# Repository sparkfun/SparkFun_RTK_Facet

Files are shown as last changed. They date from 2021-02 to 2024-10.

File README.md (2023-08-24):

SparkFun RTK Facet
========================================

<table class="table table-hover table-striped table-bordered">
  <tr align="center">
   <td></td>
   <td></td>
  <tr align="center">
    <td><a href="https://www.sparkfun.com/products/20000">SparkFun RTK Facet L-Band (GPS-20000)</a></td>
    <td><a href="https://www.sparkfun.com/products/19029">SparkFun RTK Facet (GPS-19029)</a></td>
  </tr>
</table>

The SparkFun RTK Facet and RTK Facet L-Band are your one stop shop for high precision geolocation and surveying needs. For basic users, it’s incredibly easy to get up and running and for advanced users, the RTK Facet is a flexible and powerful tool. With just a few minutes of setup, the RTK Facet is one of the fastest ways to take centimeter grade measurements. By connecting your phone to the RTK Facet over Bluetooth, your phone can act as the radio link to provide correction data as well as receive the NMEA output from the device. This is exactly how $10,000 surveying devices have been operating for the past decade - we just made it easier, smaller, and a lot cheaper. 

The RTK Facet L-Band utilizes corrections from u-blox's PointPerfect service broadcast from a geosynchronous Inmarsat satellite. The only setup required is a WiFi SSID and password. Once entered, the device will provision itself and periodically (once a month) update the decryption keys necessary to use the PointPerfect service. The price of the RTK Facet L-Band includes a 12-month subscription. Additional years of service can be purchased.

Under the hood of the SparkFun RTK Facet is an ESP32 WROOM connected to a ZED-F9P as well as some peripheral hardware (OLED, LiPo fuel gauge, microSD, etc). Additionally, housed under the dome of the RTK Facet is a surveyor grade L1/L2 antenna. It is the same element found within our GNSS Multi-Band L1/L2 Surveying Antenna.

Under the hood of the SparkFun RTK Facet L-Band is an ESP32 WROOM connected to a ZED-F9P GNSS receiver, a NEO-D9S L-Band receiver (for corrections), and a variety of peripheral hardware (LiPo fuel gauge, microSD, etc). Additionally, housed under the dome of the RTK Facet L-Band is a surveyor grade L1/L2/L-Band antenna. This antenna is a unique combination of elements designed to receive the GNSS signals (L1/L2) alongside the 1.55GHz PointPerfect corrections. The built-in antenna has an ARP of 69mm from the base to the measuring point of the L1 antenna and an ARP of 68mm to the measuring point of the L2 antenna. The RTK Facet L-Band is programmed in Arduino and can be tailored by you to fit whatever your needs may be.

Repository Contents
-------------------

* **/Documents** - Datasheets and additional product information
* **/Hardware** - Eagle PCB files
* **/Labels** - Display overlay and info stickers
* **/Mechanical** - Drawings use to created injection molding tooling

Documentation
--------------

* **[RTK Product Manual](https://docs.sparkfun.com/SparkFun_RTK_Firmware/)** - A detailed guide describing all the various software features of the RTK product line. Essentially it is a manual for the firmware used by the RTK Facet.
* **[RTK Facet L-Band Hookup Guide](https://learn.sparkfun.com/tutorials/sparkfun-rtk-facet-l-band-hookup-guide)** - Hookup guide for the SparkFun RTK Facet L-Band.
* **[RTK Facet Hookup Guide](https://learn.sparkfun.com/tutorials/sparkfun-rtk-facet-hookup-guide)** - Hookup guide for the SparkFun RTK Facet.

License Information
-------------------

This product is _**open source**_! 

Please review the LICENSE.md file for license information. 

If you have any questions or concerns on licensing, please contact technical support on our [SparkFun forums](https://forum.sparkfun.com/viewforum.php?f=152).

Distributed as-is; no warranty is given.

- Your friends at SparkFun.

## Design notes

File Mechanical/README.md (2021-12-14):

## RTK Facet Mechanical Files ##

Contents
-------------------

* **/Drawings** - PDF Mechanical Drawings 
* **/Meshes** - STL and 3MF meshes for enclosure components
* **/Solids** - STEP and IGES solids for enclosure components
* **RTK_Facet_v35_Fusion_360_Archive.f3z** - Archive of the Fusion 360 project for the complete assembly as of v35 (initial release)

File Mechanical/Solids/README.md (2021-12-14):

## RTK Facet Solid Files ##

Contents
-------------------

* **Enclosure_Body** - Base portion of the clamshell enclosure. Injection Molded PA66.
* **Enclosure_Dome** - Lid portion of the clamshell enclosure. Injection Molded PA66.
* **Sock** - Shock/Dust Jacket for enclosure. Pressure Molded Silicone.
* **Thread_Insert** - 5/8-11 Threaded Insert. Machined Brass, Molded in place.

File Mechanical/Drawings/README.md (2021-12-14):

## RTK Facet Mechanical Drawings ##

Contents
-------------------

* **Thread_Insert.pdf** - 5/8-11 Threaded Brass Insert 
* **v35_Complete_Assembly.pdf** - Mechanical Drawings provided to Injection Molding Fab
* **v35_Critical_Dimensions_Nylon.pdf** - Critical Dimensions for PA66 Enclosure Parts
* **v35_Critical_Dimensions_Silicone.pdf** - Critical Dimensions for Silicone Sleeve

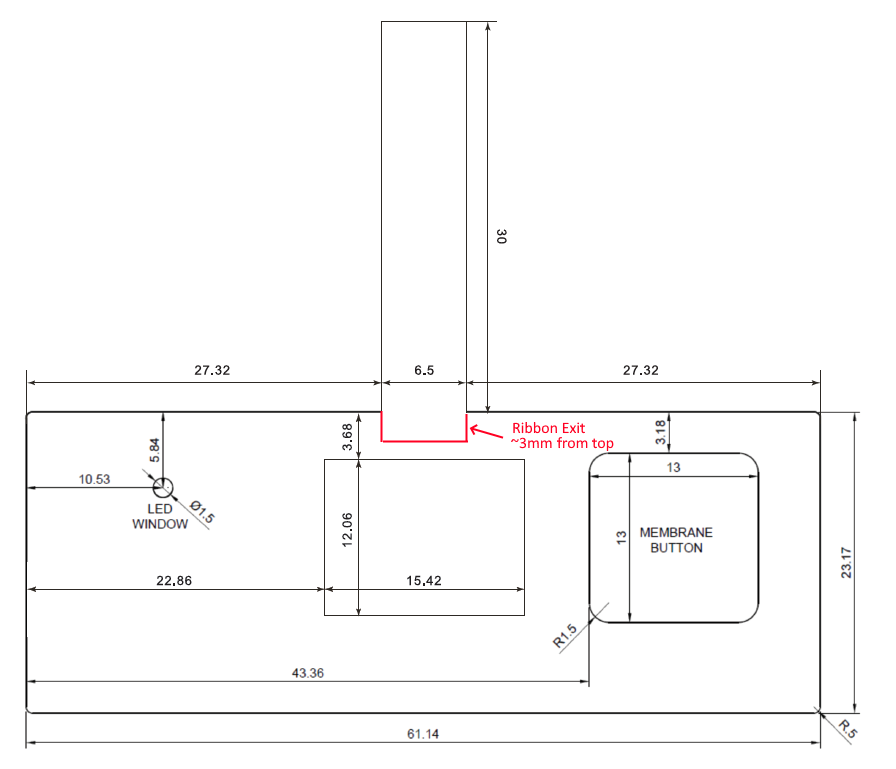
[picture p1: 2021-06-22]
Labels/Display/Ribbon Exit.png

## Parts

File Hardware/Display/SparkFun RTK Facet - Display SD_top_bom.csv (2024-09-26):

Comment | Designator | Footprint | LCSC Part #
OLED0.66-TRIMTRIM | OLED1 | OLED-0.66-64X48-TRIM | C88334
0.1uF | C16 C28 | 603 | C1590
1.0uF | C2 C3 | 805 | C15849
1.0uF | C4 C6 C7 | 603 | C1592
1k | R5 | 603 | C22548
2.2uF | C1 | 805 | C19110
4.7uF | C5 | 1206 | C51205
10k | R2 R3 | 603 | C98220
10uF | C8 | 603 | C19702
100k | R4 | 603 | C14675
390k | R1 | 603 | C863775
FPC_12_0.5MM_BACKFLIP | J1 | FPC_12_DOUBLESIDED_BACKFLIP | C5213751
Green | D1 | LED-1206-BOTTOM | C125106
MICRO-SD-PUSH-PUSH-EXT-PIN | J2 | MICROSD-EXTERNALPIN | C720505
MOMENTARY-SWITCH-SPST-SMD-5.2MM-TALL | S1 | TACTILE_SWITCH_SMD_5.2MM | C318887
6P_1MM-LIF Connector | JP1 | 6P_1MM-LIF Connector | C2915488

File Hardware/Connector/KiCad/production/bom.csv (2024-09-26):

Designator | Footprint | Quantity | Value | LCSC Part #
D1 | SOT23-6 | 1 | DT1042-04SO
F1 | 0805 | 1 | 6V/0.5A/1A
F3 | 1210 | 1 | 6V/2.0A/4.0A
J1, J3 | FPC_0.5mm-12 | 2 | Conn_01x12_FPC_0.5mm
J11, J12 | 1x04 | 2 | Conn_01x04
J2, J9 | JST_SMD_1.25mm-4_Locking | 2 | JST_Locking_4
J4 | JST_SMD_1.0mm-4_RA | 1 | Qwiic
J5 | USB-C_16 | 1 | USB_C_Receptacle
JP0 | Jumper_2_PTH_SMD_Combo-NC | 1 | Measure
R16, R17 | 0603 | 2 | 5.1k

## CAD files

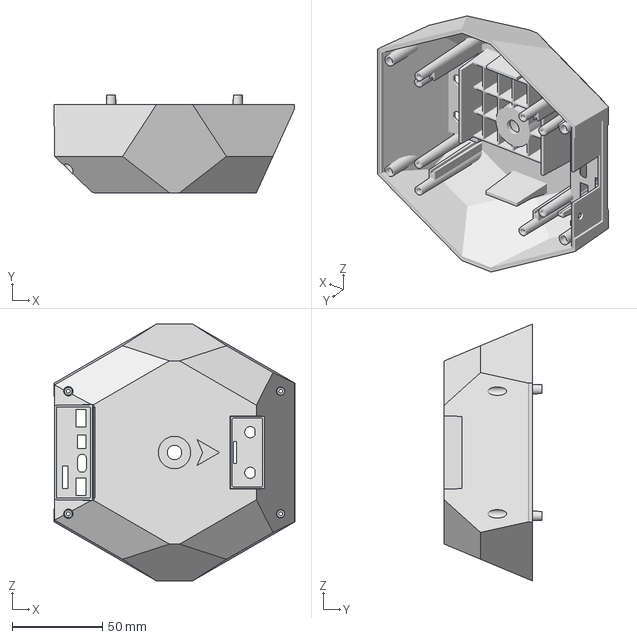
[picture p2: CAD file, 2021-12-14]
Mechanical/Meshes/Enclosure_Body.3mf
133.3 x 54.1 x 142.5 mm

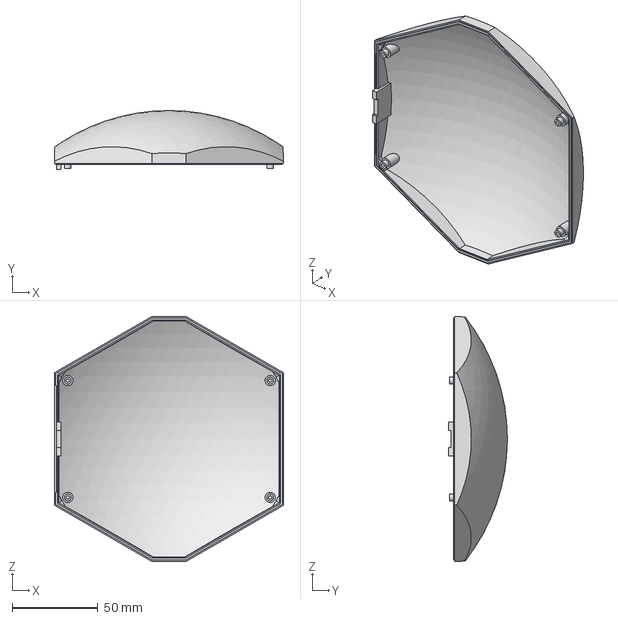
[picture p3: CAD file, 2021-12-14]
Mechanical/Solids/Enclosure_Dome.step
133.3 x 34.3 x 142.5 mm

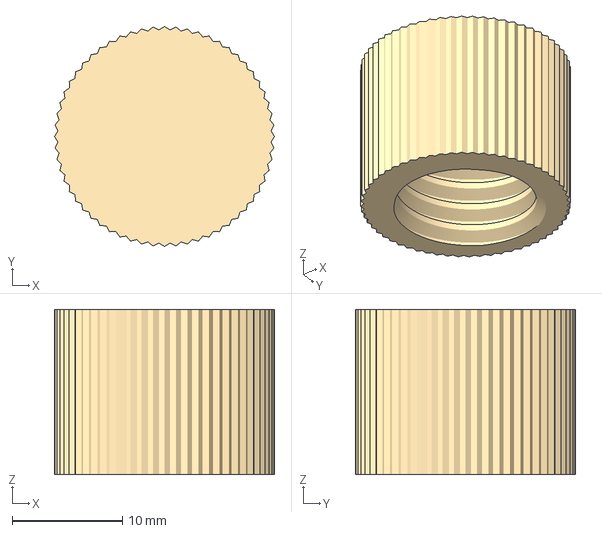
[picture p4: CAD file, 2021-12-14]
Mechanical/Meshes/Thread_Insert.3mf
20.0 x 20.0 x 15.0 mm

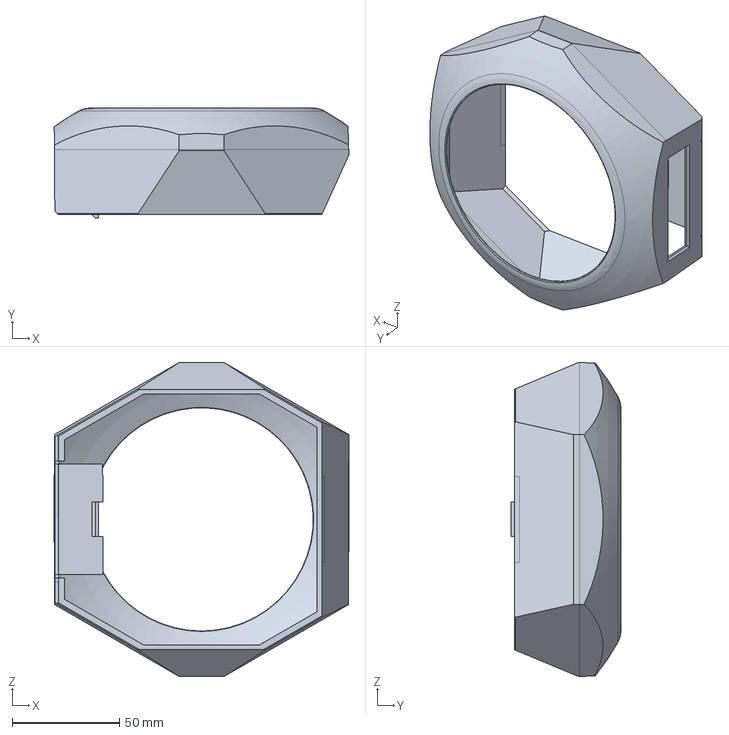
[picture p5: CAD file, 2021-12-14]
Mechanical/Solids/Sock.step
137.2 x 51.1 x 146.3 mm

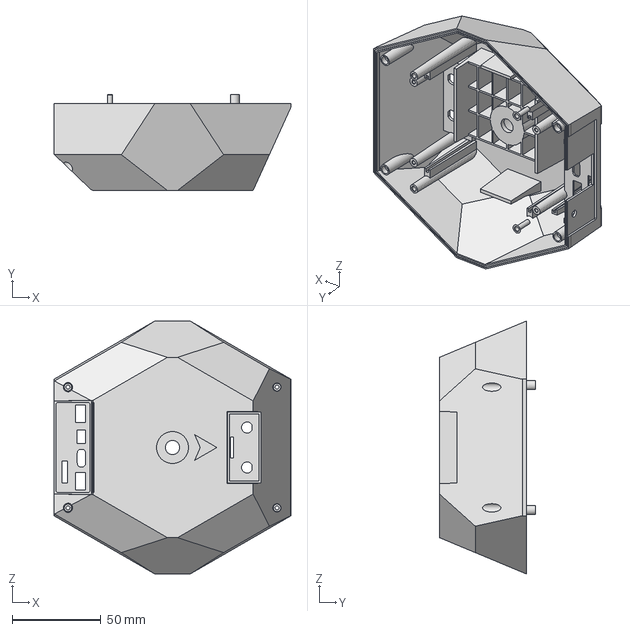
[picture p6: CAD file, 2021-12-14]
Mechanical/Solids/Enclosure_Body.step
133.3 x 54.1 x 142.5 mm

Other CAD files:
Mechanical/Meshes/Sock.3mf
Mechanical/Solids/Thread_Insert.step
Mechanical/Meshes/Enclosure_Dome.3mf
Mechanical/Meshes/Enclosure_Body.stl
Mechanical/Meshes/Enclosure_Dome.stl
Mechanical/Meshes/Sock.stl
Mechanical/Meshes/Thread_Insert.stl
Mechanical/Solids/Enclosure_Body.iges
Mechanical/Solids/Enclosure_Dome.iges
Mechanical/Solids/Sock.iges
Mechanical/Solids/Thread_Insert.iges

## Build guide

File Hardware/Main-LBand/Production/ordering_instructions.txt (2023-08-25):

panel size, 134x188mm
PCB thickness, 1.6mm
number of layers, 4
controlled impedance, JLC7628
material, TG155
soldermask color, Red
silkscreen color, White
oz copper, 1oz
finish, ENIG
stencils, none
pcs per panel, 8
min trace width, 0.1270mm / 0.0050in
min drill size, 0.2000mm / 0.0079in
filename to layer stackup 1/2/3/4: GTL, GL2, GL3, GBL

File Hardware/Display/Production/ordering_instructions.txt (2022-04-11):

panel size, 114x194mm
PCB thickness, 1.6mm
number of layers, 2
soldermask color, Red
silkscreen color, White
oz copper, 1oz
finish, ENIG
stencils, none
pcs per panel, 16
min trace width, 0.1778mm / 0.0070in
min drill size, 0.3810mm / 0.0150in

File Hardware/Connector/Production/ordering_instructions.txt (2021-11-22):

panel size, 121x199mm
PCB thickness, 1.6mm
number of layers, 2
soldermask color, Red
silkscreen color, White
oz copper, 1oz
finish, HASL lead free
stencils, none
pcs per panel, 14
min trace width, 0.1778mm / 0.0070in
min drill size, 0.3000mm / 0.0118in

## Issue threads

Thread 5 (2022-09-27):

Redesign housing to support Slant Measurements

tonycanike, 2022-09-27:
### My Workbench

Facet 19029  (the one before the carrying case)

### Feature Request
Redesign the Facet housing to support slant measurements of height above the mark.  It's physically impossible to measure directly with a tape measure from a survey mark to the reference point of the GNSS housing (the bottom) when using standard survey tripods (heavy duty "legs", not a pole or bipod setup) due to the width of the head on standard survey tripods.

This is an issue with most commercial survey-grade GNSS receivers.  Many commercial survey-grade GNSS receivers provide a secondary measurement mark for "slant measurements", where the tape is held at an angle from the survey mark on the ground to the edge of the diameter of the GNSS receiver.   Many commercial survey data collectors allow the input of
a. the slant measurement - the length of the tape at an angle from the survey mark to the "slant" mark on the edge of the receiver.
b. the offset from the slant measurement to the phase center or bottom reference mark (I forget which at the moment.)
c. the diameter of the receiver at the slant measurement mark.
and the data collector uses a simple triangle formula to calculate the actual height of the antenna phase center above the survey mark on the ground.

Specifically, this includes
1. Increase diameter to allow a tape measure to run in a straight line from the mark to the case.  Standard survey tripods ("legs", not a pole or bipod setup) have a wide head and the current housing diameter is to small - one needs to bend the tape.
2. Put a slant mark on the housing (that the rubber bumper moves around needs to be resolved.)
3. Published diameter of the housing at the slant mark
4. Publish the vertical offset from the slant mark to the APC/ARF (both, probably best).

****OR**** it might be easier to just use a thin round disk of sheet metal with sufficient diameter between the Facet and the Tripod and slant measure to that.  Hmmm.    Similar to https://www.sparkfun.com/products/17519 (ground plane) but with a hole large enough for the 5/8x11 tripod screw.

### References

https://www.ngs.noaa.gov/AERO/Genspecs_A/Volume%20A_Attachment%2011-19.pdf
(Multiple docs in this PDF, Scroll down to "Attachment 13" page 3)

https://web.carlsonsw.com/files/knowledgebase/kbase05.php?action=display_topic&topic_id=1042

https://kb.unavco.org/kb/article/introduction-to-gnss-antenna-set-up-methods-for-campaigns-71.html

tonycanike, 2023-04-18:
Here's a great diagram:
https://www.e-education.psu.edu/geog862/node/1853

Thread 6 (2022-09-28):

Facet screw holes are too narrow for many small screwdrivers.

tonycanike, 2022-09-28:
The screw holes for the screws that hold the Facet (GPS-19029) housing together are too narrow to allow most of my small screwdrivers to reach the screw.  These are screw drivers that properly fit the screw heads.

This is important as I need to open the case in the field to retrieve lost SD cards.

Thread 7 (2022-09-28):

USB Connector too close to SD Card Slot

tonycanike, 2022-09-28:
It's very difficult to insert and remove SD cards when there is a cable plugged into the USB-C connector.  There just isn't a lot of room for fingers to grasp the tiny SD card.

I have two GPS-19029 Facets.

tonycanike, 2022-10-26:
Updated:  microSD cards have a little ridge to catch the card with a fingernail, but the card slot is too close to the side wall of the recess in the case to get a finger in there to catch the card with a fingernail.

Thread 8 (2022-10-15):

Facet rests on and bends USB cable when on a table

tonycanike, 2022-10-15:
Performing logging tests here on the firmware.   Have the Facet plugged into power.  Sitting on my kitchen table at a tilt because it is resting it's weight on the USB cable.

I spend more time learning, debugging, and upgrading this device than actually using it.  Therefore having it on my desk with a USB cable plugged in for power or serial   _IS IN FACT_  my primary use case :)

T.

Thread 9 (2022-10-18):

Add indicator for "External Power Connected"

tonycanike, 2022-10-18:
The green power indicator LED on the FACET only shows when the battery is charging due to external power being supplied.

It would be very useful to have an indicator to show when external power is connected, regardless of the state of the internal battery.

When setting up the base for a long work day, it is often necessary to connect external power, especially if using RTK radios, more especially if the radios are transmitting at more power than 100mW.   It is important to be able to confirm that the external power is properly connected to ensure the work day will not be interrupted.

Currently, if the internal battery is fully charged, there is no indicator to confirm that the external power is connected properly.  If the user thinks the external power is properly connected, but it actually is not, the base will shutdown midday due to the internal battery depleting, interrupting RTK work and static collection.

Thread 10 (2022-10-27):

Add highly visible indicator that logging to SD is active.

tonycanike, 2022-10-27:
Add a highly-visible indicator, observable from below, which shows that logging writes to the SD card are happening.

Static logging is a long-term operation, 2, 4, or even 8 hours.  It is important to be able to verify that logging is actually happening after the Facet is setup.  It is disheartening to find a setting was misconfigured or even the SD card wasn't properly inserted.

While the logging icon on the OLED display is very useful, the OLED display is often not visible.

1.  It is very common to have a GNSS receiver up on a 2m pole.  It's not uncommon for the pole to be on a mark that is projecting 0.2m above the ground.  That puts the OLED display over 2.2m up in the air, well above eye level for most people.
2. The OLED display is easily washed out in bright sunshine.
3. The OLED display is slightly recessed, making it harder to read from low vertical angles.  This is good as it protects the display, but the logging icon in in the lower part of the display.

Many commercial survey GNSS receivers use a bright blinking LED to indicate that logging is active.   The LED is visible in sunshine and visible from a low vertical angle.

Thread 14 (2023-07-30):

Front Panel should be on the North side

tonycanike, 2023-07-30:
The front panel - the man-machine interface (MMI) - should be on the north side of the unit, with respect to the antenna calibration.

Almost universally, GNSS receivers are calibrated with the MMI being the north reference point.  It is confusing to surveyors that the Sparkfun units are an exception to this widely-followed convention. The unique orientation of the Facets makes it more likely that surveyors will mis-align the Facet when setting up a base or collecting static data.

Besides convention, there is a good reason for having the MMI on the north of the receiver.

The sun, for people in the north hemisphere, doesn't shine from the north.  If the MMI is on the north side of the GNSS receiver, it is easier to read and less likely to be washed out by the sunshine.  There are more people living in the north vs the south hemisphere, so putting the MMI on the north side of the receiver maximizes the MMI visibility for more people.

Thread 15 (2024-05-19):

Radio and Data JST connectors appear incorrectly drawn on External Connector Board schematic

tonycanike, 2024-05-19:
As linked to from the Facet product page
   https://www.sparkfun.com/products/19984
I'm looking at
   https://cdn.sparkfun.com/assets/d/2/a/b/0/SparkFun_RTK_Facet_-_External_Connector_Schematic.pdf
With a rev date in the title block of "12/3/2021 11:58am" and a version of "V12".

In the section of the schematic showing what I believe to be the JST Radio and Data connectors, I have the following observations:

1. I believe the "Serial Config, NMEA Out" connector is what the hookup guide calls the "Data" connector, but this isn't explicit.

2. The hookup guide doesn't mention using the Data connector for Serial Configuration.  I always use the USB-C for serial configuration. The schematic calls it a "Serial Config..." connector.

3. Why are there two "Serial Config, NMEA Out" connectors on the schematic with the pin numbers flipped?

4. I believe the "External Radio, RTCM In/Out" connector to be the "Radio" connector as described in the hookup guide.  Not explicit but close enough to be obvious.

5. Why are there two "External Radio, RTCM In/Out" connectors on the schematic with the pin numbers flipped?

6. According to the hookup guide, the V+ pin on both the radio and the data connector are current limited by a PTC to 600ma.  Do both connectors share the same PTC (F1) ?  That is, is the sum of the V+ current provided by the data and radio connectors limited to 600mA? This isn't explicit in the hookup guide and the schematic is unclear on this point.

I'm able to make the cables I need using the info in the hookup guide, so the issue is not an impediment for me.

PaulZC, 2024-05-20:
Hi Tony (@tonycanike ),

Apologies. That schematic certainly isn't as clear as it could be...

On the dual connectors issue: J2 and J9 are the actual JST connectors; J12 and J11 are 4-way 0.1" pitch pads for test purposes. With hindsight, J12 and J11 should have been flipped so the pad numbers match the JST connectors. Here is the radio connector - the pads of J9 are red, the pads of J11 are green:

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

The radio connector (J9) TX and RX pins are connected to the ZED-F9P UART2 and nowhere else. They can be used for an external radio module and carry RTCM data. Pin 1 provides power and is protected by a 6V 0.5A resettable fuse. On the connector schematic, the power rail is labelled as V_BATT, but it is actually the output of the soft power switch circuit on the main board. The input to the soft power circuit is the battery and USB - combined via protection diodes. With USB connected, V_BATT will be around 4.7V. With USB disconnected, V_BATT will be lower, typically 3.9V depending on the battery voltage.

The "Serial Config, NMEA Out" connector (J2) is indeed the Data connector. Apologies for the confusing label. The power on pin 1 is regulated 3.3V from the main board. I don't see a fuse in that connection. The hookup guide may need updating here. The TX and RX pins are fed by the multiplexer on the main board, the 'mode' (UART, PPS, I2C, ADC) is set in software. When the multiplexer is set to monitor the ESP32 <-> ZED-F9P UART1 signals, it is best to regard both TX and RX as outputs. You can't use the RX pin to inject data to the ZED, you can only use it to monitor what data the ESP32 is sending to the ZED. The TX pin allows you to monitor the full data stream from the ZED to the ESP32, the ESP32 forwards this to Bluetooth, ESP-Now, and WiFi and logs to SD as needed.

I hope this helps - and hasn't confused you further! Let us know if you need a better explanation or if anything is still unclear.

Best wishes,
Paul

tonycanike, 2024-05-20:
@PaulZC , thank you, that helps a lot!  Now I understand.   And it's here for others to reference.

Appreciate your time,
Tony.

Closed 2024-05-20.

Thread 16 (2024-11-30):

About Hardware and Firmware Help

Jewinn, 2024-11-30:
I am creating a product based on RTK Facet, what hardware for GNSS antennas is needed for integration? Additionally, tell me what to do for firmware installation and what to do if I want to make modifications to the firmware after assembling the PCB according to the hardware file that was provided.

nseidle, 2024-12-02:
Very exciting!

Any L1/L2 GNSS antenna should work. The Facet uses a U.FL connector on the board and provides 3.3V to the antenna.

To compile RTK Firmware, see [these docs](https://docs.sparkfun.com/SparkFun_RTK_Firmware/firmware_update/#compiling-source).

The [RTK Firmware](https://github.com/sparkfun/SparkFun_RTK_Firmware/tree/main) checks an [ADC pin at boot](https://github.com/sparkfun/SparkFun_RTK_Firmware/blob/main/Firmware/RTK_Surveyor/Begin.ino#L51) for a pair of resistors. Depending on the value, it can identify what device if present. You can either leave the hardware largely unchanged and mimic the feature set of the RTK Facet, or if you make hardware changes (move pins, add devices, etc) then you will need to add your own resistor pair value and add the functions to the firmware to support those new/added devices.

Note that most of our development is over on [RTK Everywhere](https://github.com/sparkfun/SparkFun_RTK_everywhere_Firmware). This codebase has more features but requires an ESP32 with internal PSRAM (ie, ESP32 WROVER, ESP32 Pico with PSRAM, etc).

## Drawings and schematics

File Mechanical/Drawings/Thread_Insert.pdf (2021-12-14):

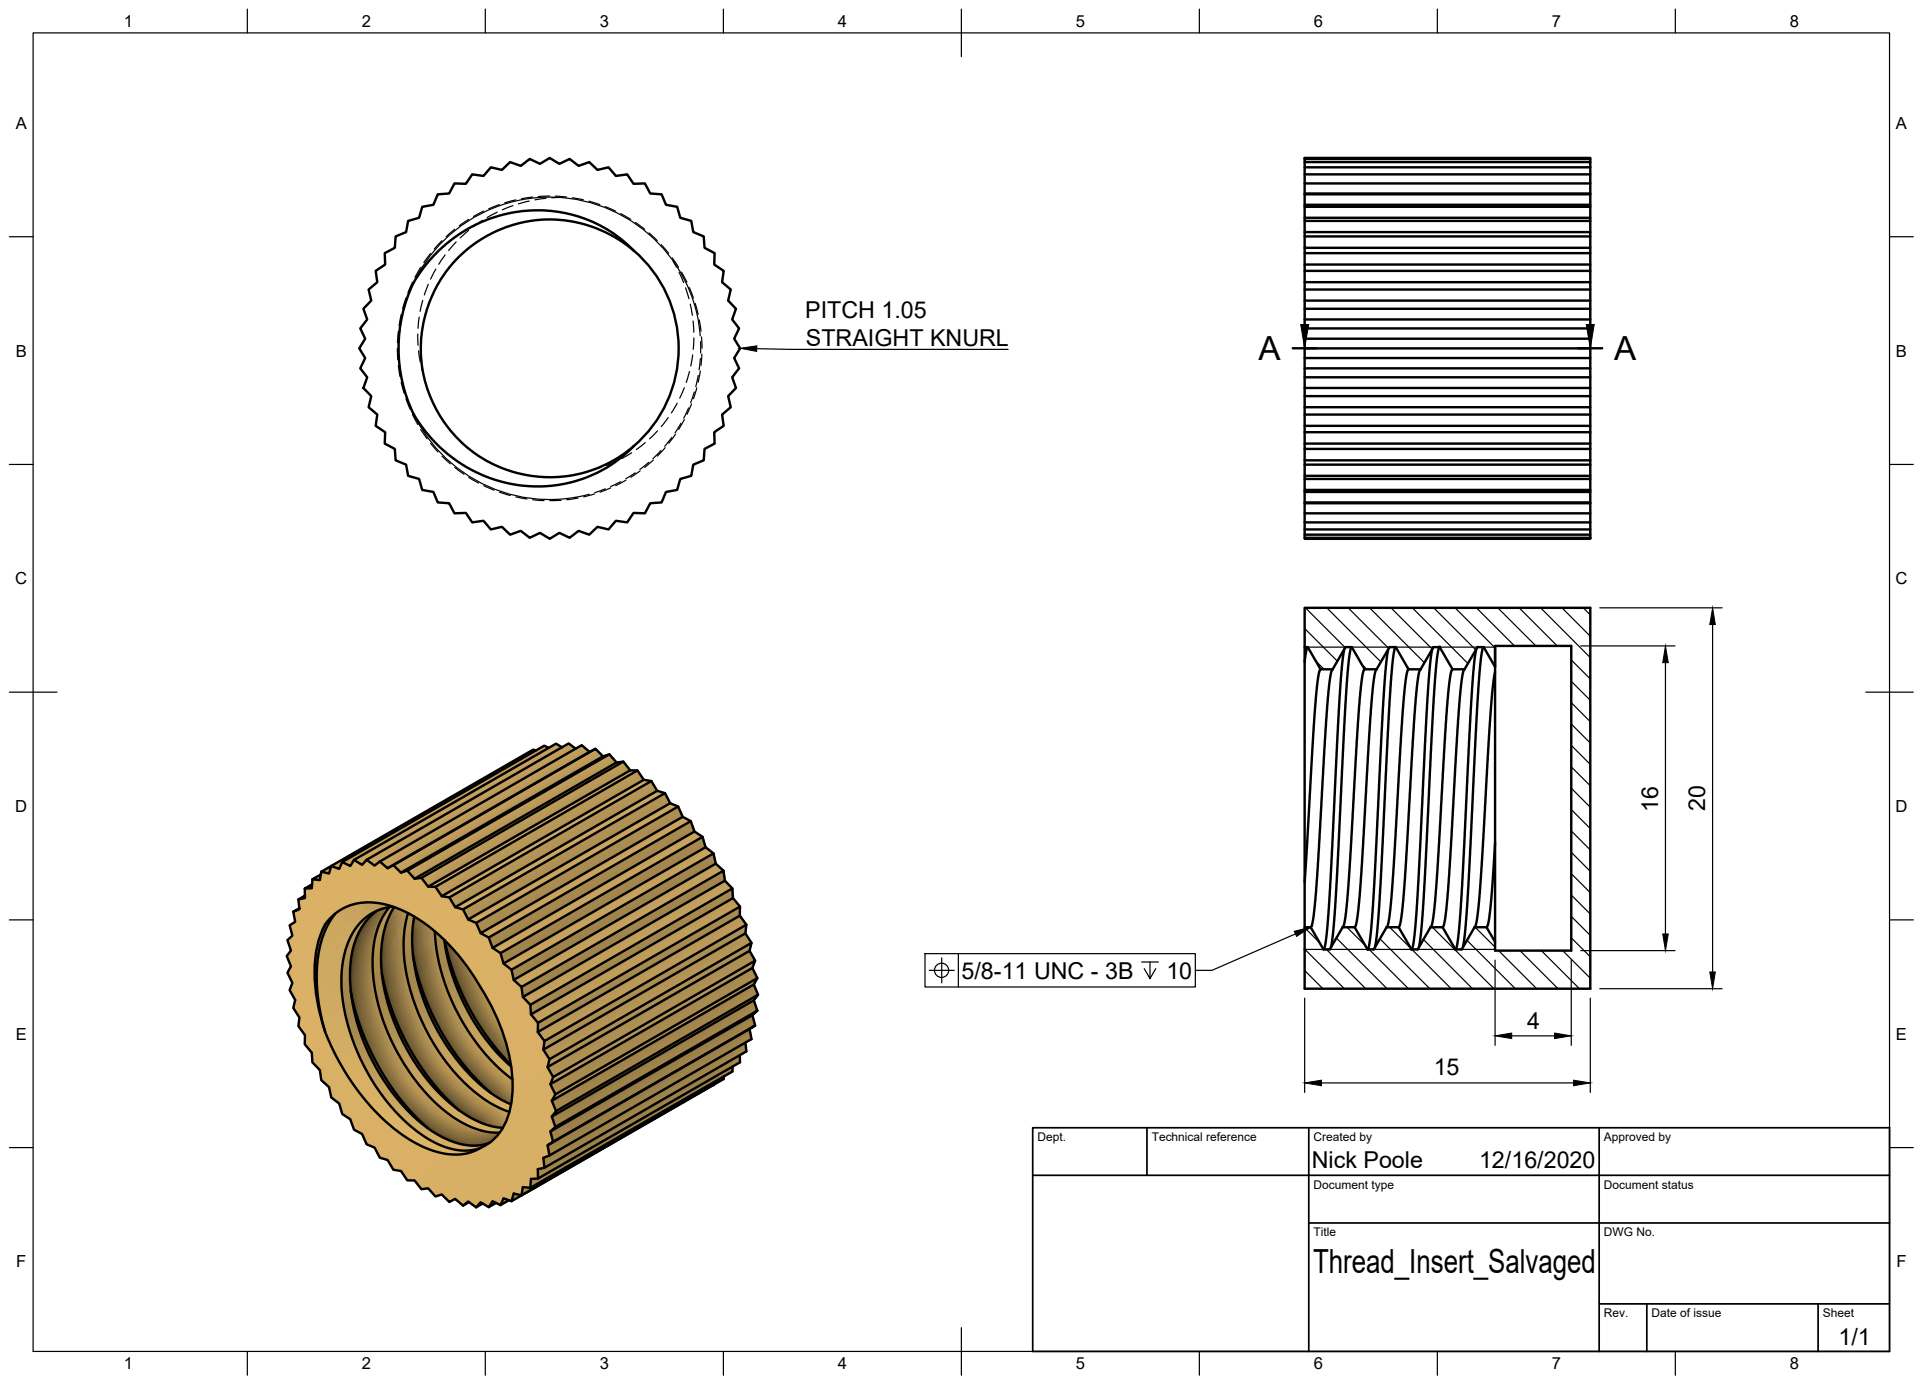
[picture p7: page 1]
Title; DWG No.; Rev.; Date of issue; Sheet; 5/8-11 UNC - 3B; PITCH 1.05 STRAIGHT KNURL

Dept. | Technical reference | Created by Nick Poole 12/16/2020 | Approved by

Document type | Document status

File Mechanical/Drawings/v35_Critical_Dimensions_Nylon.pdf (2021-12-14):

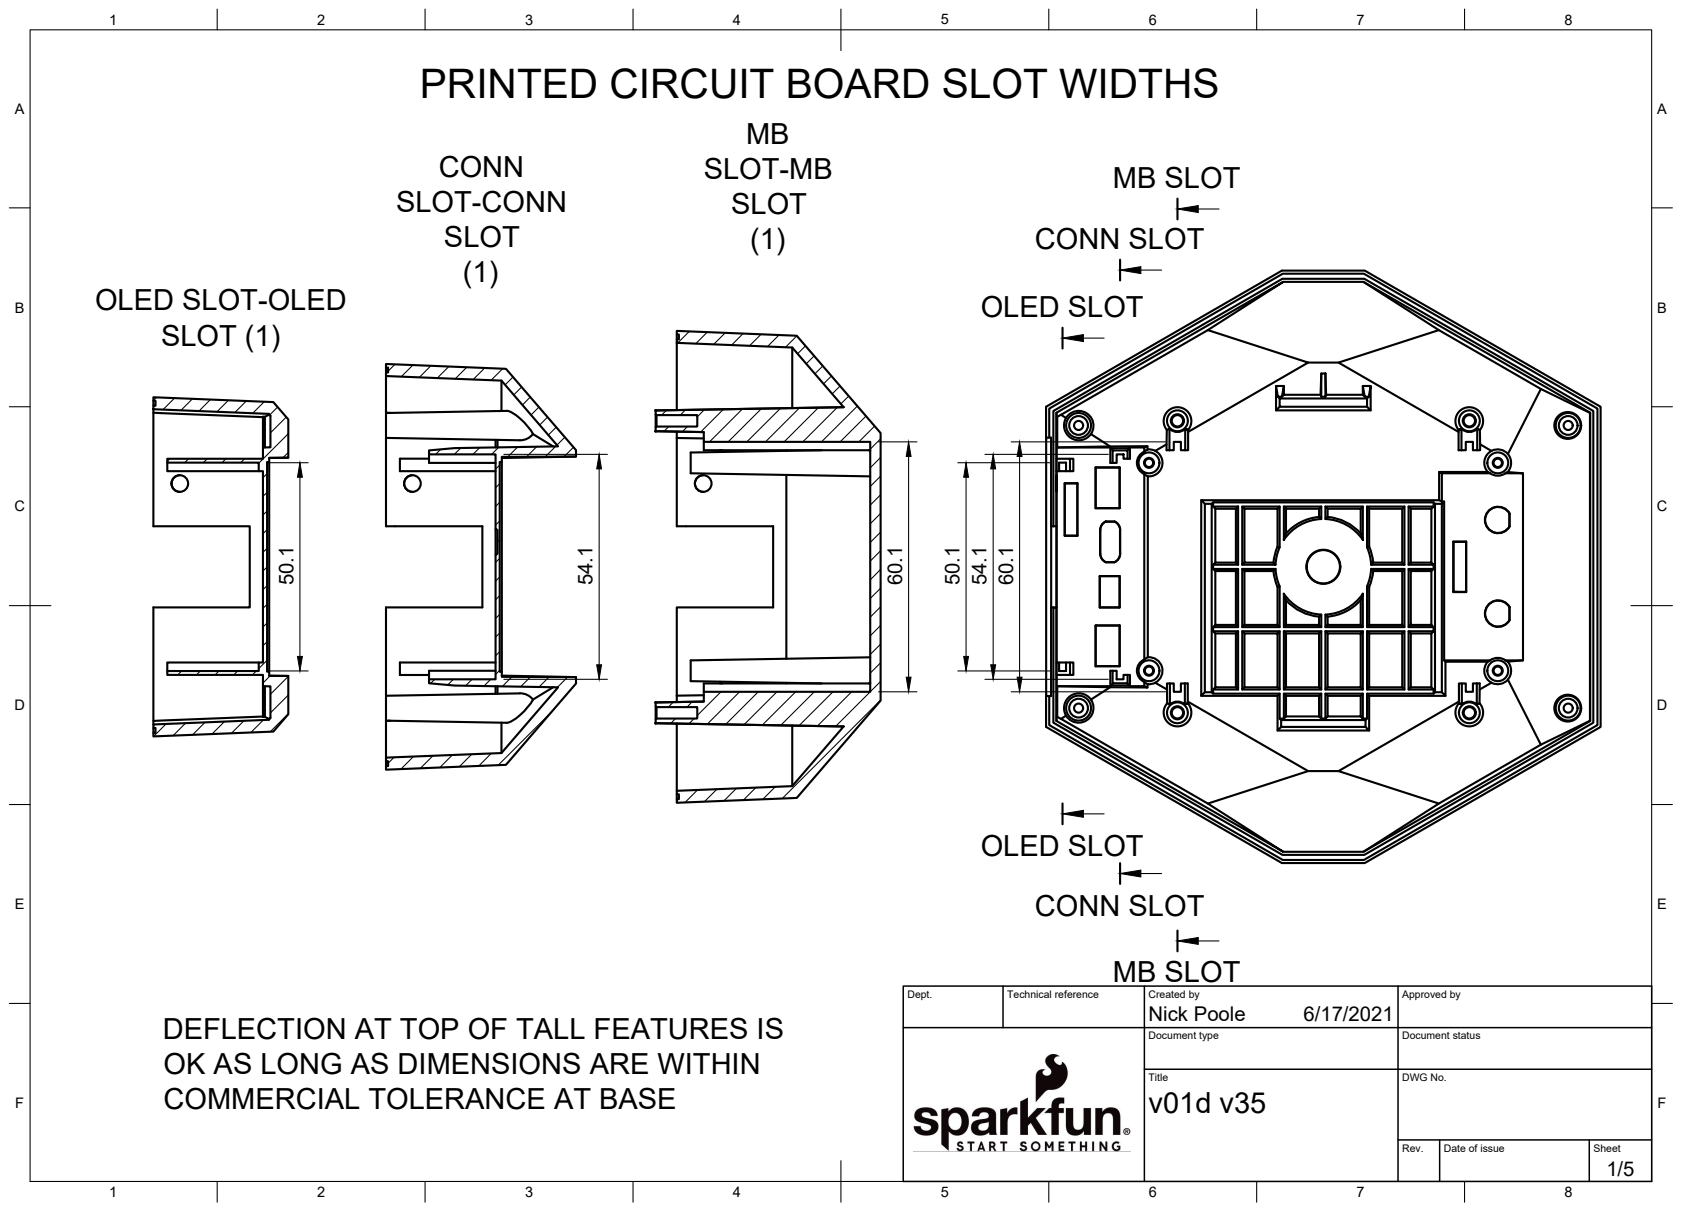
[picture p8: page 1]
MB SLOT; CONN SLOT; OLED SLOT; SLOT (1) 50.1; Title; DWG No.; Rev.; Date of issue; Sheet

PRINTED CIRCUIT BOARD SLOT WIDTHS

OLED SLOT-OLED

Dept. | Technical reference | Created by Nick Poole 6/17/2021 | Approved by

DEFLECTION AT TOP OF TALL FEATURES IS
OK AS LONG AS DIMENSIONS ARE WITHIN
COMMERCIAL TOLERANCE AT BASE

Document type | Document status

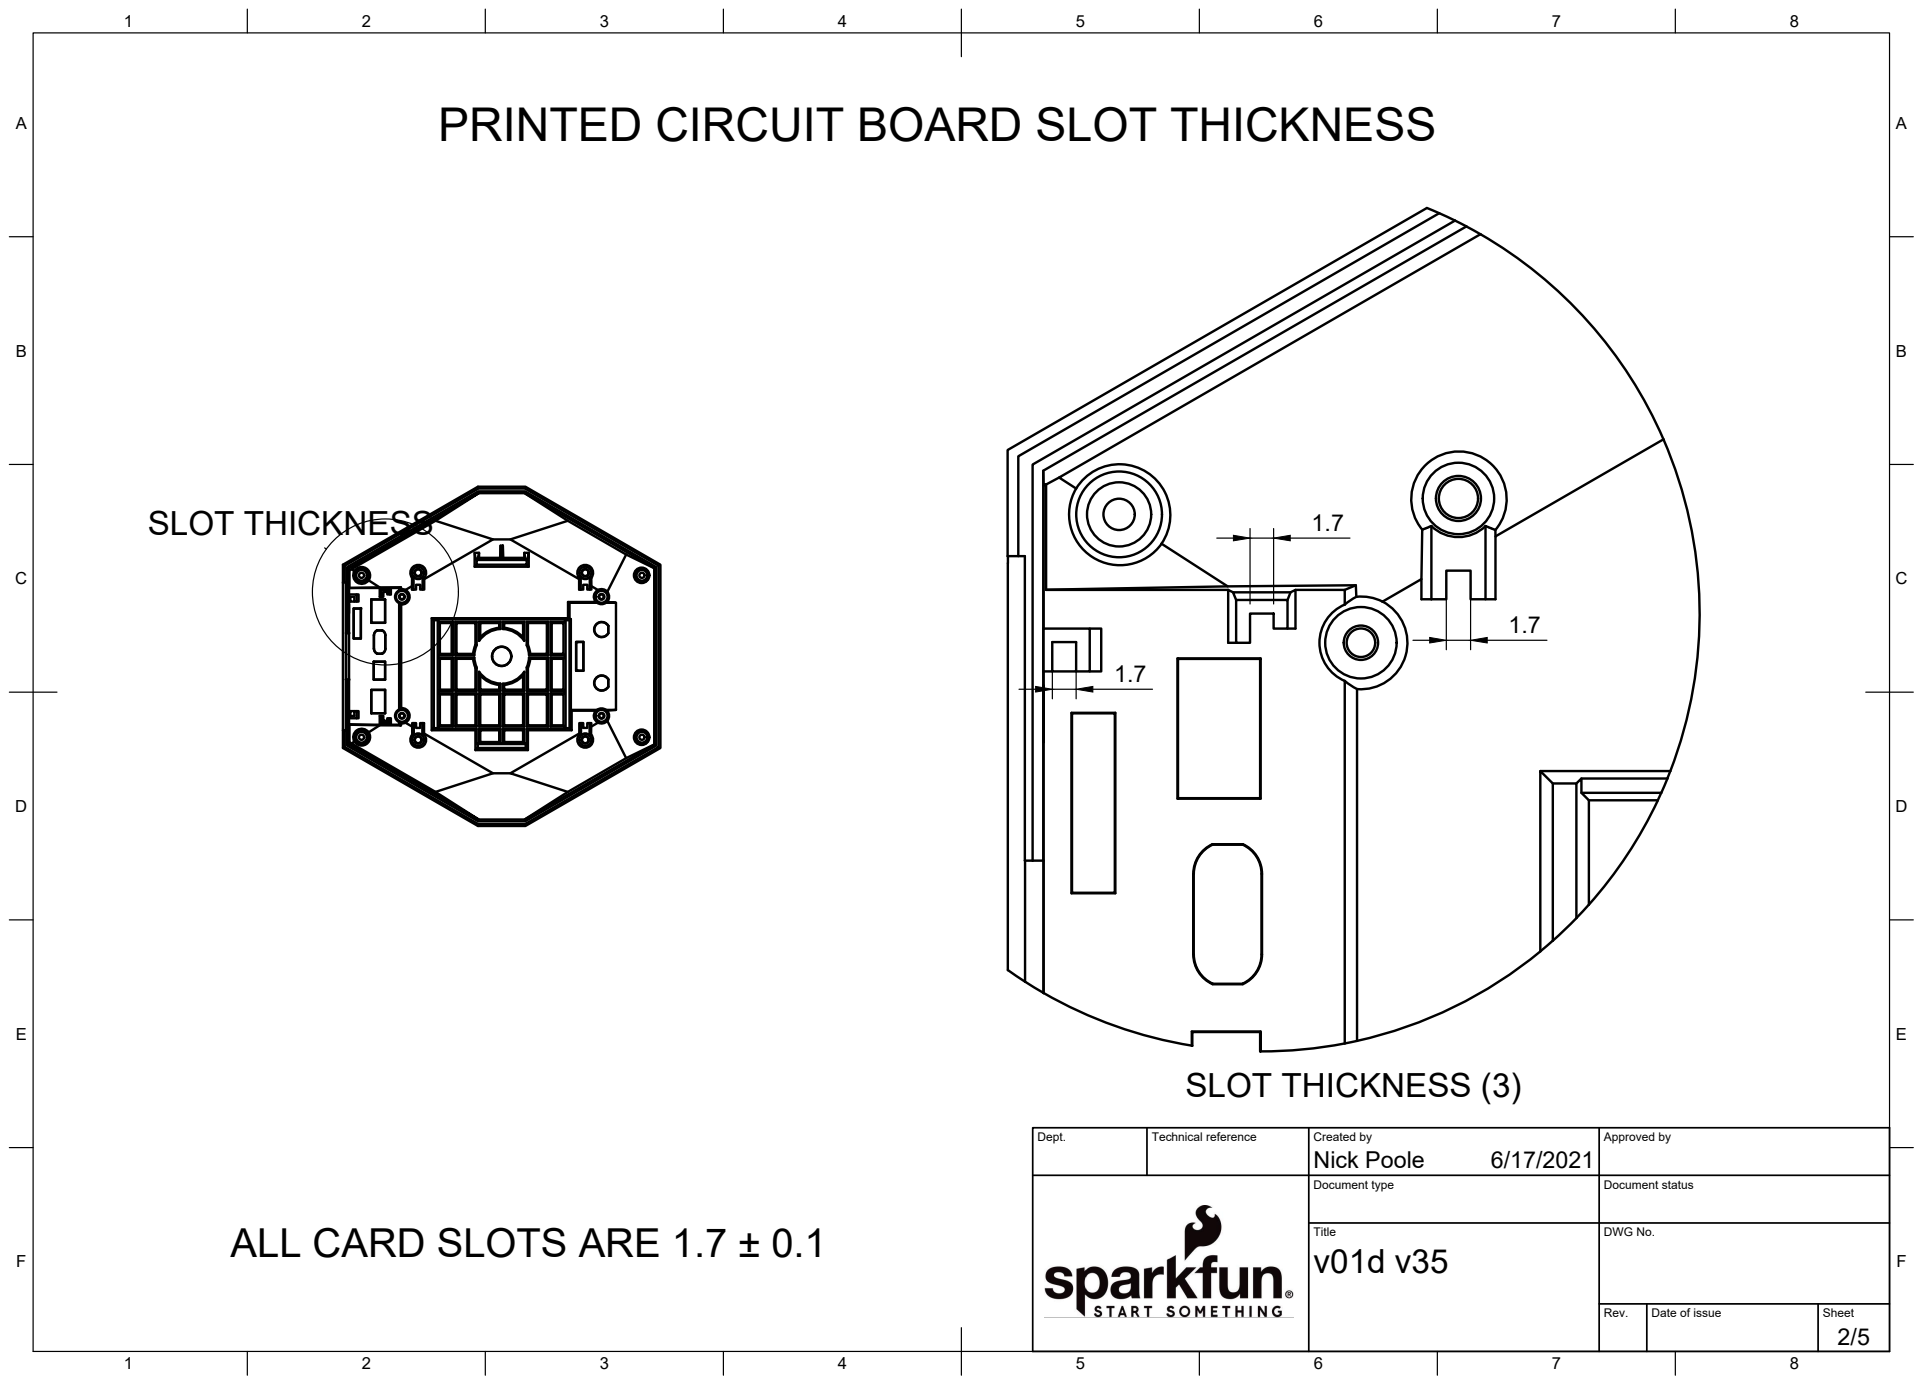
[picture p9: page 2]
SLOT THICKNESS; SLOT THICKNESS (3); Title; DWG No.

PRINTED CIRCUIT BOARD SLOT THICKNESS

Dept. | Technical reference | Created by Nick Poole 6/17/2021 | Approved by

Document type | Document status

ALL CARD SLOTS ARE 1.7 ± 0.1

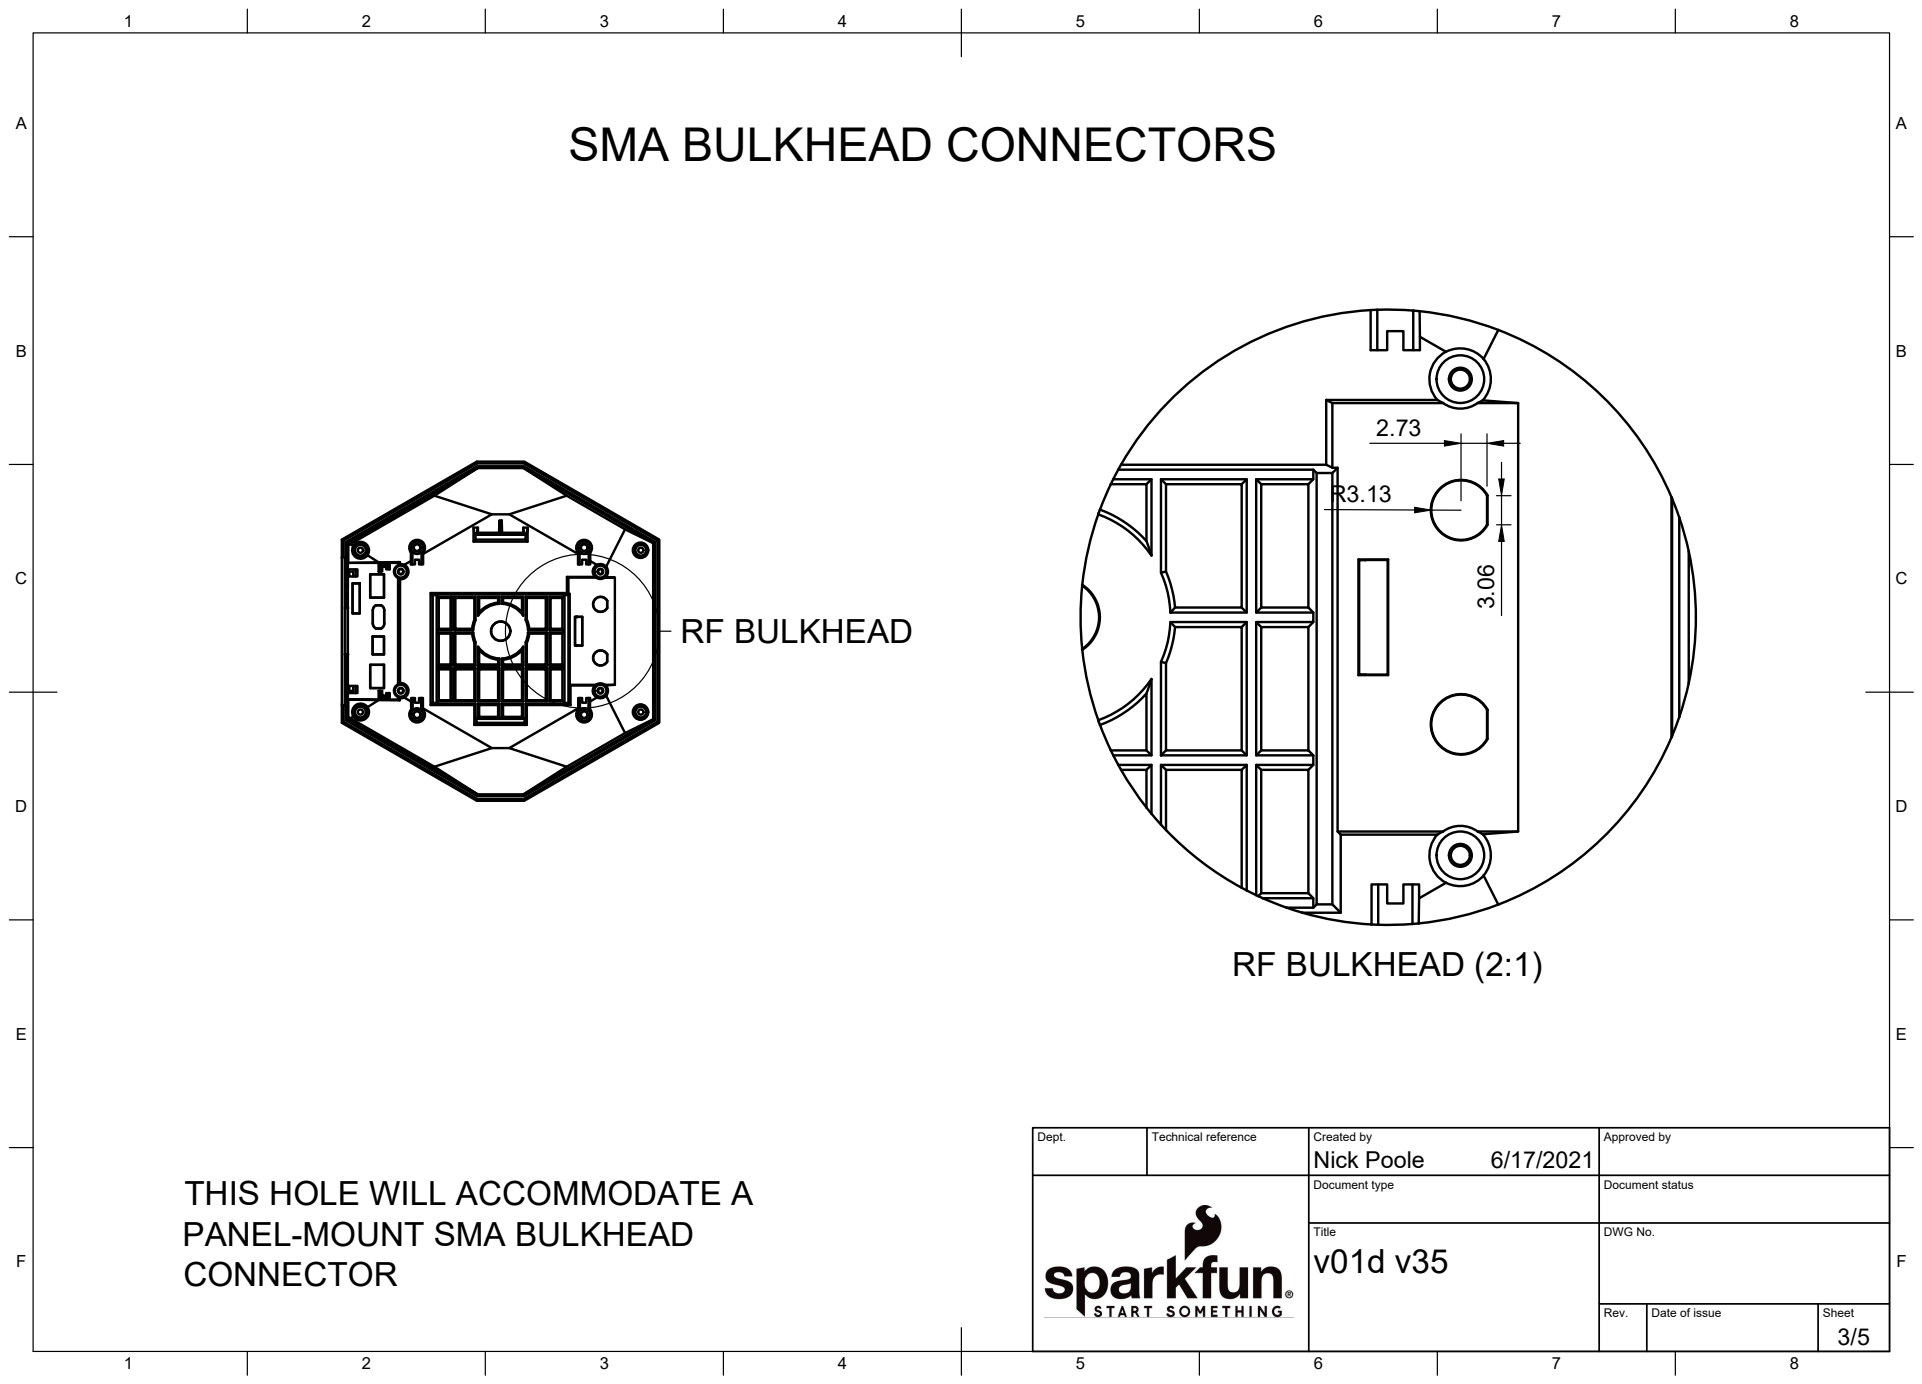
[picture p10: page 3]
RF BULKHEAD; RF BULKHEAD (2:1); Title; DWG No.

SMA BULKHEAD CONNECTORS

Dept. | Technical reference | Created by Nick Poole 6/17/2021 | Approved by

THIS HOLE WILL ACCOMMODATE A
PANEL-MOUNT SMA BULKHEAD
CONNECTOR

Document type | Document status

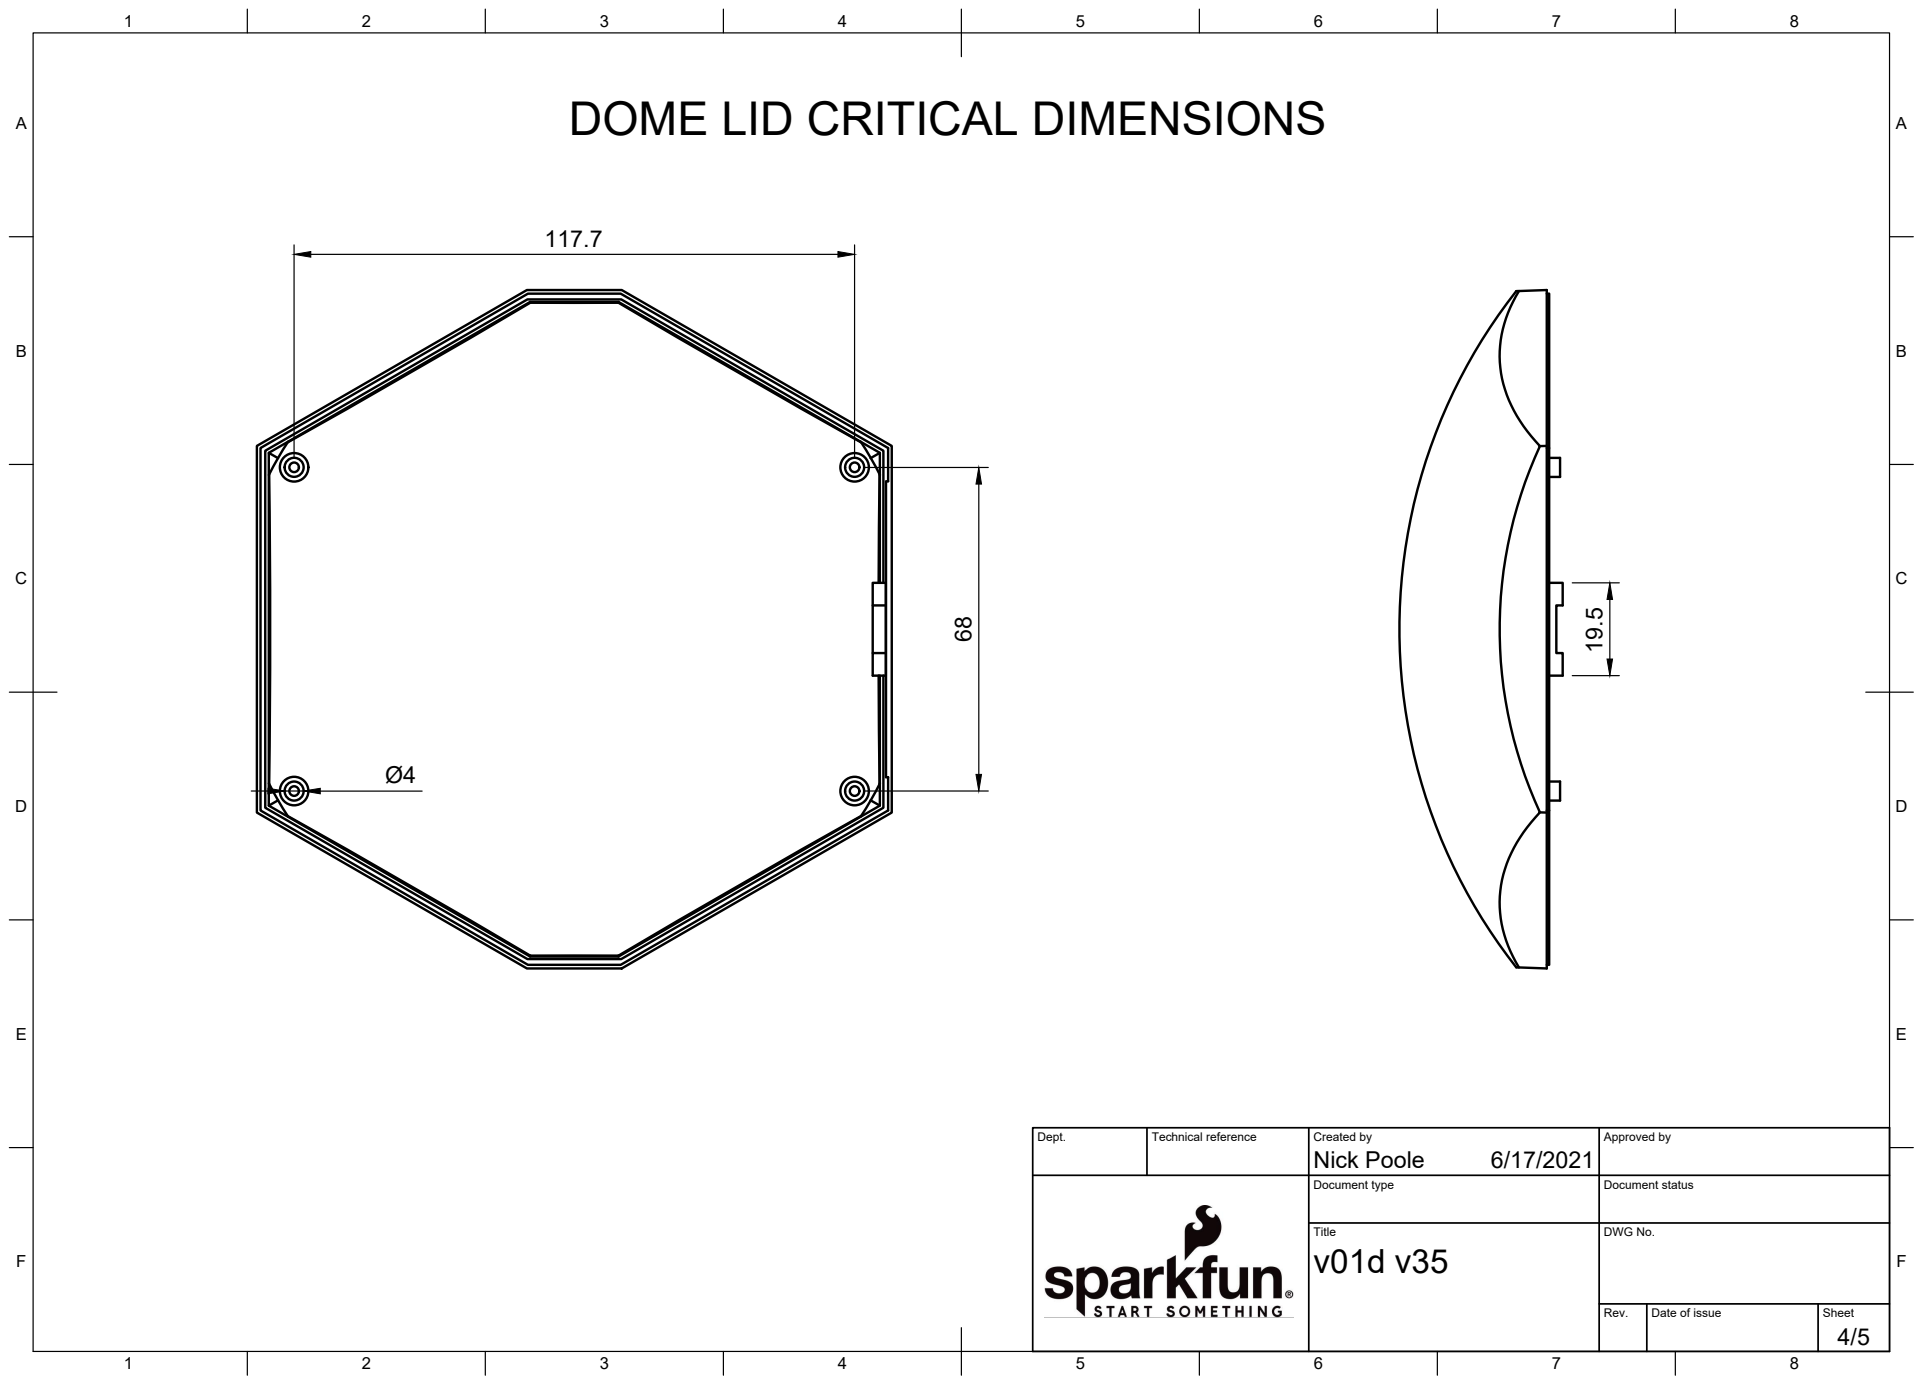
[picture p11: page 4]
Title; DWG No.

DOME LID CRITICAL DIMENSIONS

Dept. | Technical reference | Created by Nick Poole 6/17/2021 | Approved by

Document type | Document status

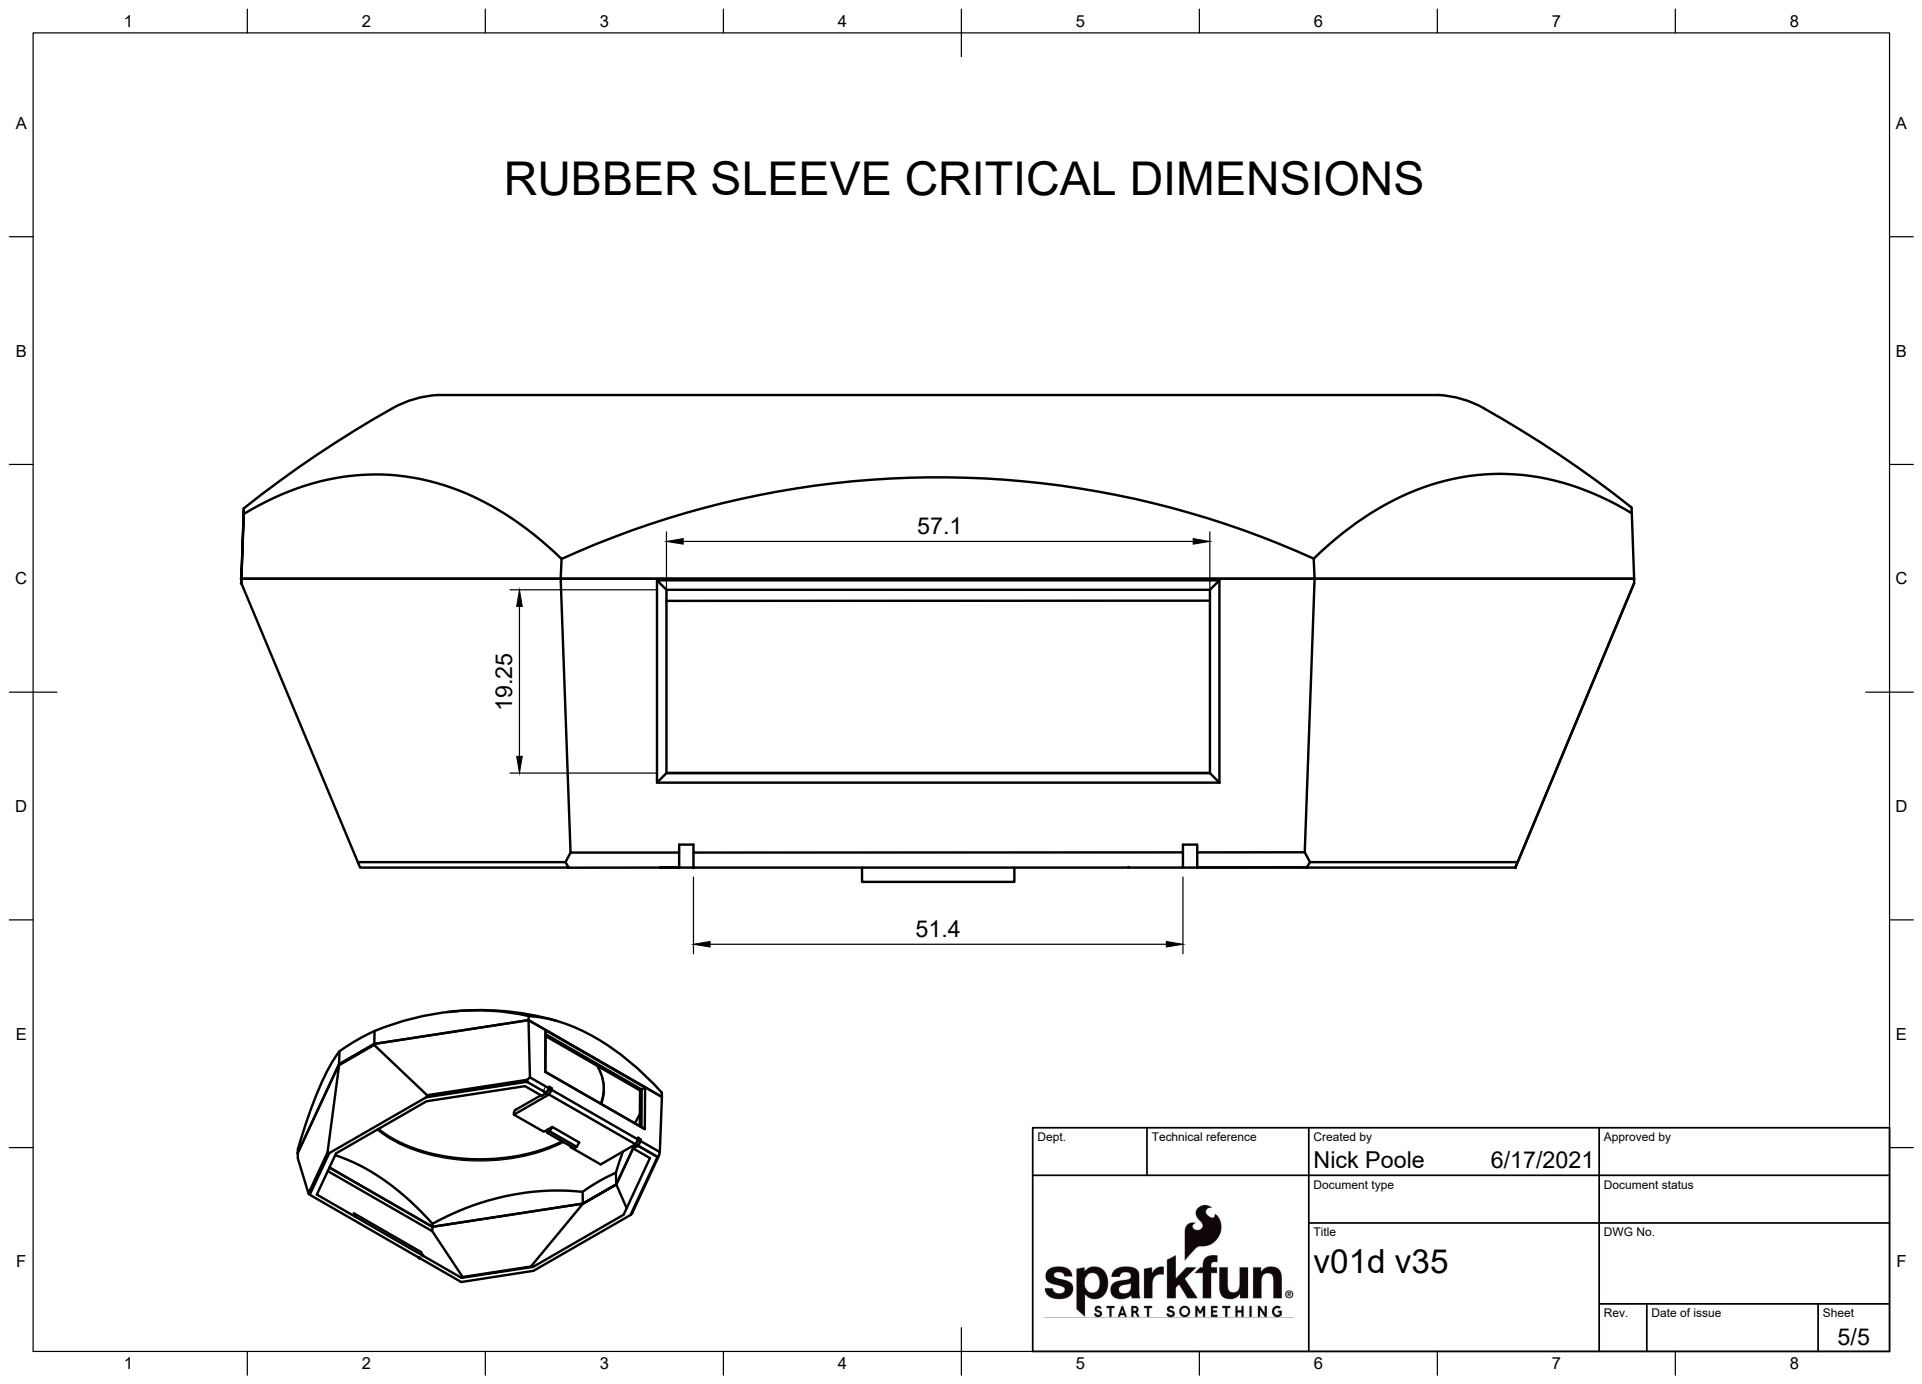
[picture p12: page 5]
Title; DWG No.

RUBBER SLEEVE CRITICAL DIMENSIONS

Dept. | Technical reference | Created by Nick Poole 6/17/2021 | Approved by

Document type | Document status

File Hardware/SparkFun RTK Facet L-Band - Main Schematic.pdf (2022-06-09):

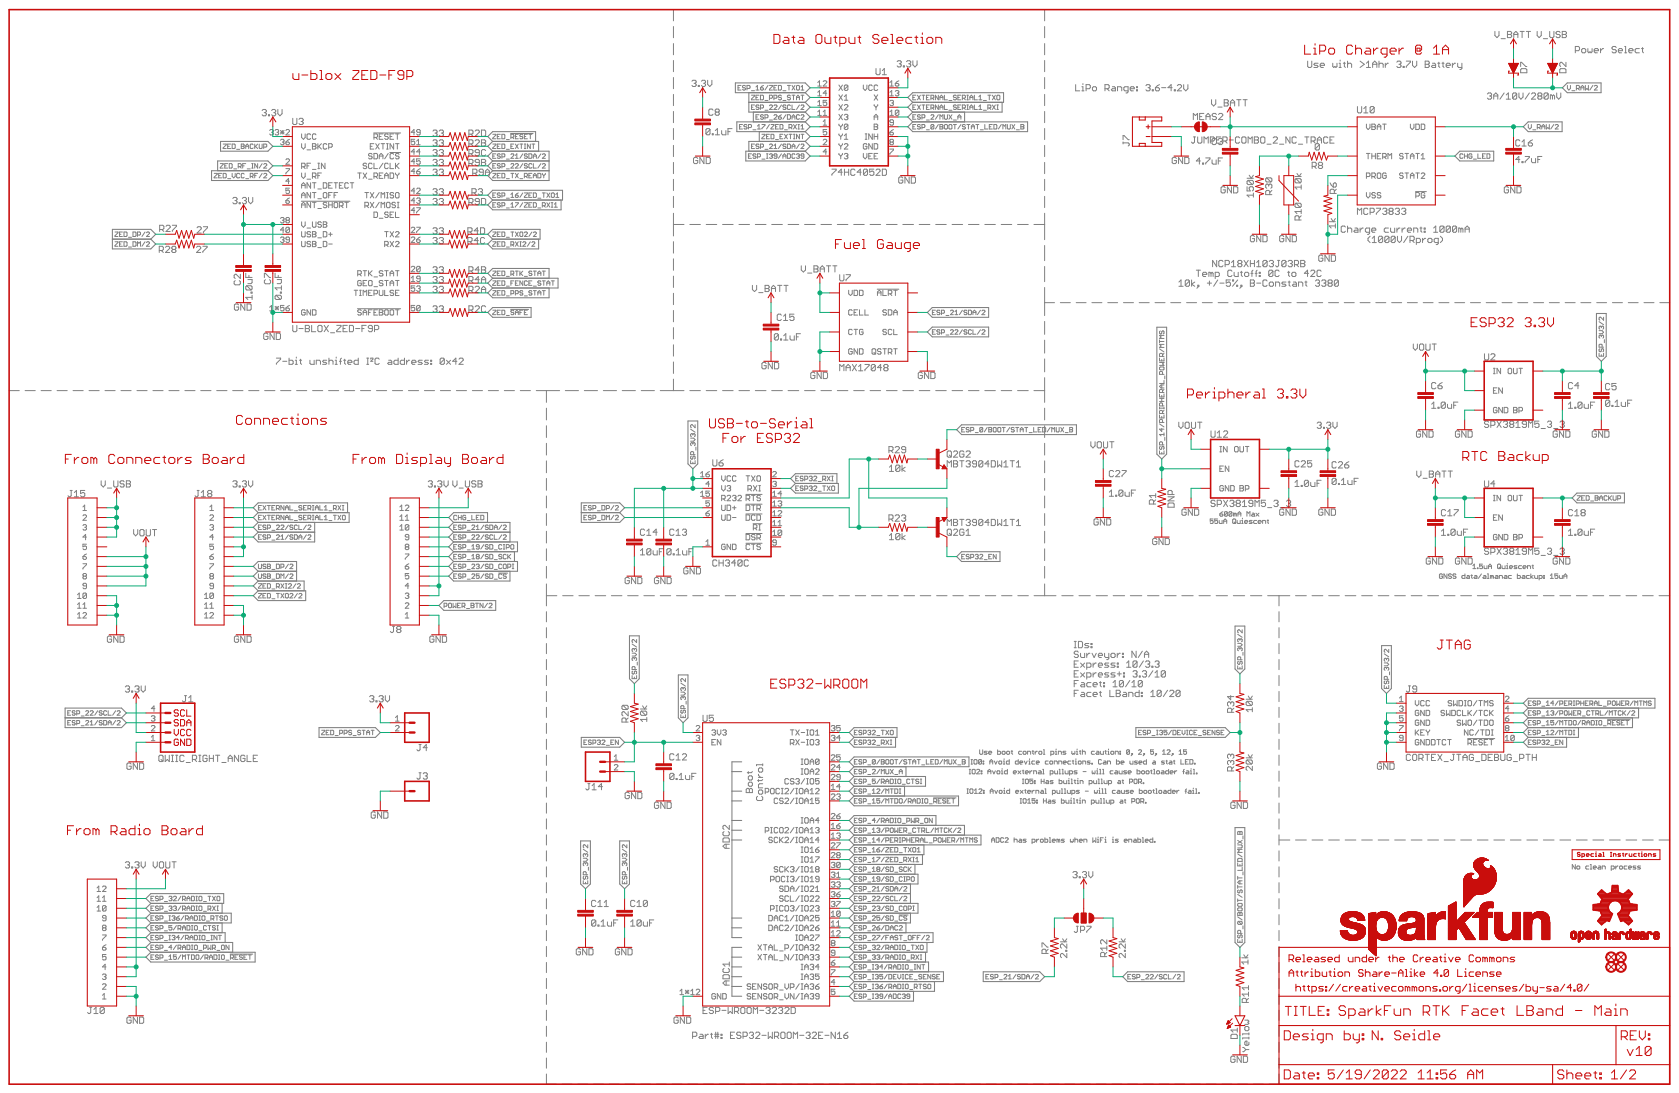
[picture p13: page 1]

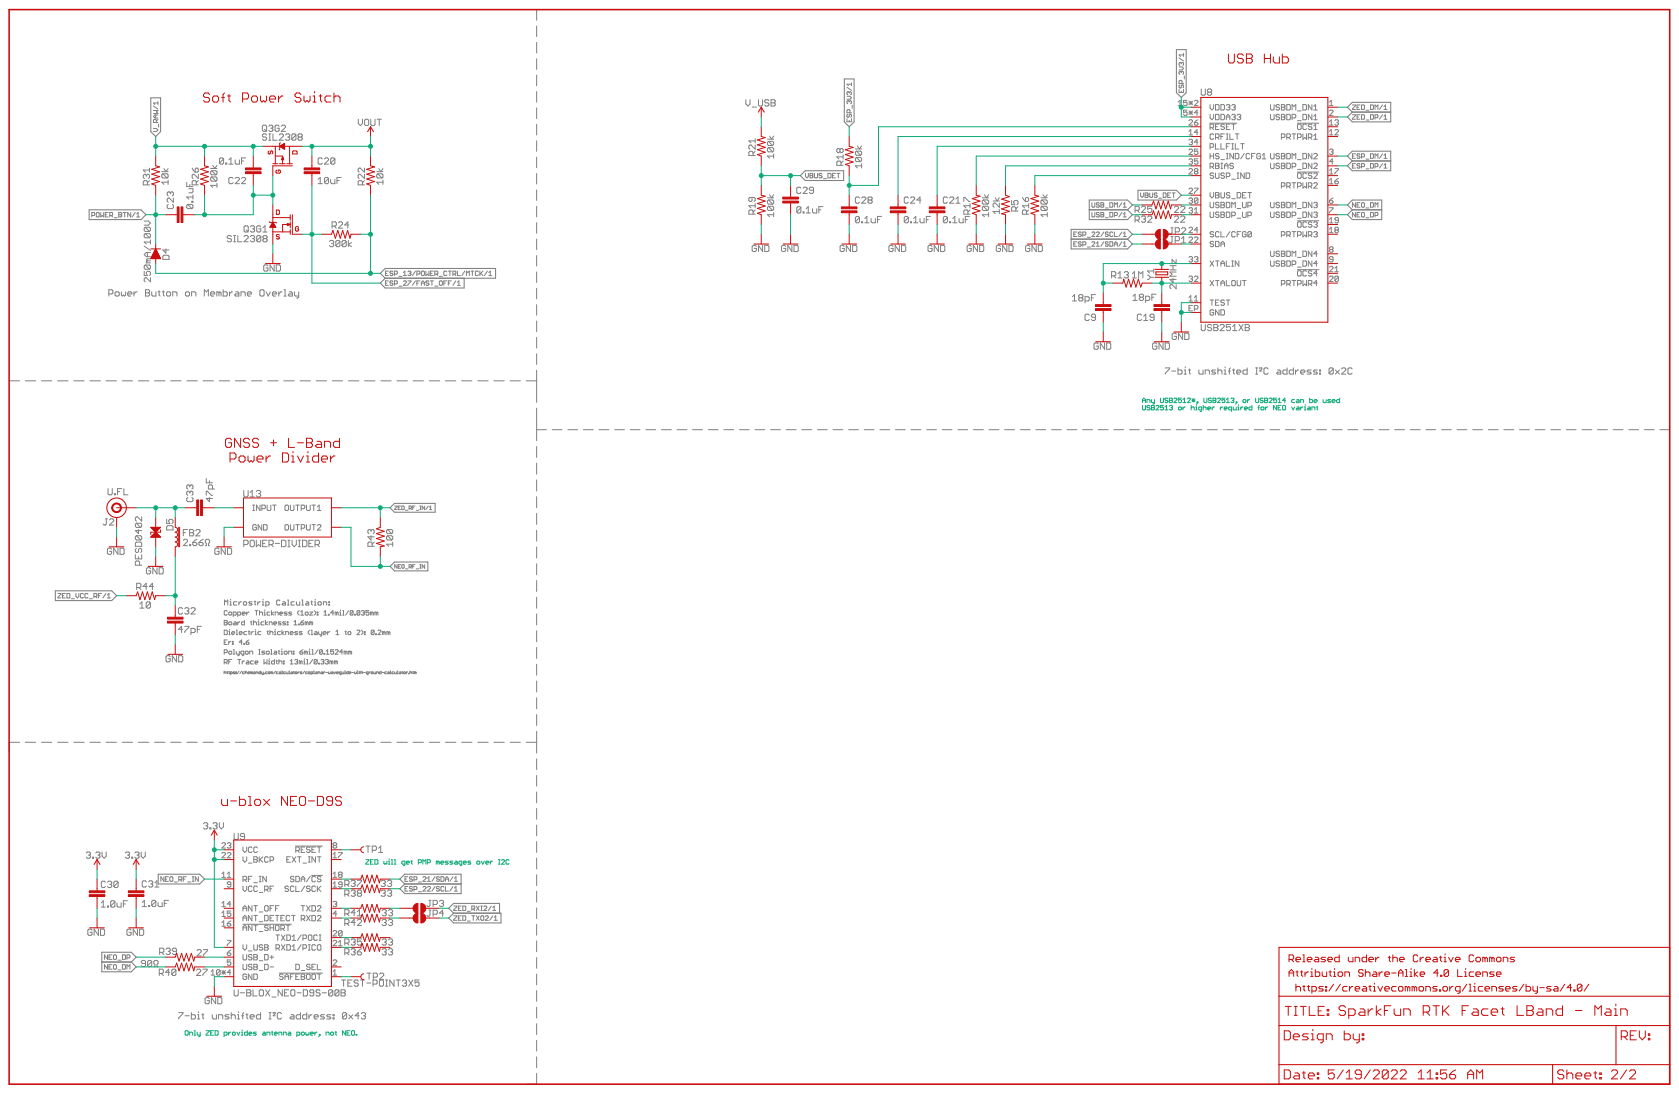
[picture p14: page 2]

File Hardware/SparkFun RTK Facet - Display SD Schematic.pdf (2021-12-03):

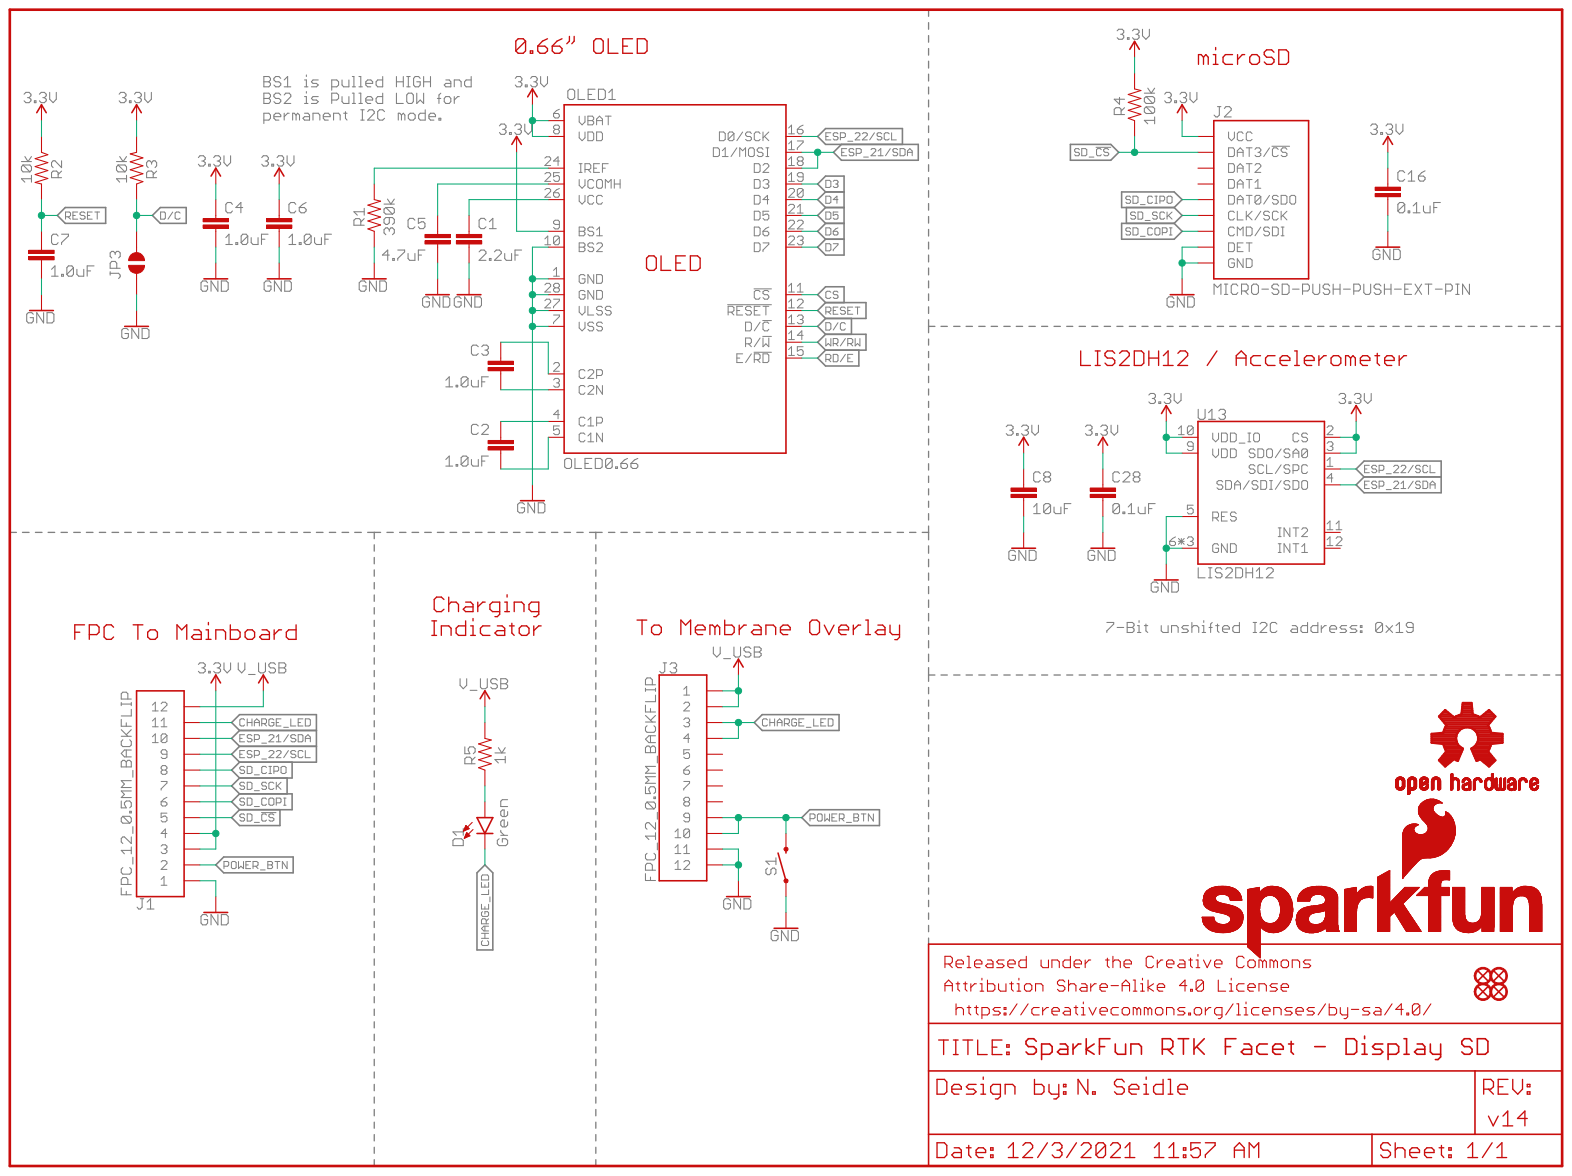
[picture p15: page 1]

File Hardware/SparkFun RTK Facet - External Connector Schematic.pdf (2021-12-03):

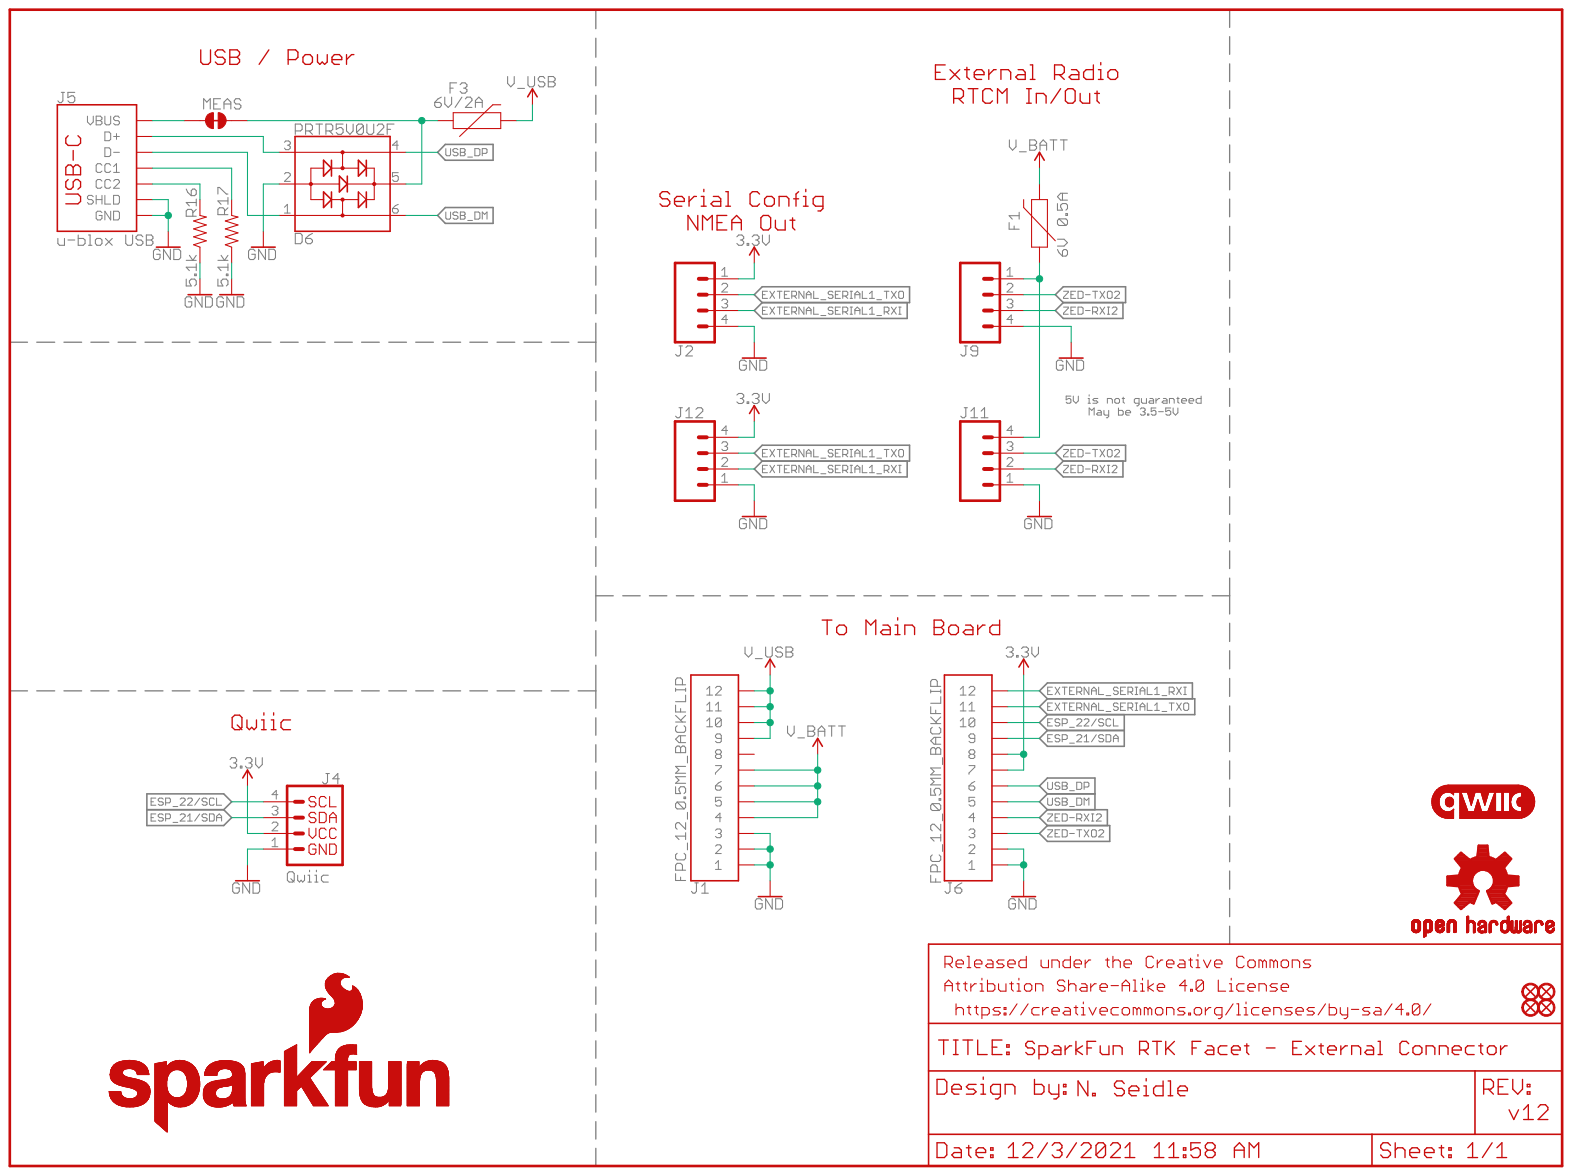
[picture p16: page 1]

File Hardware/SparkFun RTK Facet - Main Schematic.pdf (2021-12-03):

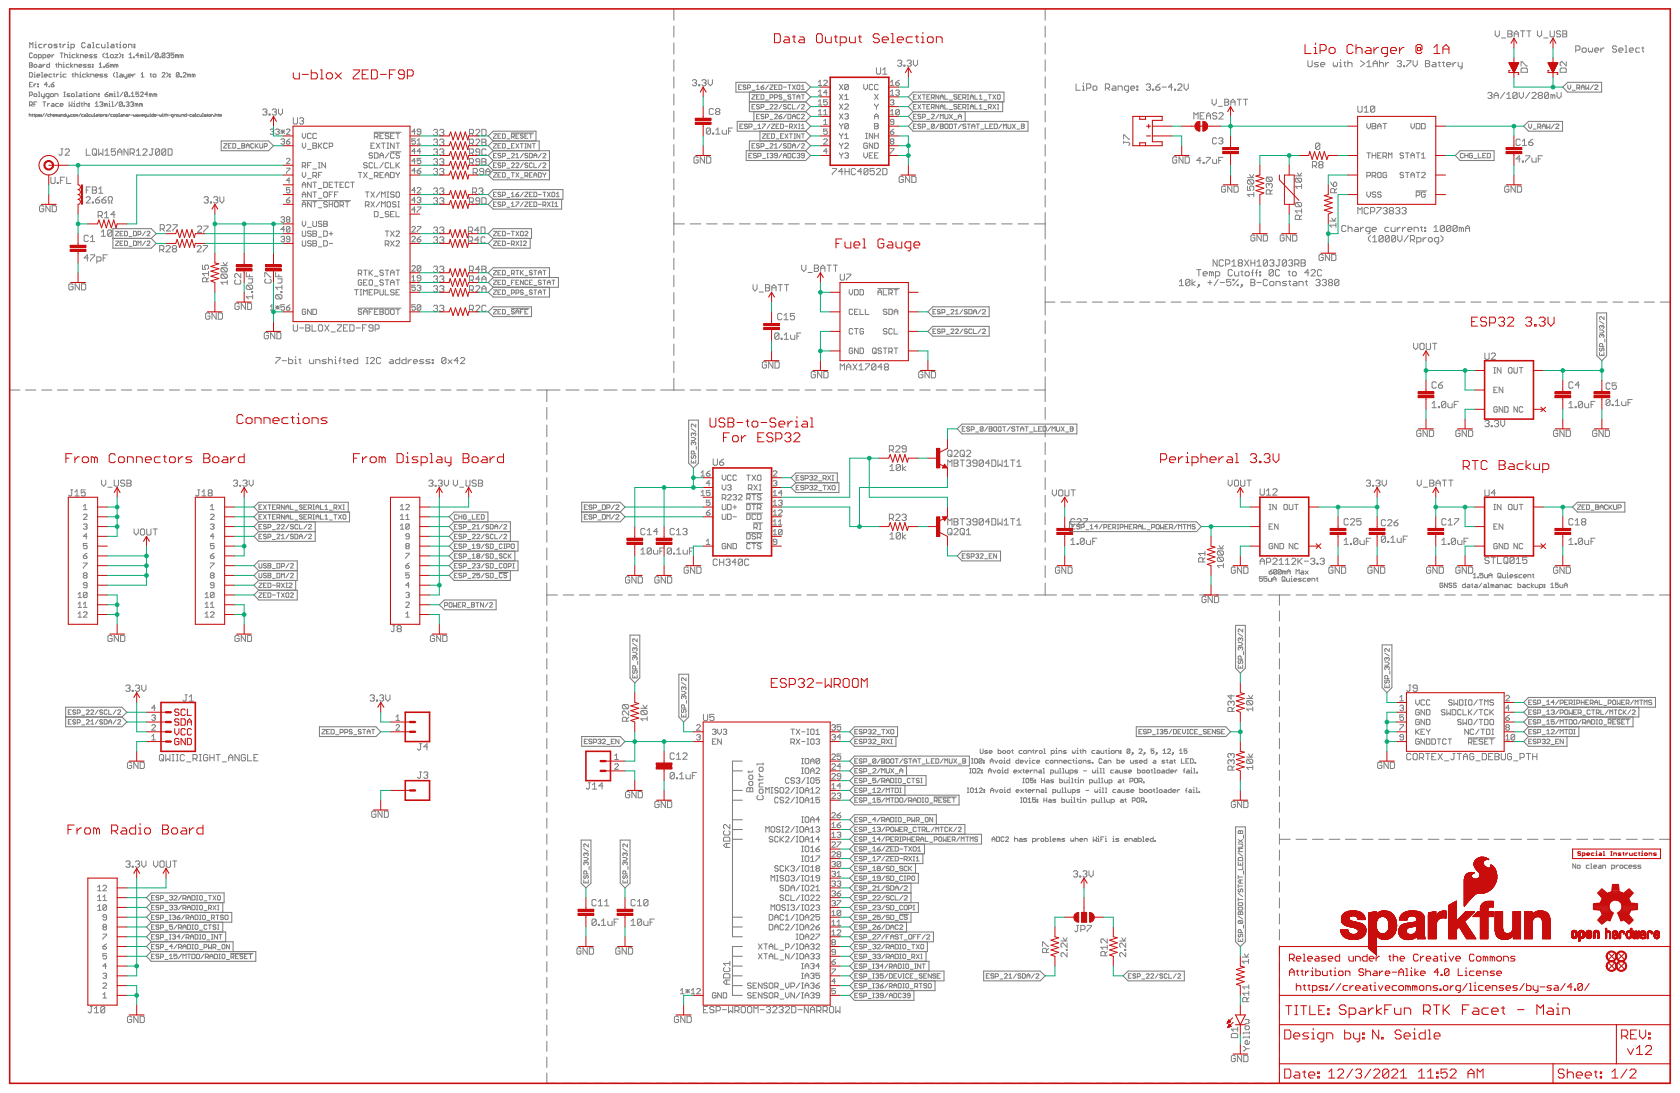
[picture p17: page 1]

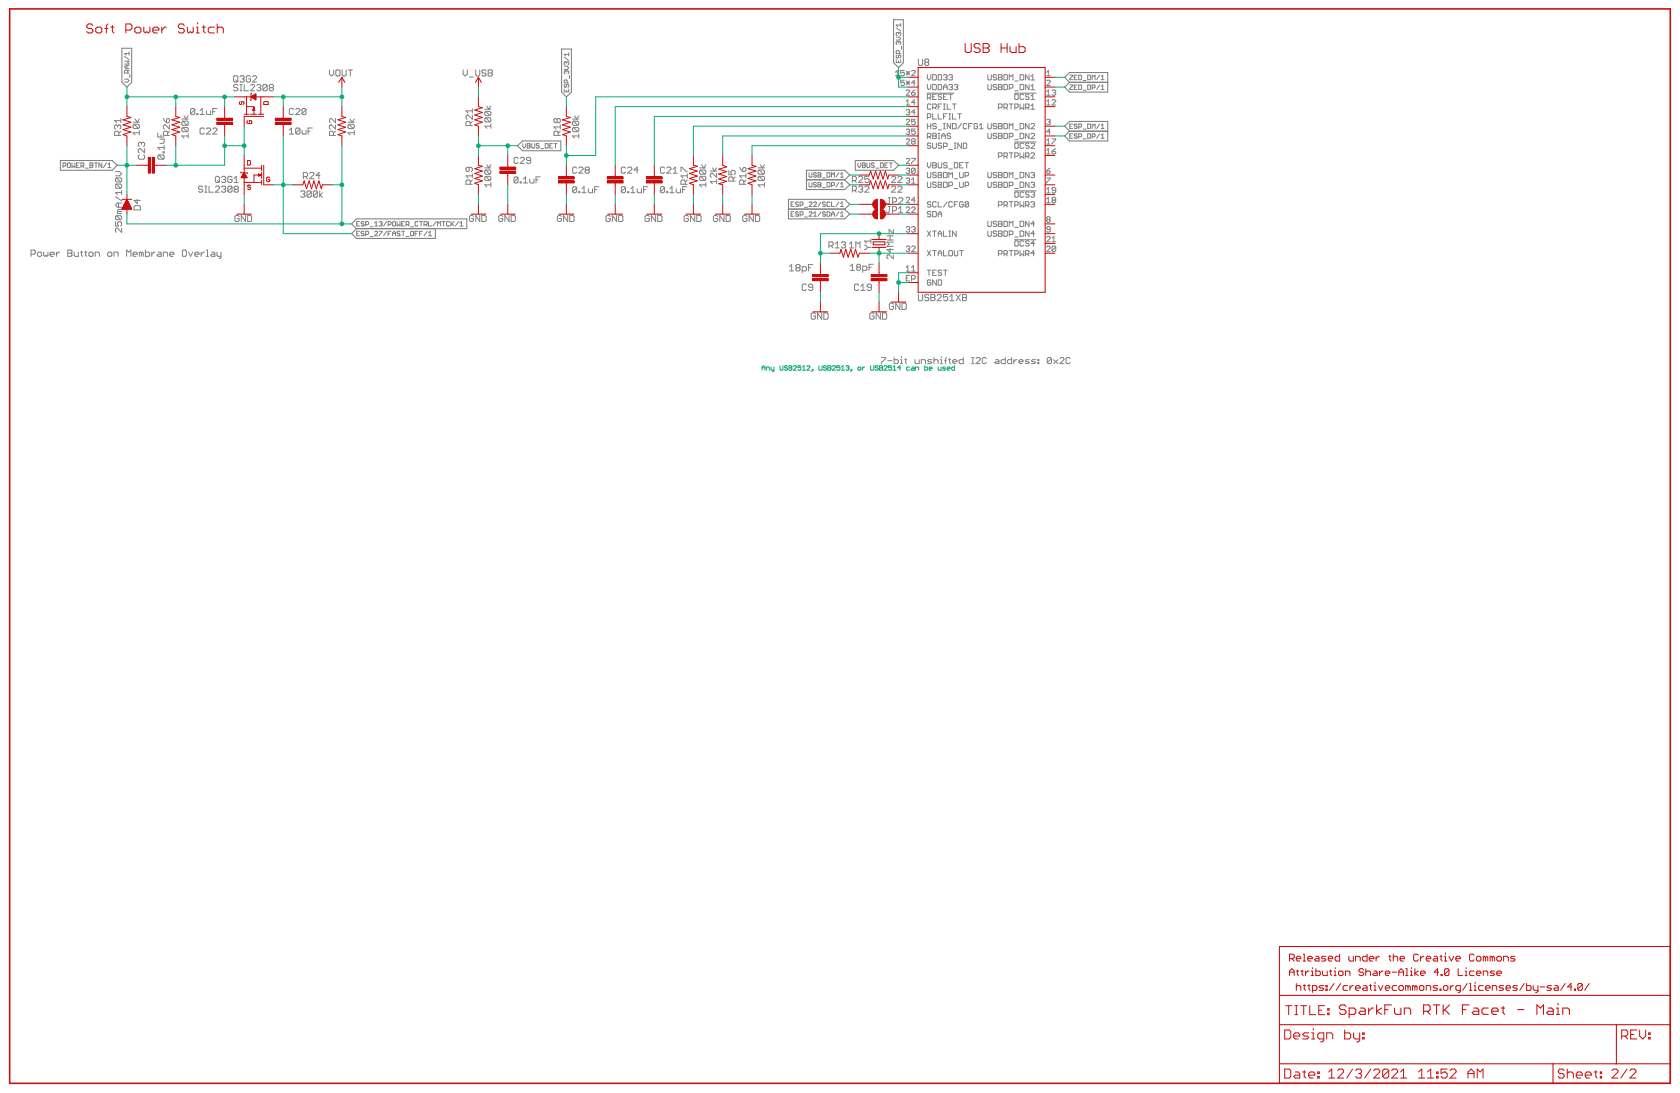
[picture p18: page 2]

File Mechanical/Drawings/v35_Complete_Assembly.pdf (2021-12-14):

Title; DWG No.; Rev.; Date of issue; Sheet

Dept. | Technical reference | Created by Nick Poole 1/11/2021 | Approved by

Document type | Document status

Title; DWG No.

FRONT PANEL DETAIL

Dept. | Technical reference | Created by Nick Poole 1/11/2021 | Approved by

Document type | Document status

Title; DWG No.

BOTTOM PANEL DETAIL

Dept. | Technical reference | Created by Nick Poole 1/11/2021 | Approved by

Document type | Document status

Title; DWG No.; INSIDE DETAIL

Dept. | Technical reference | Created by Nick Poole 1/11/2021 | Approved by

Document type | Document status

Title; DWG No.; LID DETAIL

Dept. | Technical reference | Created by Nick Poole 1/11/2021 | Approved by

Document type | Document status

Title; DWG No.

ASSEMBLY (NO SLEEVE)

Dept. | Technical reference | Created by Nick Poole 1/11/2021 | Approved by

Document type | Document status

Title; DWG No.

Dept. | Technical reference | Created by Nick Poole 1/11/2021 | Approved by

Document type | Document status

Title; DWG No.

Dept. | Technical reference | Created by Nick Poole 1/11/2021 | Approved by

Document type | Document status

Dept.; Technical reference; Created by; Approved by; Document type; Document status; Title; DWG No.; Nick Poole

Title; DWG No.

THREADED INSERT MOLDING DETAIL

Dept. | Technical reference | Created by Nick Poole 1/11/2021 | Approved by

Document type | Document status

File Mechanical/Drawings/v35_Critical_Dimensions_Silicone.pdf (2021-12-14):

Title; DWG No.; Rev.; Date of issue; Sheet; RTK Facet v35

RUBBER SLEEVE CRITICAL DIMENSIONS

Dept. | Technical reference | Created by Nick Poole 8/4/2021 | Approved by

Document type | Document status



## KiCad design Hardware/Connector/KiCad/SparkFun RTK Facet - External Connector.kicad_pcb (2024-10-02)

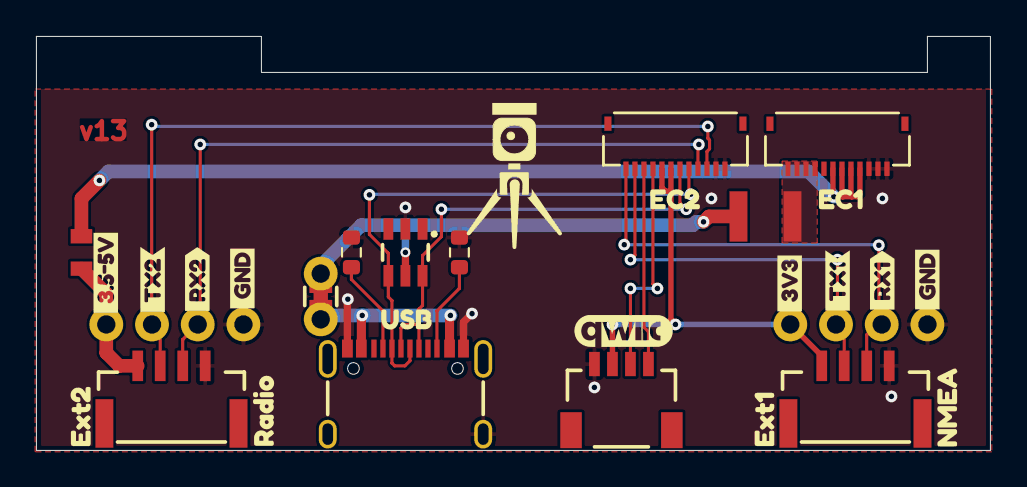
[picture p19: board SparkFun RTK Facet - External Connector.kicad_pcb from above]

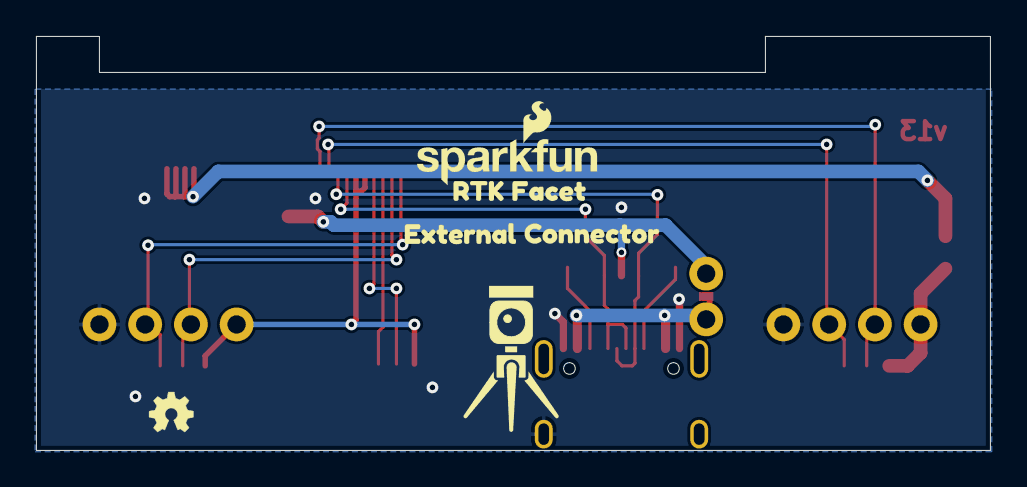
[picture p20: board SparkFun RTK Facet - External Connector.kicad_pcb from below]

Board: 4 copper layers, 53.0 x 23.0 mm, 37 parts (6 on the bottom side), 17 nets.

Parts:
D1: DT1042-04SO; SOT23-6
F1: 6V/0.5A/1A; 0805
F3: 6V/2.0A/4.0A; 1210
G3: OSHW_Logo; Creative_Commons_License
J1, J3: Conn_01x12_FPC_0.5mm; FPC_0.5mm-12
J2, J9: JST_Locking_4; JST_SMD_1.25mm-4_Locking
J4: Qwiic; JST_SMD_1.0mm-4_RA
J5: USB_C_Receptacle; USB-C_16
J11, J12: Conn_01x04; 1x04
JP0: Measure; Jumper_2_PTH_SMD_Combo-NC
LOGO1: OSHW-LOGOMINI; OSHW_Logo_2.5mm
LOGO2: SFE_LOGO_NAME_FLAME.1_INCH; SparkFun_Logo_10mm
R16, R17: 5.1k; R_0603_1608Metric
Ref**: Val**; SparkFun_RTK_20mm
Ref**#2: Val**; SparkFun_RTK_20mm
kibuzzard-66F4BFD6: G***; kibuzzard-66F4BFD6
kibuzzard-66F4BFE6: G***; kibuzzard-66F4BFE6
kibuzzard-66F4BFEC: G***; kibuzzard-66F4BFEC
kibuzzard-66F4C0A3: G***; kibuzzard-66F4C0A3
kibuzzard-66F4C0CF: G***; kibuzzard-66F4C0CF
kibuzzard-66F4C0D4: G***; kibuzzard-66F4C0D4
kibuzzard-66F4C0DF: G***; kibuzzard-66F4C0DF
kibuzzard-66F4C0F8: G***; kibuzzard-66F4C0F8
kibuzzard-66F4C0FC: G***; kibuzzard-66F4C0FC
kibuzzard-66F4C1AD: G***; kibuzzard-66F4C1AD
kibuzzard-66F4C03C, kibuzzard-66F4C03C#2: G***; kibuzzard-66F4C03C
kibuzzard-66F4C09A: G***; kibuzzard-66F4C09A
kibuzzard-66F4C18F: G***; kibuzzard-66F4C18F
kibuzzard-66F4C088: G***; kibuzzard-66F4C088
kibuzzard-66F4C143: G***; kibuzzard-66F4C143
kibuzzard-66F4C147: G***; kibuzzard-66F4C147
kibuzzard-66F4C199: G***; kibuzzard-66F4C199

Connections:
3.3V: J2.1, J3.7, J3.8, J4.2, J12.4
ESP_21/SDA: J3.9, J4.3
ESP_22/SCL: J3.10, J4.4
EXTERNAL_SERIAL1_RXI: J2.3, J3.12, J12.2
EXTERNAL_SERIAL1_TXO: J2.2, J3.11, J12.3
GND: D1.2 (GND), J1.1, J1.2, J1.3, J2.4, J3.1, J3.2, J4.1, J5.GND, J5.S (SHIELD), J9.4, J11.1, J12.1, R16.2, R17.2
unnamed: D1.5 (VCC), F3.2, JP0.2 (B)
unnamed: J5.A5 (CC1), R17.1
unnamed: J5.B5 (CC2), R16.1
unnamed: F1.2, J9.1, J11.4
unnamed: J5.VBUS, JP0.1 (A)
USB_DM: D1.4 (I/O3), J3.5, J5.A7 (D-), J5.B7 (D-)
USB_DP: D1.6 (I/O4), J3.6, J5.A6 (D+), J5.B6 (D+)
V_BATT: F1.1, J1.4, J1.5, J1.6, J1.7
V_USB: F3.1, J1.9, J1.10, J1.11, J1.12
ZED-RXI2: J3.4, J9.3, J11.2
ZED-TXO2: J3.3, J9.2, J11.3

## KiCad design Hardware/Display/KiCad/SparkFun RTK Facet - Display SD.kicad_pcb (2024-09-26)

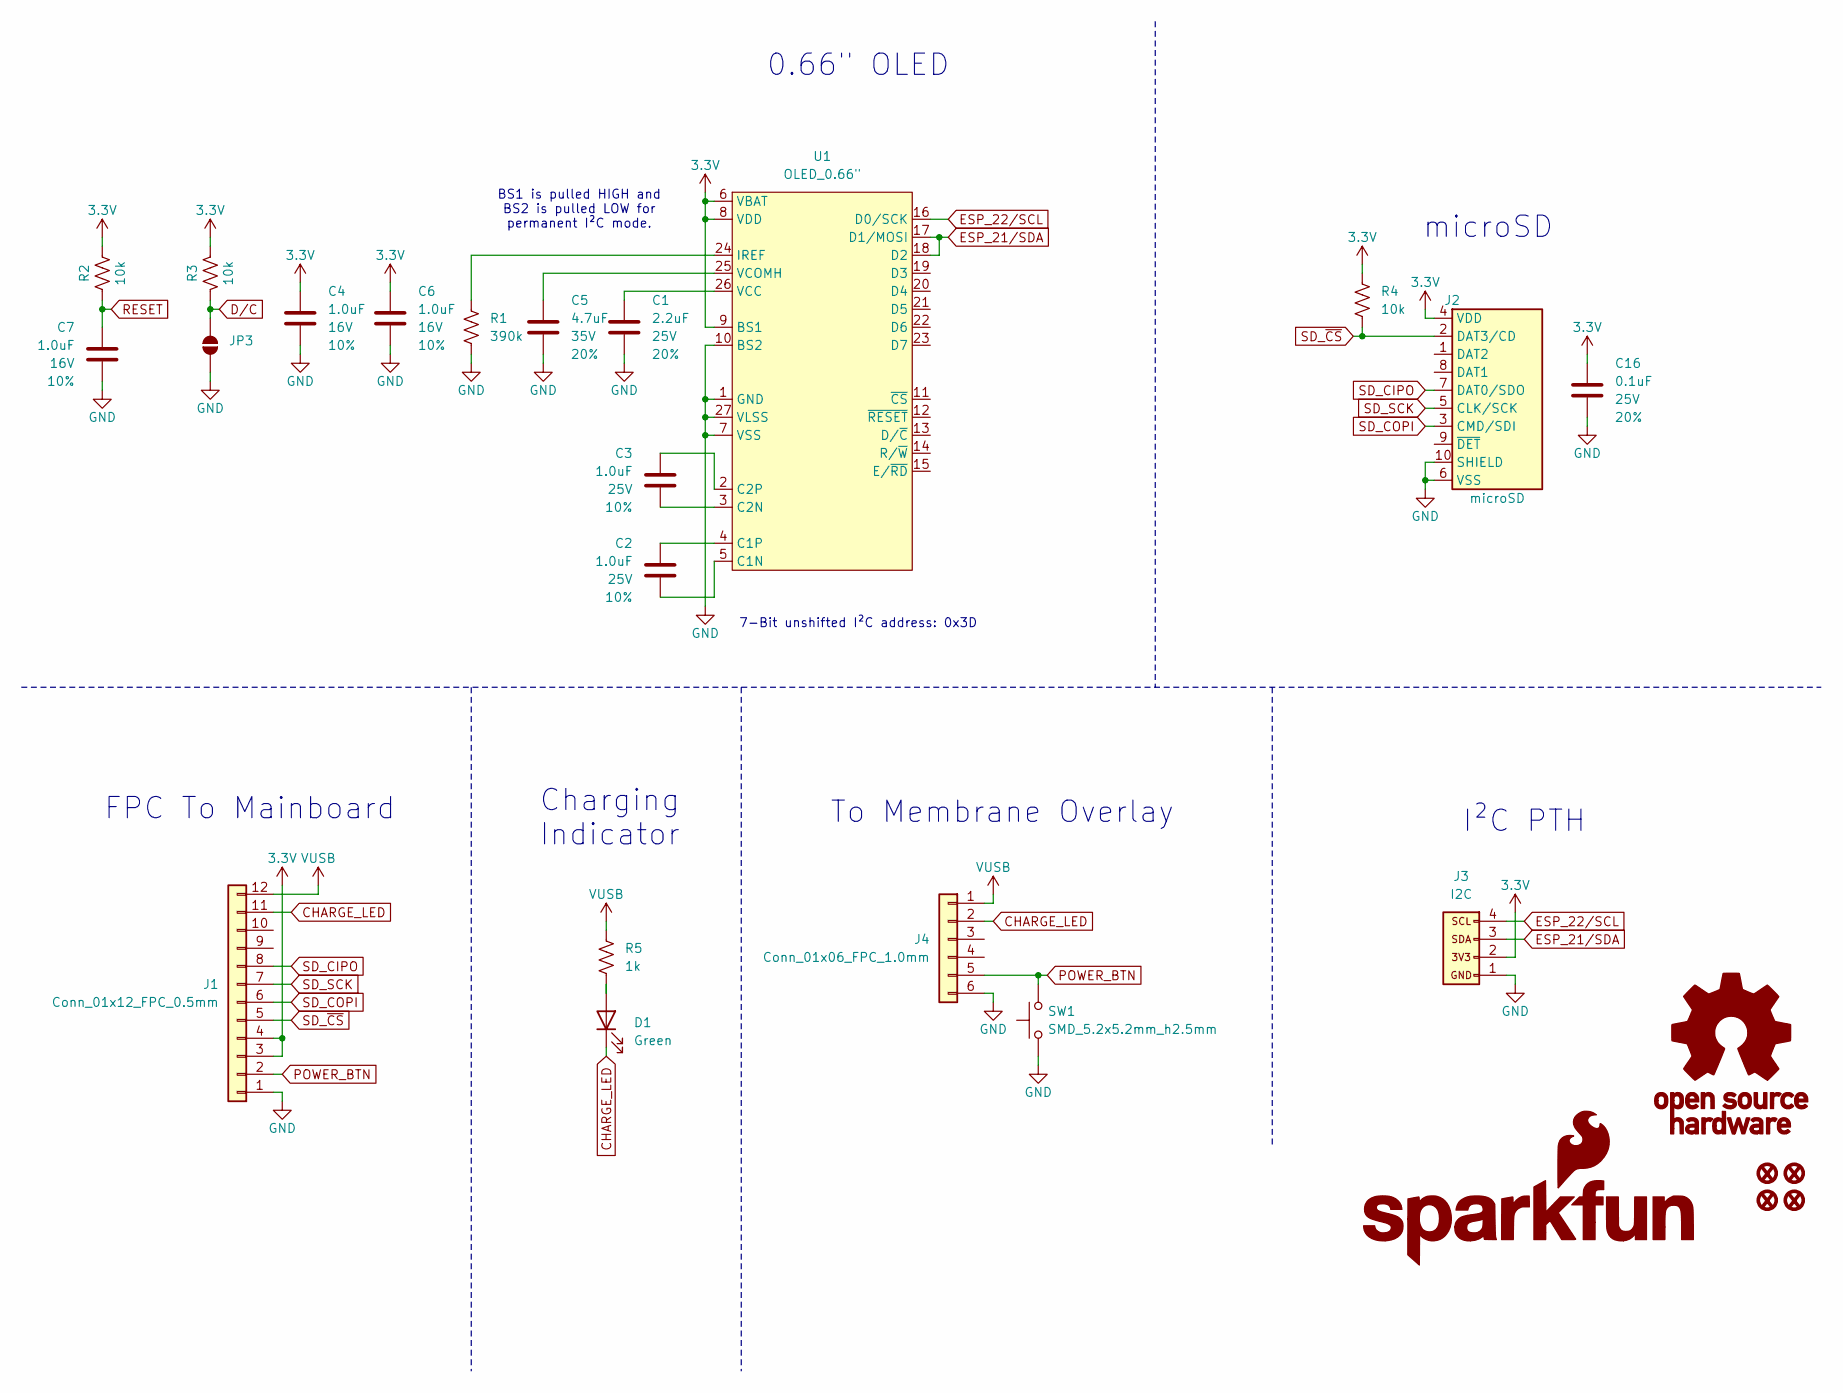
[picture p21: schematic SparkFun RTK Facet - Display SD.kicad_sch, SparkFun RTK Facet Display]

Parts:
C1: 2.2uF; C_0805_2012Metric; Voltage 25V; Tolerance 20%
C2, C3: 1.0uF; C_0805_2012Metric; Voltage 25V; Tolerance 10%
C4, C6, C7: 1.0uF; C_0603_1608Metric; Voltage 16V; Tolerance 10%
C5: 4.7uF; C_0603_1608Metric; Voltage 35V; Tolerance 20%
C16: 0.1uF; C_0603_1608Metric; Voltage 25V; Tolerance 20%
D1: Green; LED_1206_Bottom_Green
FID1, FID2, FID3, FID4: Fiducial_0.5mm; Fiducial_0.5mm_Mask1mm
G1: SparkFun_Logo
G2: OSHW_Logo; Creative_Commons_License
J1: Conn_01x12_FPC_0.5mm; FPC_0.5mm-12
J2: microSD; microSD_External_Pin
J3: I2C; 1x04
J4: Conn_01x06_FPC_1.0mm; FPC_1.0mm-6_LIF
JP3: Jumper_2_NO
R1: 390k; R_0603_1608Metric
R2, R3, R4: 10k; R_0603_1608Metric
R5: 1k; R_0402_1005Metric
SW1: SMD_5.2x5.2mm_h2.5mm; Push_SMD_5.2x5.2mm_h2.5mm
U1: OLED_0.66"; OLED_0.66-SMD

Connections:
3.3V: C4.1, C6.1, C16.1, J1.3, J1.4, J2.4 (VDD), J3.2, R2.2, R3.1, R4.1, U1.6 (VBAT), U1.8 (VDD), U1.9 (BS1)
CHARGE_LED: D1.1 (K), J1.11, J4.2
D/C: JP3.2 (B), R3.2
ESP_21/SDA: J3.3, U1.17 (D1/MOSI), U1.18 (D2)
ESP_22/SCL: J3.4, U1.16 (D0/SCK)
GND: C1.2, C4.2, C5.2, C6.2, C7.2, C16.2, J1.1, J2.6 (VSS), J2.10 (SHIELD), J3.1, J4.6, JP3.1 (A), R1.2, SW1.1, U1.1 (GND), U1.7 (VSS), U1.10 (BS2), U1.27 (VLSS), U1.28 (GND)
unnamed: D1.2 (A), R5.2
unnamed: C2.2, U1.5 (C1N)
unnamed: C2.1, U1.4 (C1P)
unnamed: C3.2, U1.3 (C2N)
unnamed: C3.1, U1.2 (C2P)
unnamed: R1.1, U1.24 (IREF)
unnamed: C1.1, U1.26 (VCC)
unnamed: C5.1, U1.25 (VCOMH)
POWER_BTN: J1.2, J4.5, SW1.2
RESET: C7.1, R2.1
SD_CIPO: J1.8, J2.7 (DAT0/SDO)
SD_COPI: J1.6, J2.3 (CMD/SDI)
SD_SCK: J1.7, J2.5 (CLK/SCK)
SD_~CS: J1.5, J2.2 (DAT3/CD), R4.2
VUSB: J1.12, J4.1, R5.1

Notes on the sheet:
7-Bit unshifted I²C address: 0x3D
BS1 is pulled HIGH and BS2 is pulled LOW for permanent I²C mode.
0.66" OLED
To Membrane Overlay
I²C PTH
FPC To Mainboard
Charging Indicator
microSD

Board: 2 copper layers, 38 parts (27 on the bottom side), 21 nets, no tracks yet.

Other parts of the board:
Ref**: Val**; SparkFun_RTK_20mm
Ref**#2: Val**; OSHW_Logo_5mm
kibuzzard-66E8FA3C: G***; kibuzzard-66E8FA3C
kibuzzard-66E8FA6A: G***; kibuzzard-66E8FA6A
kibuzzard-66E8FA6F: G***; kibuzzard-66E8FA6F
kibuzzard-66E8FA7A: G***; kibuzzard-66E8FA7A
kibuzzard-66E8FA21: G***; kibuzzard-66E8FA21
kibuzzard-66E8FA52: G***; kibuzzard-66E8FA52
kibuzzard-66E8FA75: G***; kibuzzard-66E8FA75
kibuzzard-66E8FB1B: G***; kibuzzard-66E8FB1B
kibuzzard-66E8FB47: G***; kibuzzard-66E8FB47
kibuzzard-66E8FBC7: G***; kibuzzard-66E8FBC7

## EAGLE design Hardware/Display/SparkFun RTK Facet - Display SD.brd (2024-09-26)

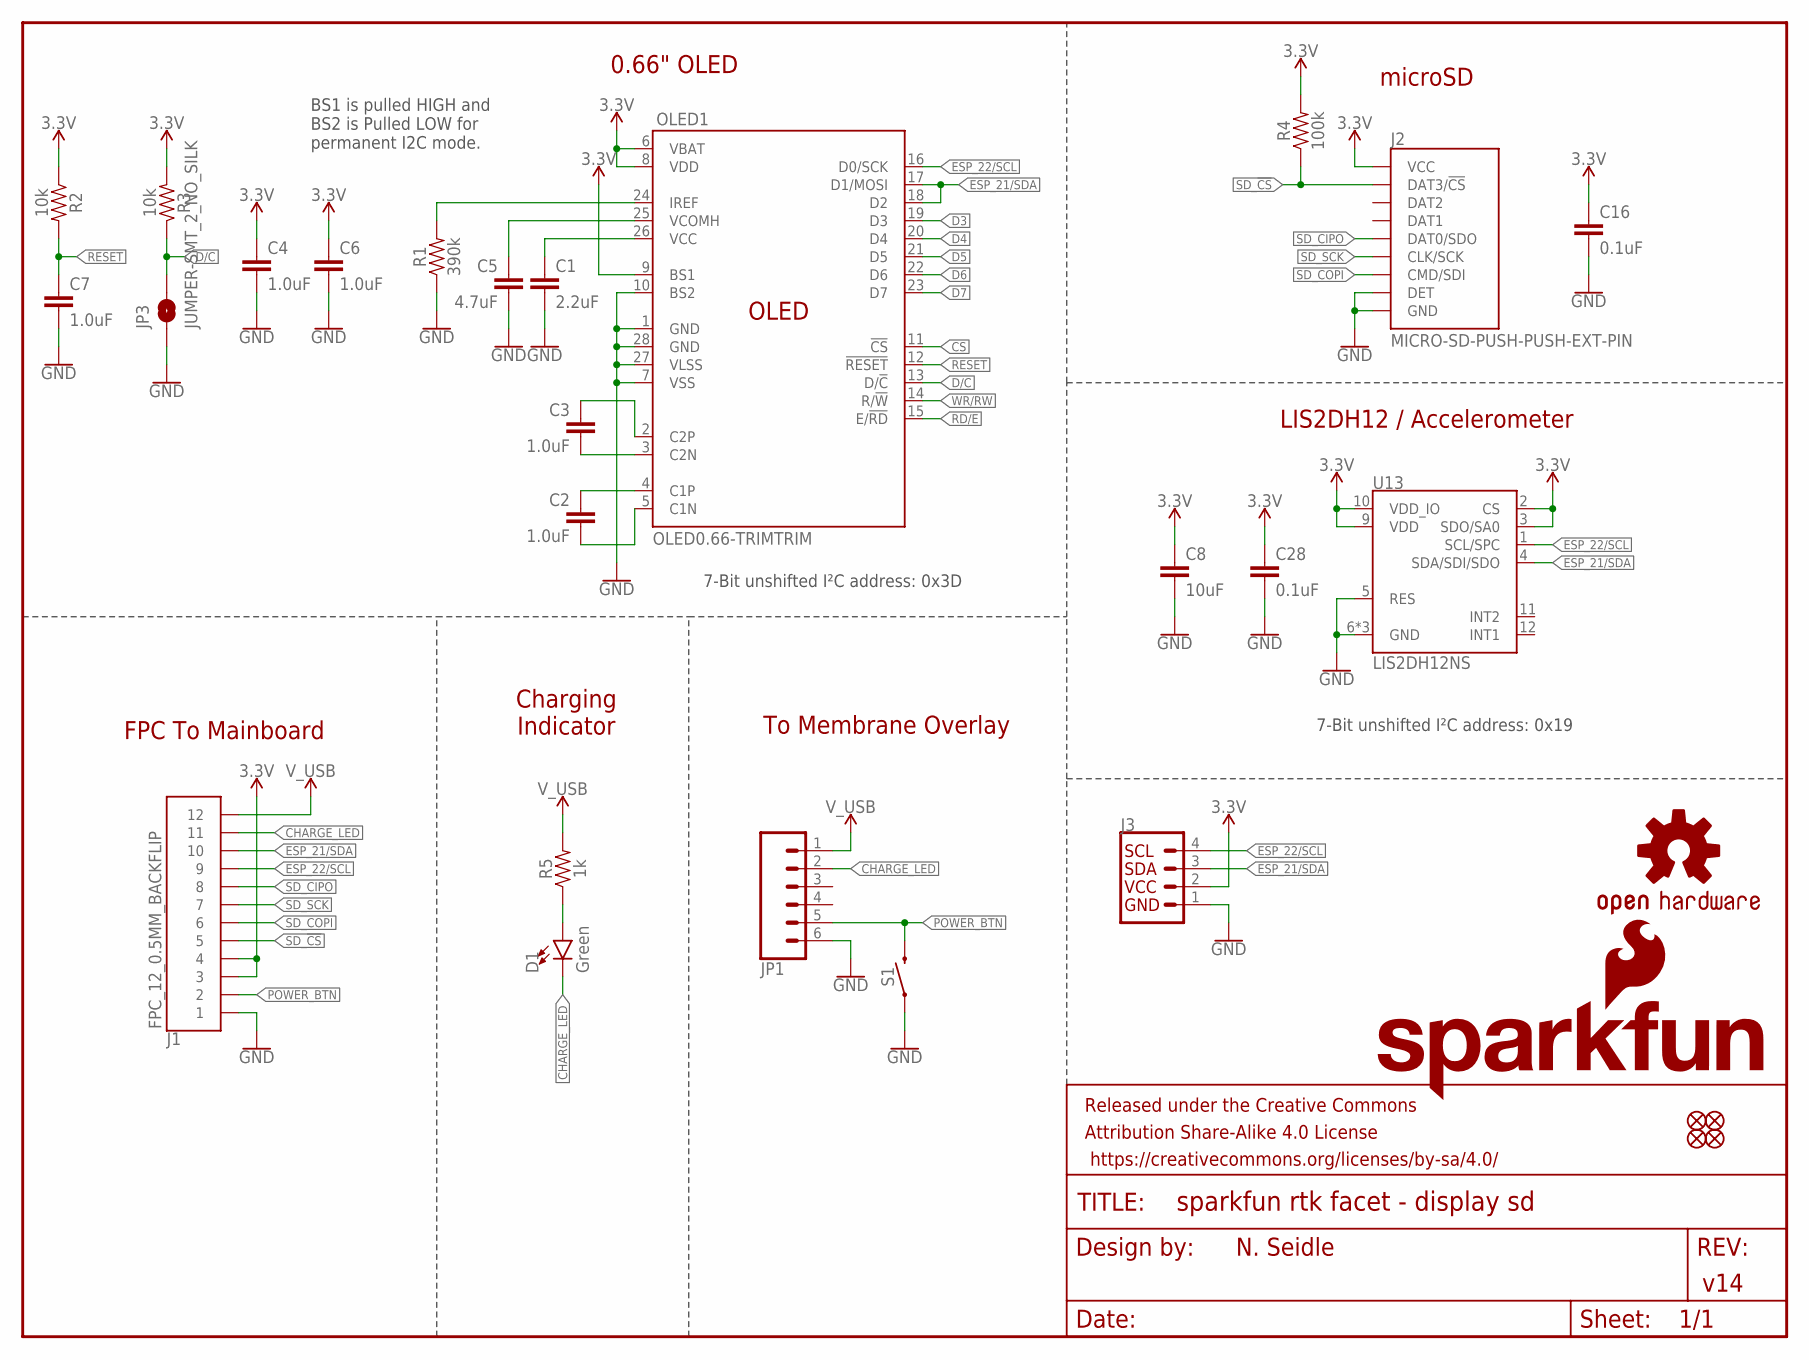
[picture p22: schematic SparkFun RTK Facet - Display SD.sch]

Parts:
C1: 2.2uF; 0805
C2, C3: 1.0uF; 0805
C4, C6, C7: 1.0uF; 0603
C5: 4.7uF; 1206
C8: 10uF; 0603
C16, C28: 0.1uF; 0603
D1: Green; LED-1206-BOTTOM
FID1, FID2, FID3, FID4: FIDUCIAL1X2; FIDUCIAL-1X2
FRAME1: FRAME-LETTER; CREATIVE_COMMONS
J1: FPC_12_0.5MM_BACKFLIP; FPC_12_DOUBLESIDED_BACKFLIP
J2: MICRO-SD-PUSH-PUSH-EXT-PIN; MICROSD-EXTERNALPIN
J3: I2C_STANDARD_NO_SILK; 1X04_NO_SILK
JP1: CONN_061MM-LIF; FPC_6_1MM-LIF
JP3: JUMPER-SMT_2_NO_SILK; SMT-JUMPER_2_NO_SILK
LOGO3: OSHW-LOGOMINI; OSHW-LOGO-MINI
LOGO5: SFE_LOGO_NAME_FLAME8_MM; SFE_LOGO_NAME_FLAME_8MM
OLED1: OLED0.66-TRIMTRIM; OLED-0.66-64X48-TRIM
R1: 390k; 0603
R2, R3: 10k; 0603
R4: 100k; 0603
R5: 1k; 0603
S1: MOMENTARY-SWITCH-SPST-SMD-5.2MM-TALL; TACTILE_SWITCH_SMD_5.2MM
U13: LIS2DH12NS; LGA-12-LISDH12-NOSILK

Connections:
3.3V: C4.1, C6.1, C8.1, C16.1, C28.1, J1.3, J1.4, J2.4 (VCC), J3.2, OLED1.6 (VBAT), OLED1.8 (VDD), OLED1.9 (BS1), R2.1, R3.2, R4.2, U13.2 (CS), U13.3 (SDO/SA0), U13.9 (VDD), U13.10 (VDD_IO)
C1P: C2.1, OLED1.4 (C1P)
C2N: C3.2, OLED1.3 (C2N)
CHARGE_LED: D1.C, J1.11, JP1.2
CS: OLED1.11 (!CS!)
D3: OLED1.19 (D3)
D4: OLED1.20 (D4)
D5: OLED1.21 (D5)
D6: OLED1.22 (D6)
D7: OLED1.23 (D7)
D/C: JP3.2, OLED1.13 (D/!C!), R3.1
ESP_21/SDA: J1.10, J3.3, OLED1.17 (D1/MOSI), OLED1.18 (D2), U13.4 (SDA/SDI/SDO)
ESP_22/SCL: J1.9, J3.4, OLED1.16 (D0/SCK), U13.1 (SCL/SPC)
GND: C1.2, C4.2, C5.2, C6.2, C7.2, C8.2, C16.2, C28.2, J1.1, J2.6 (GND), J2.9 (DET), J2.10 (GND), J2.11 (GND), J2.12 (GND), J2.13 (GND), J3.1, JP1.6, JP3.1, OLED1.1 (GND), OLED1.7 (VSS), OLED1.10 (BS2), OLED1.27 (VLSS), OLED1.28 (GND), R1.1, S1.1, U13.5 (RES), U13.6 (GND), U13.7 (GND), U13.8 (GND)
IREF: OLED1.24 (IREF), R1.2
unnamed: C3.1, OLED1.2 (C2P)
unnamed: C2.2, OLED1.5 (C1N)
unnamed: D1.A, R5.1
POWER_BTN: J1.2, JP1.5, S1.3 (2)
RD/E: OLED1.15 (E/!RD!)
RESET: C7.1, OLED1.12 (!RESET!), R2.2
SD_!CS!: J1.5, J2.2 (DAT3/!CS!), R4.1
SD_CIPO: J1.8, J2.7 (DAT0/SDO)
SD_COPI: J1.6, J2.3 (CMD/SDI)
SD_SCK: J1.7, J2.5 (CLK/SCK)
VCC: C1.1, OLED1.26 (VCC)
VCOMH: C5.1, OLED1.25 (VCOMH)
V_USB: J1.12, JP1.1, R5.2
WR/RW: OLED1.14 (R/!W!)

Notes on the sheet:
v14
FPC To Mainboard
BS1 is pulled HIGH and BS2 is Pulled LOW for permanent I2C mode.
microSD
7-Bit unshifted I²C address: 0x19
LIS2DH12 / Accelerometer
To Membrane Overlay
0.66" OLED
Charging Indicator
N. Seidle
7-Bit unshifted I²C address: 0x3D

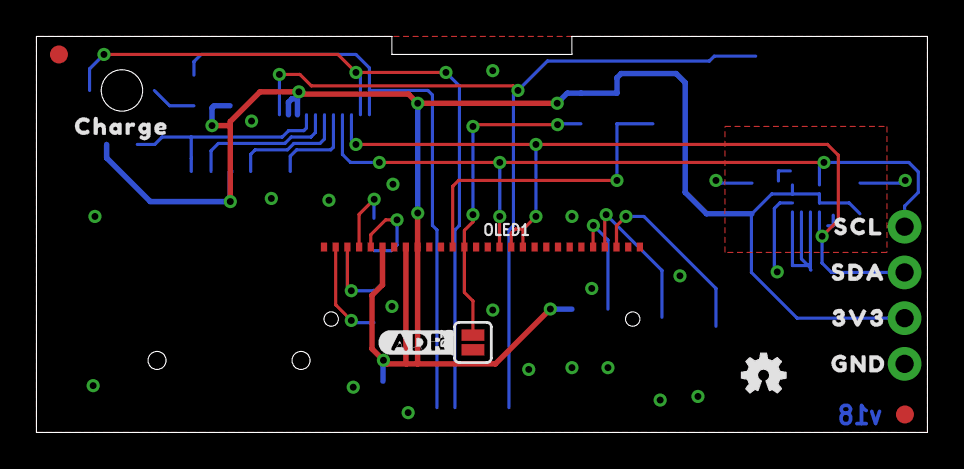
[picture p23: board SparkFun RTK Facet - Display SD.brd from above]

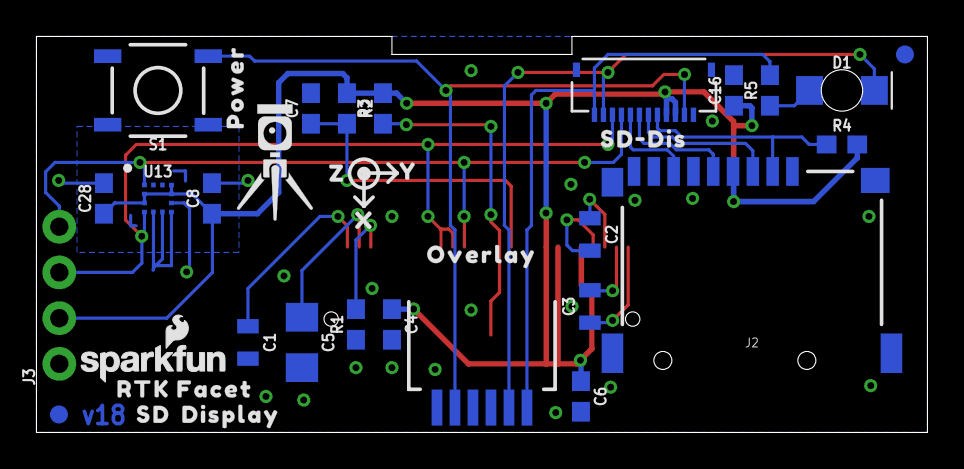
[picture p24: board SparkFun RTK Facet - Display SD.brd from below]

Board: 2 copper layers, 49.5 x 22.0 mm, 48 parts (37 on the bottom side), 21 nets.

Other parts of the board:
U$1: SD#DIS0
U$2: OVERLAY0
U$3: DISPLAY0
U$4: SD1
U$5: RTK5#SVG0
U$6: SPECIAL_INSTRUCTIONS-ORDERING; ORDERING_INSTRUCTIONS
U$7: #ADR#0
U$8: CHARGE0
U$9: POWER0
U$10: X0
U$11: Y1
U$12: Z2
U$13: RTK_FACET0
U$14: 3V33
U$15: GND2
U$16: SCL0
U$17: SDA1

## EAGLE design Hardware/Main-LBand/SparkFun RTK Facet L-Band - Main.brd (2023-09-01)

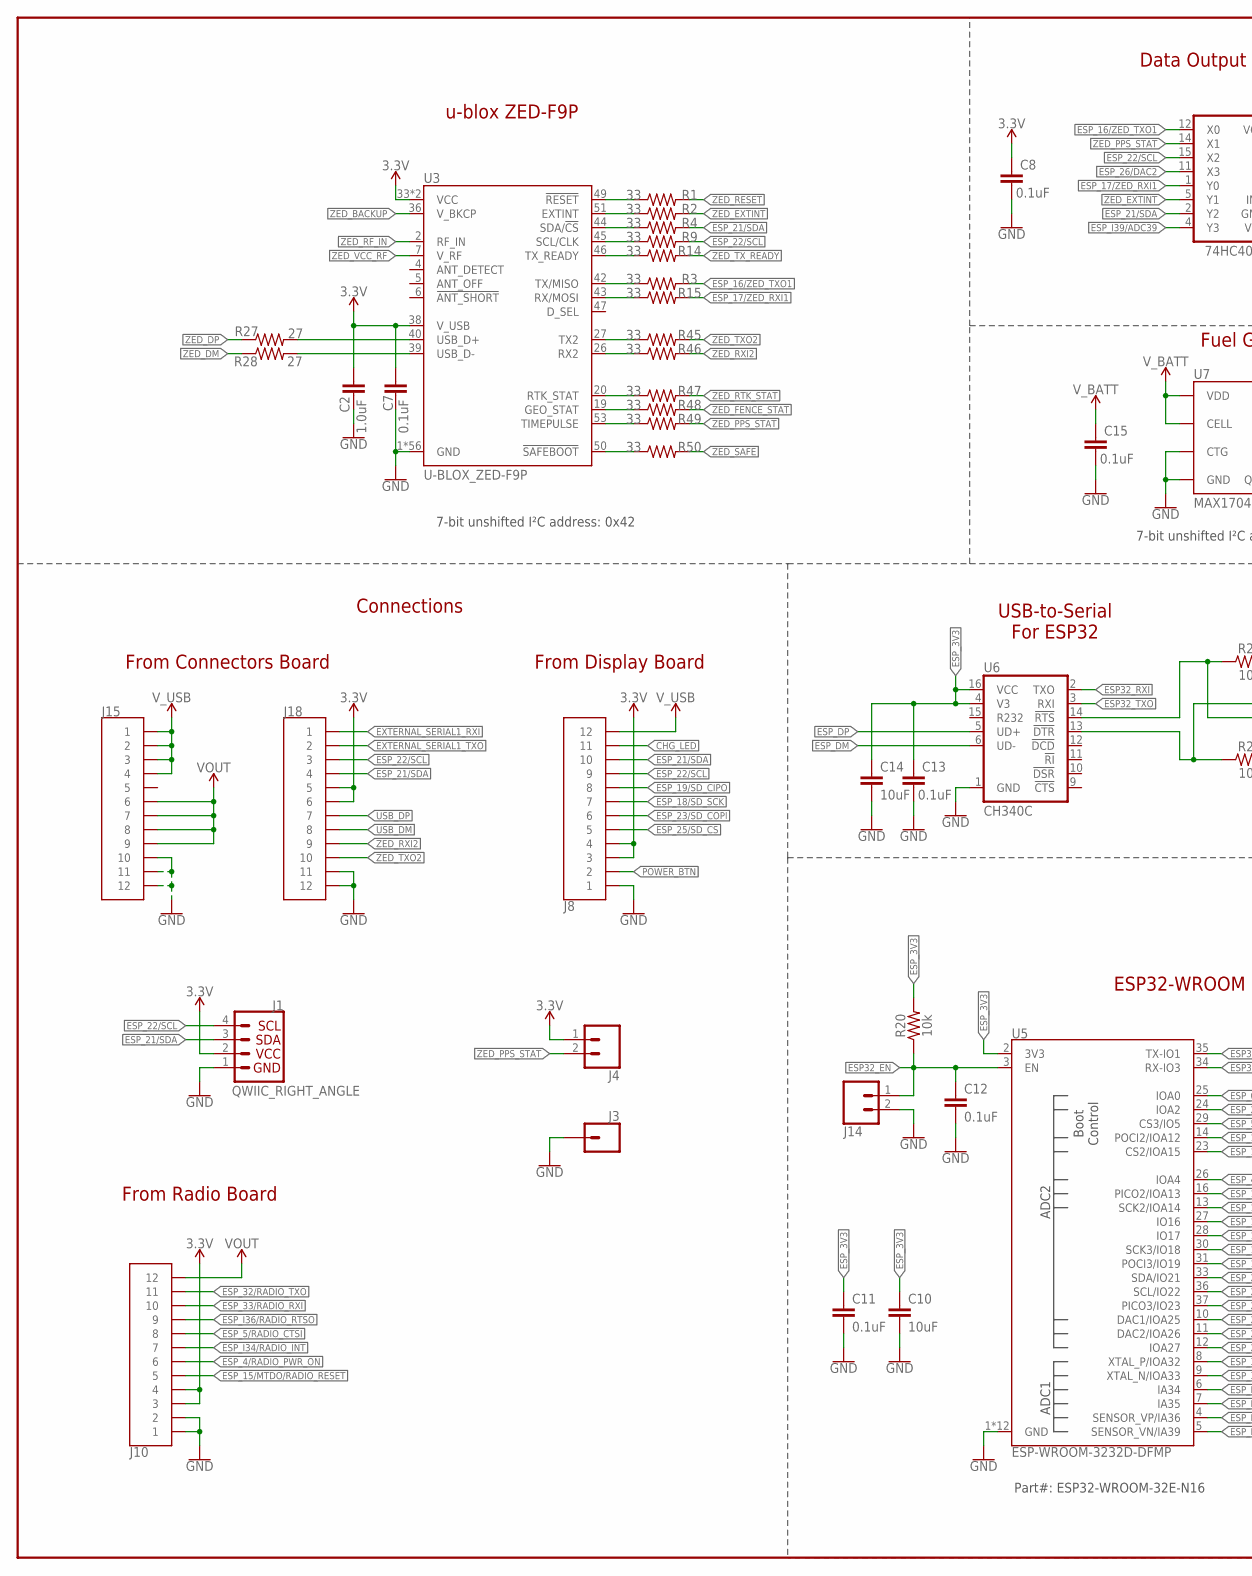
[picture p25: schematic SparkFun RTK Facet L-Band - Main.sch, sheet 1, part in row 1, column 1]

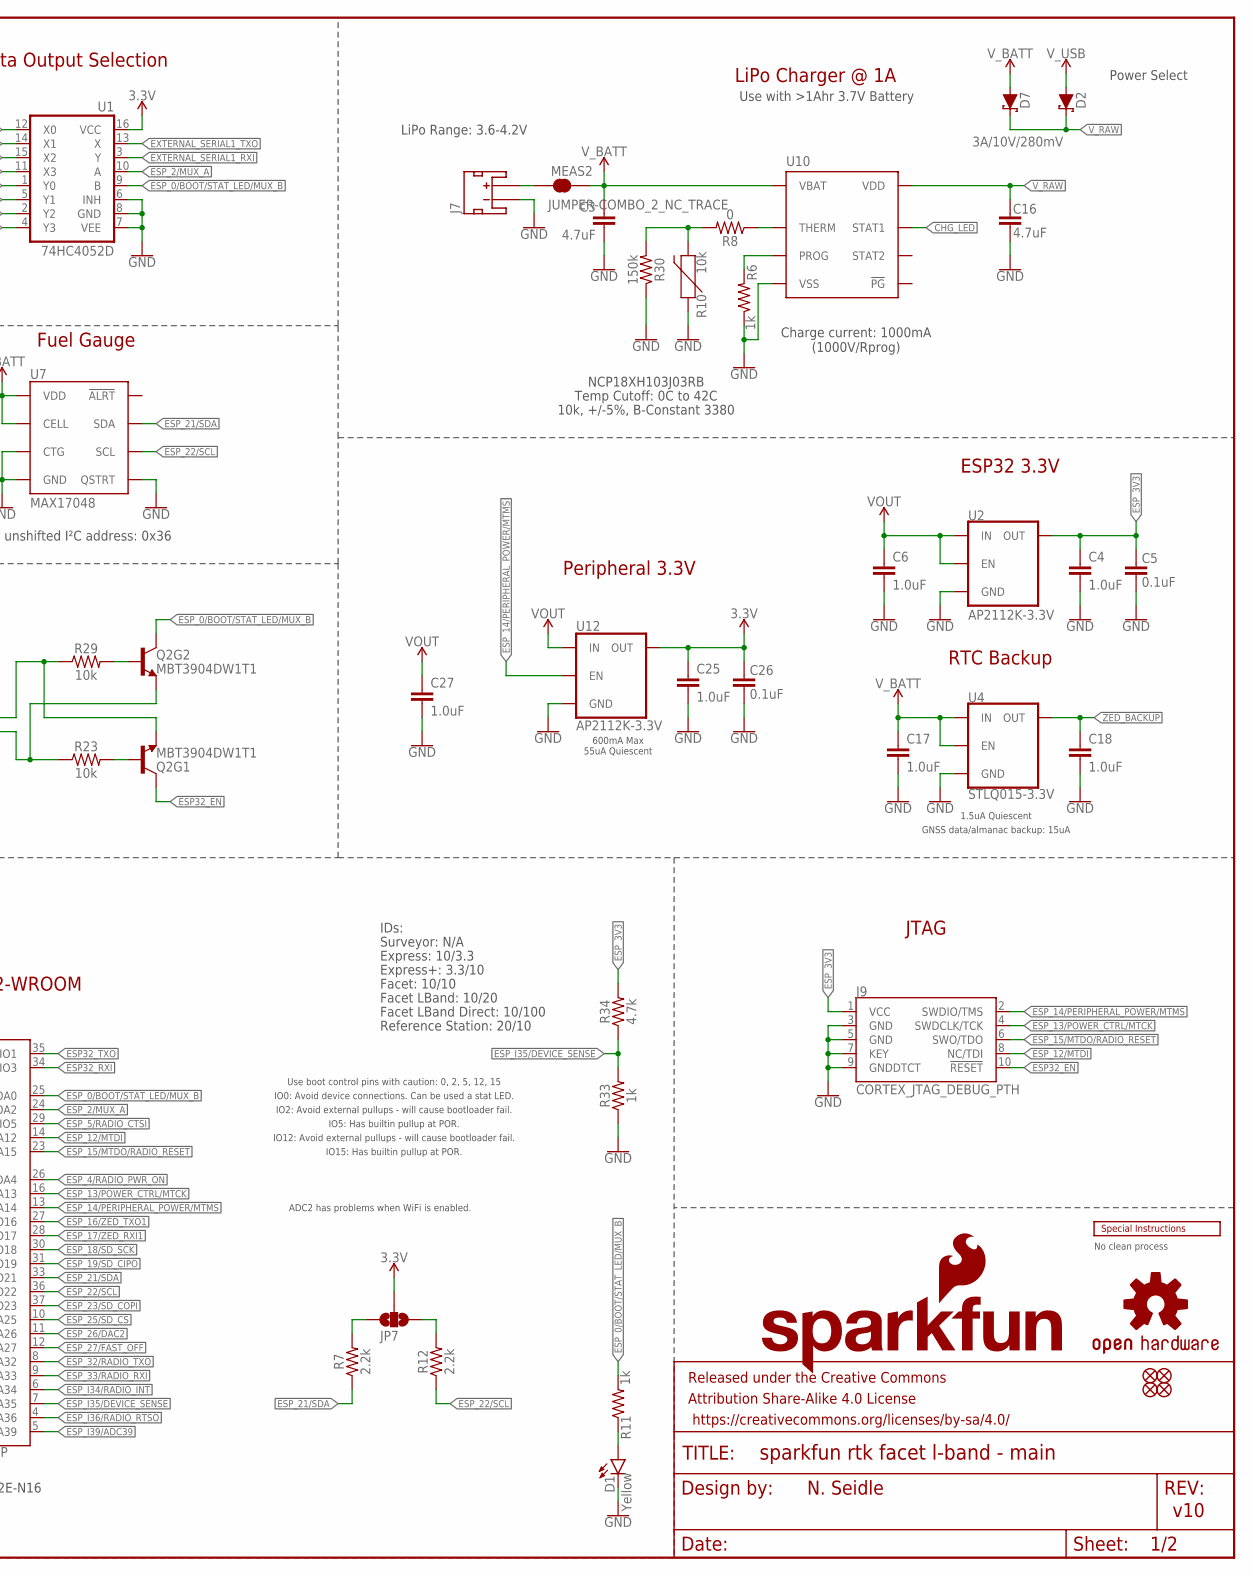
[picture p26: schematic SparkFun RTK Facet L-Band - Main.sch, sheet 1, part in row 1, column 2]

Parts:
C2, C4, C6, C17, C18, C25, C27: 1.0uF; 0603
C3, C16: 4.7uF; 0603
C5, C7, C8, C11, C12, C13, C15, C26: 0.1uF; 0603
C10, C14: 10uF; 0603
D1: Yellow; LED-0603
D2, D7: 3A/10V/280mV; SOD-323
FRAME2: FRAME-LEDGER; CREATIVE_COMMONS
J1: QWIIC_RIGHT_ANGLE; JST04_1MM_RA
J3: CONN_01PTH_NO_SILK_YES_STOP; 1X01_NO_SILK
J4, J14: CONN_021X02_NO_SILK; 1X02_NO_SILK
J7: JST_2MM_MALE; JST-2-SMD
J8, J10, J15, J18: FPC_12_0.5MM_BACKFLIP; FPC_12_DOUBLESIDED_BACKFLIP
J9: CORTEX_JTAG_DEBUG_PTH; 2X5-PTH-1.27MM
JP7: JUMPER-SMT_3_NO_SILK; SMT-JUMPER_3_NO_SILK
JP21, JP61, JP71, JP81: FIDUCIALUFIDUCIAL; FIDUCIAL-MICRO
LOGO1: OSHW-LOGOMINI; OSHW-LOGO-MINI
LOGO2: SFE_LOGO_NAME_FLAME.1_INCH; SFE_LOGO_NAME_FLAME_.1
MEAS2: JUMPER-COMBO_2_NC_TRACE; COMBO-JUMPER_2_NC_TRACE
Q2: MBT3904DW1T1; SC70-6
R1, R2, R3, R4, R9, R14, R15, R45, R46, R47, R48, R49, R50: 33; 0603
R6, R11, R33: 1k; 0603
R7, R12: 2.2k; 0603
R8: 0; 0603
R10, R20, R23, R29: 10k; 0603
R27, R28: 27; 0603
R30: 150k; 0603
R34: 4.7k; 0603
U1: 74HC4052D; SO16
U2, U12: AP2112K-3.3V; SOT23-5
U3: U-BLOX_ZED-F9P; ZED-F9P
U4: STLQ015-3.3V; SOT23-5
U5: ESP-WROOM-3232D-DFMP; ESP-WROOM-32D-DFM_PASTE
U6: CH340C; SO016
U7: MAX17048; DFN-8
U10: MCP73833MSOP; MSOP10
U$2: SPECIAL_INSTRUCTIONS-ORDERING; ORDERING_INSTRUCTIONS

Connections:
3.3V: C2.1, C7.2, C8.1, C25.1, C26.2, J1.2, J4.1, J8.3, J8.4, J10.3, J10.4, J18.5, J18.6, JP7.2, U1.16 (VCC), U3.33 (VCC), U3.34 (VCC), U3.38 (V_USB), U12.5 (OUT); also elsewhere on the board
CHG_LED: J8.11, U10.3 (STAT1)
CHG_THERM1: R8.2, R10.2, R30.2
ESP32_!DTR: Q2.1 (E), R23.1, U6.13 (!DTR)
ESP32_!RTS: Q2.4 (E), R29.1, U6.14 (!RTS)
ESP32_EN: C12.1, J9.10 (!RESET), J14.1, Q2.3 (C), R20.1, U5.3 (EN)
ESP32_RXI: U5.34 (RX-IO3), U6.2 (TXO)
ESP32_TXO: U5.35 (TX-IO1), U6.3 (RXI)
ESP_0/BOOT/STAT_LED/MUX_B: Q2.6 (C), R11.2, U1.9 (B), U5.25 (IOA0)
ESP_2/MUX_A: U1.10 (A), U5.24 (IOA2)
ESP_3V3: C4.1, C5.2, C10.1, C11.1, C13.1, C14.1, J9.1 (VCC), R20.2, R34.2, U2.5 (OUT), U5.2 (3V3), U6.4 (V3), U6.16 (VCC); also elsewhere on the board
ESP_4/RADIO_PWR_ON: J10.6, U5.26 (IOA4)
ESP_5/RADIO_CTSI: J10.8, U5.29 (CS3/IO5)
ESP_12/MTDI: J9.8 (NC/TDI), U5.14 (POCI2/IOA12)
ESP_13/POWER_CTRL/MTCK: J9.4 (SWDCLK/TCK), U5.16 (PICO2/IOA13); also elsewhere on the board
ESP_14/PERIPHERAL_POWER/MTMS: J9.2 (SWDIO/TMS), U5.13 (SCK2/IOA14), U12.3 (EN)
ESP_15/MTDO/RADIO_!RESET!: J9.6 (SWO/TDO), J10.5, U5.23 (CS2/IOA15)
ESP_16/ZED_TXO1: R3.2, U1.12 (X0), U5.27 (IO16)
ESP_17/ZED_RXI1: R15.2, U1.1 (Y0), U5.28 (IO17)
ESP_18/SD_SCK: J8.7, U5.30 (SCK3/IO18)
ESP_19/SD_CIPO: J8.8, U5.31 (POCI3/IO19)
ESP_21/SDA: J1.3, J8.10, J18.4, R4.2, R7.1, U1.2 (Y2), U5.33 (SDA/IO21), U7.8 (SDA); also elsewhere on the board
ESP_22/SCL: J1.4, J8.9, J18.3, R9.2, R12.1, U1.15 (X2), U5.36 (SCL/IO22), U7.7 (SCL); also elsewhere on the board
ESP_23/SD_COPI: J8.6, U5.37 (PICO3/IO23)
ESP_25/SD_!CS!: J8.5, U5.10 (DAC1/IOA25)
ESP_26/DAC2: U1.11 (X3), U5.11 (DAC2/IOA26)
ESP_27/FAST_OFF: U5.12 (IOA27); also elsewhere on the board
ESP_32/RADIO_TXO: J10.11, U5.8 (XTAL_P/IOA32)
ESP_33/RADIO_RXI: J10.10, U5.9 (XTAL_N/IOA33)
ESP_DM: U6.6 (UD-); also elsewhere on the board
ESP_DP: U6.5 (UD+); also elsewhere on the board
ESP_I34/RADIO_INT: J10.7, U5.6 (IA34)
ESP_I35/DEVICE_SENSE: R33.2, R34.1, U5.7 (IA35)
ESP_I36/RADIO_RTSO: J10.9, U5.4 (SENSOR_VP/IA36)
ESP_I39/ADC39: U1.4 (Y3), U5.5 (SENSOR_VN/IA39)
EXTERNAL_SERIAL1_RXI: J18.1, U1.3 (Y)
EXTERNAL_SERIAL1_TXO: J18.2, U1.13 (X)
FENCE_LV: R48.1, U3.19 (GEO_STAT)
GND: C2.2, C3.2, C4.2, C5.1, C6.2, C7.1, C8.2, C10.2, C11.2, C12.2, C13.2, C14.2, C15.2, C16.2, C17.2, C18.2, C25.2, C26.1, C27.2, D1.C, J1.1, J3.1, J7.1 (-), J8.1, J9.3 (GND), J9.5 (GND), J9.7 (KEY), J9.9 (GNDDTCT), J10.1, J10.2, J14.2, J15.10, J15.11, J15.12, J18.11, J18.12, R6.1, R10.1, R30.1, R33.1, U1.6 (INH), U1.7 (VEE), U1.8 (GND), U2.2 (GND), U3.1 (GND), U3.3 (GND), U3.12 (GND), U3.14 (GND), U3.32 (GND), U3.37 (GND), U3.41 (GND), U3.48 (GND), U3.55 (GND), U3.56 (GND), U3.57 (GND), U3.58 (GND), U3.59 (GND), U3.60 (GND), U3.61 (GND), U3.62 (GND), U3.63 (GND), U3.64 (GND), U3.65 (GND), U3.66 (GND), U3.67 (GND), U3.68 (GND), U3.69 (GND), U3.70 (GND), U3.71 (GND), U3.72 (GND), U3.73 (GND), U3.74 (GND), U3.75 (GND), U3.76 (GND), U3.77 (GND), U3.78 (GND), U3.79 (GND), U3.80 (GND), U3.81 (GND), U3.82 (GND), U3.83 (GND), U3.84 (GND), U3.85 (GND), U3.86 (GND), U3.87 (GND), U3.88 (GND), U3.89 (GND), U3.90 (GND), U3.91 (GND), U3.92 (GND), U3.93 (GND), U3.94 (GND), U3.95 (GND), U3.96 (GND), U3.97 (GND), U3.98 (GND), U3.99 (GND), U3.100 (GND), U3.101 (GND), U3.102 (GND), U4.2 (GND), U5.1 (GND), U5.15 (GND), U5.38 (GND), U5.GND, U5.GNDT1 (GND), U5.GNDT2 (GND), U5.GNDT3 (GND), U5.GNDT4 (GND), U5.GNDT5 (GND), U5.GNDT6 (GND), U5.GNDT7 (GND), U5.GNDT8 (GND), U6.1 (GND), U7.1 (CTG), U7.4 (GND), U7.6 (QSTRT), U7.9 (GND), U10.5 (VSS), U12.2 (GND); also elsewhere on the board
LIPO_RAW: J7.2 (+), MEAS2.1, MEAS2.3 (1)
unnamed: R8.1, U10.8 (THERM)
unnamed: D1.A, R11.1
unnamed: JP7.3, R7.2
unnamed: JP7.1, R12.2
unnamed: R2.1, U3.51 (EXTINT)
unnamed: R27.2, U3.40 (USB_D+)
unnamed: R28.2, U3.39 (USB_D-)
unnamed: R1.1, U3.49 (!RESET!)
unnamed: R50.1, U3.50 (!SAFEBOOT!)
unnamed: R14.1, U3.46 (TX_READY)
unnamed: Q2.5 (B), R23.2
unnamed: Q2.2 (B), R29.2
POWER_BTN: J8.2; also elsewhere on the board
PPS: R49.1, U3.53 (TIMEPULSE)
PROG1: R6.2, U10.6 (PROG)
RTK_LV: R47.1, U3.20 (RTK_STAT)
RX2_LV: R46.1, U3.26 (RX2)
RXLV: R15.1, U3.43 (RX/MOSI)
SCL_LV: R9.1, U3.45 (SCL/CLK)
SDA_LV: R4.1, U3.44 (SDA/!CS!)
TX2_LV: R45.1, U3.27 (TX2)
TXLV: R3.1, U3.42 (TX/MISO)
USB_DM: J18.8; also elsewhere on the board
USB_DP: J18.7; also elsewhere on the board
VOUT: C6.1, C27.1, J10.12, J15.6, J15.7, J15.8, J15.9, U2.1 (IN), U2.3 (EN), U12.1 (IN); also elsewhere on the board
V_BATT: C3.1, C15.1, C17.1, D7.A, MEAS2.2, MEAS2.4 (2), U4.1 (IN), U4.3 (EN), U7.2 (CELL), U7.3 (VDD), U10.9 (VBAT), U10.10 (VBAT)
V_RAW: C16.1, D2.C, D7.C, U10.1 (VDD), U10.2 (VDD); also elsewhere on the board
V_USB: D2.A, J8.12, J15.1, J15.2, J15.3, J15.4; also elsewhere on the board
ZED_!RESET!: R1.2
ZED_!SAFE!: R50.2
ZED_BACKUP: C18.1, U3.36 (V_BKCP), U4.5 (OUT)
ZED_DM: R28.1; also elsewhere on the board
ZED_DP: R27.1; also elsewhere on the board
ZED_EXTINT: R2.2, U1.5 (Y1)
ZED_FENCE_STAT: R48.2
ZED_PPS_STAT: J4.2, R49.2, U1.14 (X1)
ZED_RF_IN: U3.2 (RF_IN); also elsewhere on the board
ZED_RTK_STAT: R47.2
ZED_RXI2: J18.9, R46.2; also elsewhere on the board
ZED_TXO2: J18.10, R45.2; also elsewhere on the board
ZED_TX_READY: R14.2
ZED_VCC_RF: U3.7 (V_RF); also elsewhere on the board

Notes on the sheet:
v10
7-bit unshifted I²C address: 0x42
u-blox ZED-F9P
RTC Backup
No clean process
Connections
ESP32 3.3V
ESP32-WROOM
USB-to-Serial For ESP32
Data Output Selection
Fuel Gauge
From Connectors Board
From Display Board
LiPo Range: 3.6-4.2V
Charge current: 1000mA (1000V/Rprog)
Use with >1Ahr 3.7V Battery
LiPo Charger @ 1A
NCP18XH103J03RB
10k, +/-5%, B-Constant 3380
Temp Cutoff: 0C to 42C
Power Select
1.5uA Quiescent
GNSS data/almanac backup: 15uA
Peripheral 3.3V
600mA Max 55uA Quiescent
IO0: Avoid device connections. Can be used a stat LED.
ADC2 has problems when WiFi is enabled.
IO12: Avoid external pullups - will cause bootloader fail.
Use boot control pins with caution: 0, 2, 5, 12, 15
IO2: Avoid external pullups - will cause bootloader fail.
IO15: Has builtin pullup at POR.
IO5: Has builtin pullup at POR.
From Radio Board
N. Seidle
JTAG
Part#: ESP32-WROOM-32E-N16
IDs:
Surveyor: N/A
Express: 10/3.3
Express+: 3.3/10

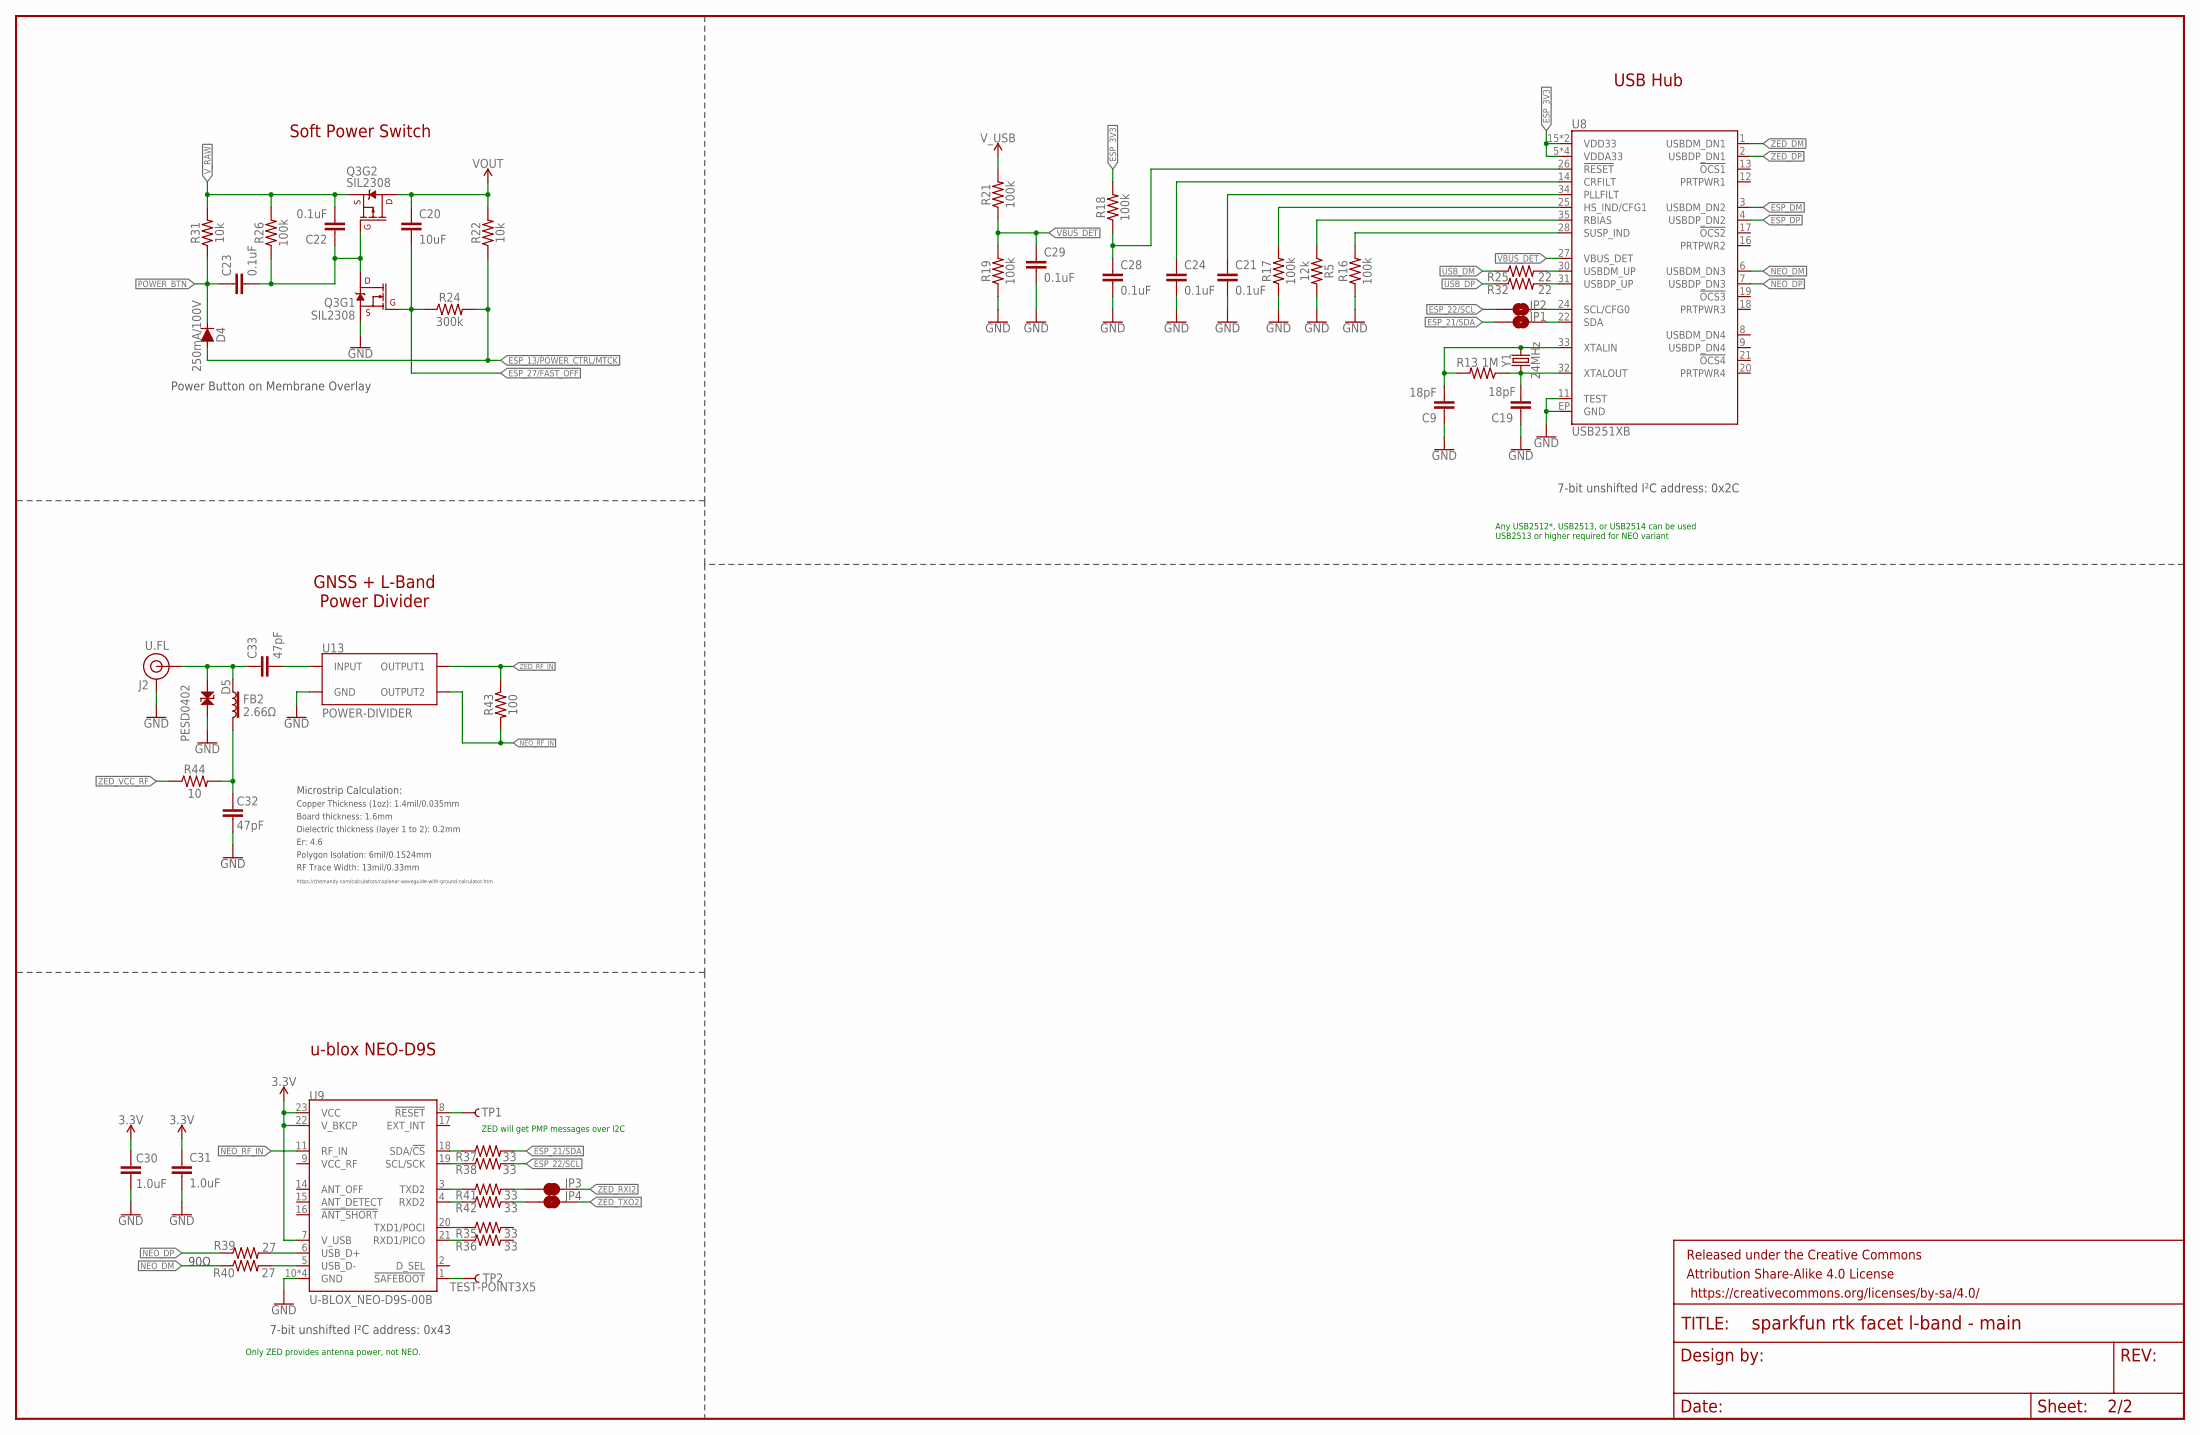
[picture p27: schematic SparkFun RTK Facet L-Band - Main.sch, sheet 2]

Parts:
C9, C19: 18pF; 0603
C20: 10uF; 0603
C21, C22, C23, C24, C28, C29: 0.1uF; 0603
C30, C31: 1.0uF; 0603
C32, C33: 47pF; 0402-TIGHT
D4: 250mA/100V; SOD-323
D5: PESD0402; 0402-TIGHT
FB2: 2.66Ω; 0402-TIGHT
FRAME1: FRAME-LEDGER; CREATIVE_COMMONS
J2: U.FL
JP1, JP2: JUMPER-SMT_2_NO_SILK; SMT-JUMPER_2_NO_SILK
JP3, JP4: JUMPER-SMT_2_NC_TRACE_SILK; SMT-JUMPER_2_NC_TRACE_SILK
Q3: SIL2308; SOT26
R5: 12k; 0603
R13: 1M; 0603
R16, R17, R18, R19, R21, R26: 100k; 0603
R22, R31: 10k; 0603
R24: 300k; 0603
R25, R32: 22; 0603
R35, R36, R37, R38, R41, R42: 33; 0603
R39, R40: 27; 0603
R43: 100; 0603
R44: 10; 0402-TIGHT
TP1, TP2: TEST-POINT3X5; PAD.03X.05
U8: USB251XB; QFN-36
U9: U-BLOX_NEO-D9S-00B; NEO-M9N/M8T/M8U/D9S/F9P
U13: POWER-DIVIDER; PD0922J5050S2HF_ANA
Y1: 24MHz; CRYSTAL-SMD-2.0X1.6MM

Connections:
3.3V: C30.1, C31.1, U9.7 (V_USB), U9.22 (V_BKCP), U9.23 (VCC); also elsewhere on the board
ESP_3V3: R18.2, U8.5 (VDDA33), U8.10 (VDDA33), U8.15 (VDD33), U8.23 (VDD33), U8.29 (VDDA33), U8.36 (VDDA33); also elsewhere on the board
ESP_13/POWER_CTRL/MTCK: D4.A, R22.1, R24.2; also elsewhere on the board
ESP_21/SDA: JP1.1, R37.2; also elsewhere on the board
ESP_22/SCL: JP2.1, R38.2; also elsewhere on the board
ESP_27/FAST_OFF: C20.2, Q3.G1 (G), R24.1; also elsewhere on the board
ESP_DM: U8.3 (USBDM_DN2); also elsewhere on the board
ESP_DP: U8.4 (USBDP_DN2); also elsewhere on the board
GND: C9.1, C19.1, C21.2, C24.2, C28.2, C29.2, C30.2, C31.2, C32.2, D5.2, J2.1 (GND), J2.2 (GND), Q3.S1 (S), R5.2, R16.1, R17.1, R19.1, U8.11 (TEST), U8.EP (GND), U9.10 (GND), U9.12 (GND), U9.13 (GND), U9.24 (GND), U13.1 (GND), U13.3 (GND), U13.5 (GND); also elsewhere on the board
unnamed: C22.1, C23.2, Q3.D1 (D), Q3.G2 (G), R26.1
unnamed: C9.2, R13.2, U8.33 (XTALIN), Y1.3 (2)
unnamed: C19.2, R13.1, U8.32 (XTALOUT), Y1.1
unnamed: R5.1, U8.35 (RBIAS)
unnamed: R16.2, U8.28 (SUSP_IND)
unnamed: JP3.1, R41.2
unnamed: R17.2, U8.25 (HS_IND/CFG1)
unnamed: C21.1, U8.34 (PLLFILT)
unnamed: C24.1, U8.14 (CRFILT)
unnamed: R25.2, U8.30 (USBDM_UP)
unnamed: R32.2, U8.31 (USBDP_UP)
unnamed: JP1.2, U8.22 (SDA)
unnamed: JP2.2, U8.24 (SCL/CFG0)
unnamed: R39.2, U9.6 (USB_D+)
unnamed: R40.2, U9.5 (USB_D-)
unnamed: R41.1, U9.3 (TXD2)
unnamed: R42.1, U9.4 (RXD2)
unnamed: R35.1, U9.20 (TXD1/POCI)
unnamed: R36.1, U9.21 (RXD1/PICO)
unnamed: R37.1, U9.18 (SDA/!CS!)
unnamed: R38.1, U9.19 (SCL/SCK)
unnamed: C32.1, FB2.2, R44.2
unnamed: JP4.1, R42.2
unnamed: C33.2, U13.2 (INPUT)
NEO_!RESET!: TP1.1, U9.8 (!RESET!)
NEO_!SAFEBOOT!: TP2.1, U9.1 (!SAFEBOOT!)
NEO_DM: R40.1, U8.6 (USBDM_DN3)
NEO_DP: R39.1, U8.7 (USBDP_DN3)
NEO_RF_IN: R43.2, U9.11 (RF_IN), U13.6 (OUTPUT2)
POWER_BTN: C23.1, D4.C, R31.1; also elsewhere on the board
RF_IN: C33.1, D5.1, FB2.1, J2.FEED (SIGNAL)
USB_!RESET: C28.1, R18.1, U8.26 (!RESET)
USB_DM: R25.1; also elsewhere on the board
USB_DP: R32.1; also elsewhere on the board
VBUS_DET: C29.1, R19.2, R21.1, U8.27 (VBUS_DET)
VOUT: C20.1, Q3.D2 (D), R22.2; also elsewhere on the board
V_RAW: C22.2, Q3.S2 (S), R26.2, R31.2; also elsewhere on the board
V_USB: R21.2; also elsewhere on the board
ZED_DM: U8.1 (USBDM_DN1); also elsewhere on the board
ZED_DP: U8.2 (USBDP_DN1); also elsewhere on the board
ZED_RF_IN: R43.1, U13.4 (OUTPUT1); also elsewhere on the board
ZED_RXI2: JP3.2; also elsewhere on the board
ZED_TXO2: JP4.2; also elsewhere on the board
ZED_VCC_RF: R44.1; also elsewhere on the board

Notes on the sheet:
Soft Power Switch
7-bit unshifted I²C address: 0x2C
USB Hub
Power Button on Membrane Overlay
Any USB2512*, USB2513, or USB2514 can be used USB2513 or higher required for NEO variant
7-bit unshifted I²C address: 0x43
u-blox NEO-D9S
90Ω
Only ZED provides antenna power, not NEO.
ZED will get PMP messages over I2C
GNSS + L-Band Power Divider
Board thickness: 1.6mm
Er: 4.6
Copper Thickness (1oz): 1.4mil/0.035mm
RF Trace Width: 13mil/0.33mm
Polygon Isolation: 6mil/0.1524mm
Dielectric thickness (layer 1 to 2): 0.2mm
https://chemandy.com/calculators/coplanar-waveguide-with-ground-calculator.htm
Microstrip Calculation:

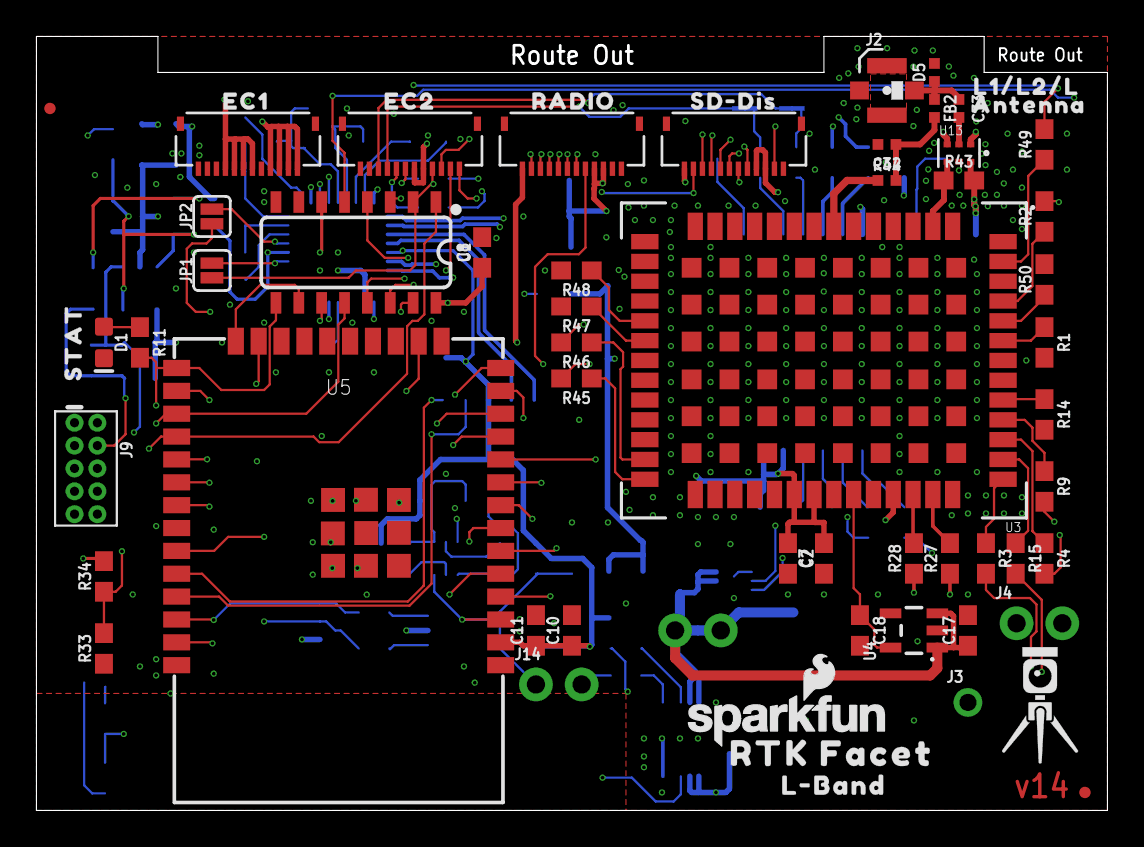
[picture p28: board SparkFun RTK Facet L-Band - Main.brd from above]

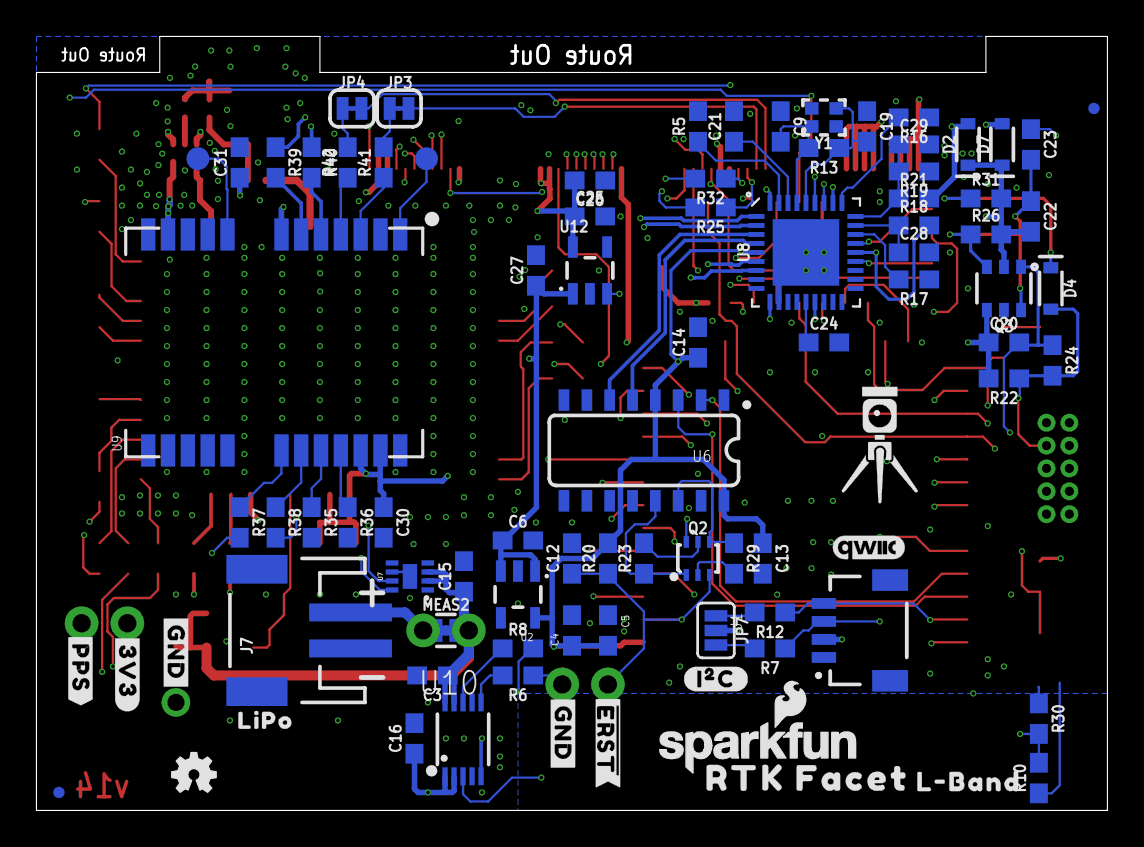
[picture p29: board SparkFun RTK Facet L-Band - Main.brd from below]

Board: 4 copper layers, 59.5 x 43.0 mm, 153 parts (89 on the bottom side), 109 nets.

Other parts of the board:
LOGO3: SFE_LOGO_NAME_FLAME.1_INCH; SFE_LOGO_NAME_FLAME_.1
U$1: LIPO0
U$3: EC21
U$4: SD#DIS0
U$5, U$7: L#BAND0
U$6: #3V3#0
U$8: EC10
U$10: #PPS#1
U$11, U$13: RTK_FACET0
U$12: RADIO0
U$14, U$84: #GND#1
U$15, U$16: RTK5#SVG0
U$17: ANTENNA1
U$18: L1#L2#L0
U$24: STAT0
U$25: #I�C#0
U$26: ##ERST##0
U$30: QWIIC_4MM

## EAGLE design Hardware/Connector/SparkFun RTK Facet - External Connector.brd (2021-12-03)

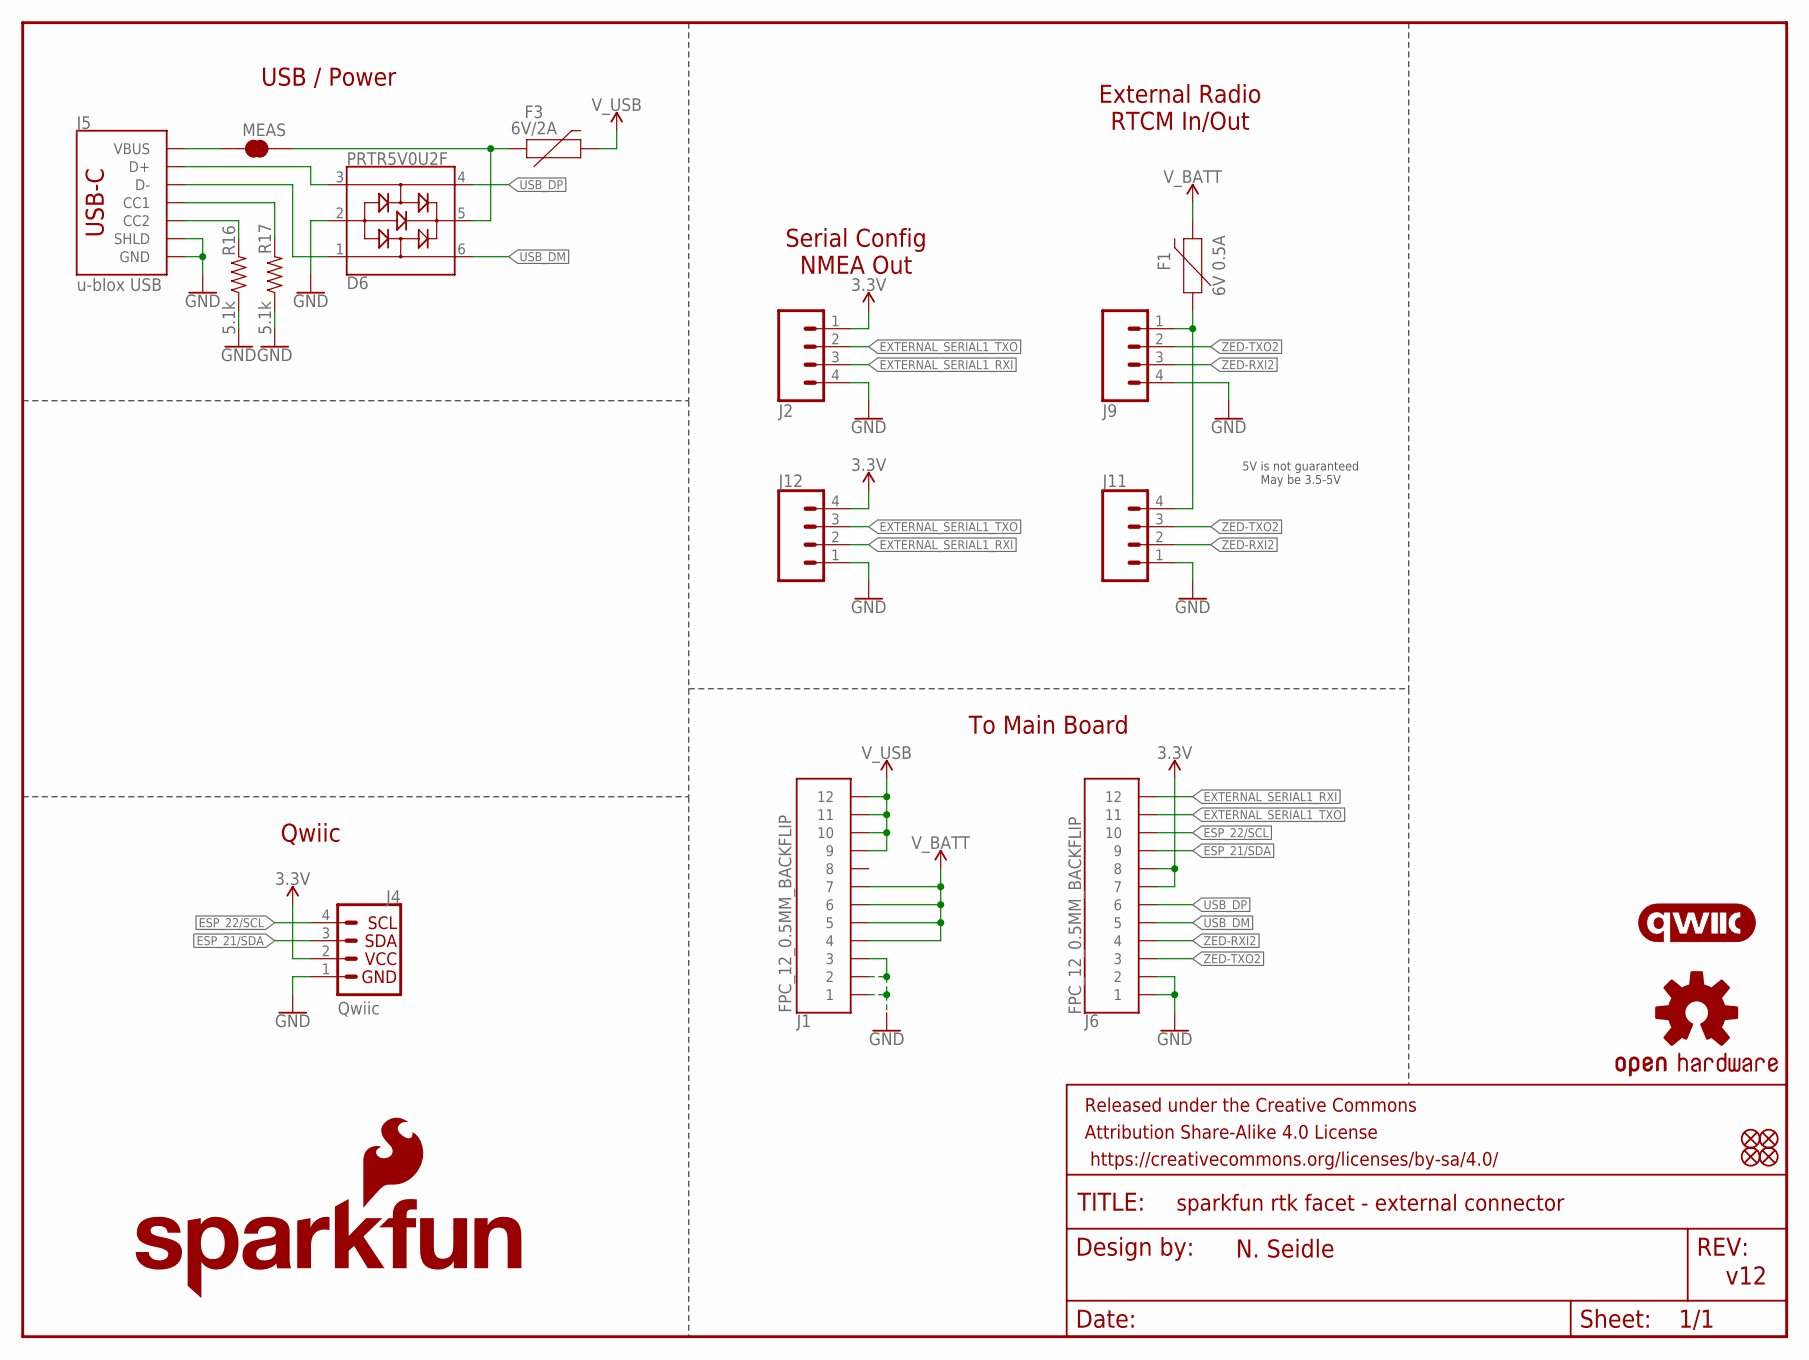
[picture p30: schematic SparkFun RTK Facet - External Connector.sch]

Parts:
D6: PRTR5V0U2F; SOT886
F1: 6V 0.5A; 0805
F3: 6V/2A; 1210
FRAME1: FRAME-LETTER; CREATIVE_COMMONS
J1, J6: FPC_12_0.5MM_BACKFLIP; FPC_12_DOUBLESIDED_BACKFLIP
J2, J9: CONN_04JST-SMD-LOCKING; JST-4-SMD-1.25MM-LOCKING
J4: Qwiic; JST04_1MM_RA
J5: u-blox USB; USB-C-16P-2LAYER-PADS
J11, J12: CONN_041X04_NO_SILK_NO_POP; 1X04_NO_SILK
JP21, JP61, JP71, JP81: FIDUCIALUFIDUCIAL; FIDUCIAL-MICRO
LOGO1: OSHW-LOGOMINI; OSHW-LOGO-MINI
LOGO2: SFE_LOGO_NAME_FLAME.1_INCH; SFE_LOGO_NAME_FLAME_.1
LOGO3: QWIIC_LOGO_CONNECTOR; QWIIC_5.5MM
MEAS: JUMPER-COMBO_2_NC_TRACE; COMBO-JUMPER_2_NC_TRACE
R16, R17: 5.1k; 0603

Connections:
3.3V: J2.1, J4.2, J6.7, J6.8, J12.4
CC1: J5.A5 (CC1), R17.2
CC2: J5.B5 (CC2), R16.2
ESP_21/SDA: J4.3, J6.9
ESP_22/SCL: J4.4, J6.10
EXTERNAL_SERIAL1_RXI: J2.3, J6.12, J12.2
EXTERNAL_SERIAL1_TXO: J2.2, J6.11, J12.3
GND: D6.2, J1.1, J1.2, J1.3, J2.4, J4.1, J5.GND, J5.GND2 (GND), J5.SHLD1 (SHLD), J5.SHLD2 (SHLD), J5.SHLD3 (SHLD), J5.SHLD4 (SHLD), J6.1, J6.2, J9.4, J11.1, J12.1, R16.1, R17.1
unnamed: F1.1, J9.1, J11.4
USB1_D_M: D6.1, J5.A7 (D-), J5.B7 (D-)
USB1_D_P: D6.3, J5.A6 (D+), J5.B6 (D+)
USB_DM: D6.6, J6.5
USB_DP: D6.4, J6.6
VIN: J5.VBUS1 (VBUS), J5.VBUS2 (VBUS), MEAS.1, MEAS.3 (1)
VIN1: D6.5, F3.1, MEAS.2, MEAS.4 (2)
V_BATT: F1.2, J1.4, J1.5, J1.6, J1.7
V_USB: F3.2, J1.9, J1.10, J1.11, J1.12
ZED-RXI2: J6.4, J9.3, J11.2
ZED-TXO2: J6.3, J9.2, J11.3

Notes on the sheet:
v12
USB / Power
External Radio RTCM In/Out
Serial Config NMEA Out
5V is not guaranteed May be 3.5-5V
To Main Board
Qwiic
N. Seidle



Board: 2 copper layers, 53.0 x 23.0 mm, 42 parts (8 on the bottom side), 19 nets.

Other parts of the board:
U$1: USB0
U$2: CONNECTORS1
U$3, U$13: RTK5#SVG0
U$4: EXT10
U$5: #3V3#0
U$6: EXT22
U$7: NMEA1
U$8: EC10
U$9: EXTERNAL0
U$11: EC21
U$12: RADIO3
U$14: RTK_FACET0
U$23: #3#5#5V#0
U$38, U$82: #GND#0
U$39: #RX2#2
U$40: #TX2#1
U$65: #TX1#1
U$68: #RX1#2

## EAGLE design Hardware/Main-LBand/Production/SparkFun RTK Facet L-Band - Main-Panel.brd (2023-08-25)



Board: 4 copper layers, 139.6 x 187.7 mm, 1206 parts (715 on the bottom side), 872 nets.

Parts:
C1, C2, C4, C6, C17, C18, C25, C27, C30, C31, C35, C36, C44, C45, C52, C54, C61, C62, C65, C67, C68, C76, C77, C84, C86, C93, C94, C97, C99, C100, C108, C109, C116, C118, C125, C126, C129, C131, C132, C140, C141, C148, C150, C157, C158, C161, C163, C164, C172, C173, C180, C182, C189, C190, C193, C195, C196, C204, C205, C212, C214, C221, C222, C225, C227, C228, C236, C237, C244, C246, C253, C254: 1.0uF; 0603
C3, C16, C46, C47, C78, C79, C110, C111, C142, C143, C174, C175, C206, C207, C238, C239: 4.7uF; 0603
C5, C7, C8, C11, C12, C13, C15, C21, C22, C23, C24, C26, C28, C29, C34, C37, C39, C40, C41, C43, C48, C50, C51, C53, C57, C58, C59, C60, C66, C69, C71, C72, C73, C75, C80, C82, C83, C85, C89, C90, C91, C92, C98, C101, C103, C104, C105, C107, C112, C114, C115, C117, C121, C122, C123, C124, C130, C133, C135, C136, C137, C139, C144, C146, C147, C149, C153, C154, C155, C156, C162, C165, C167, C168, C169, C171, C176, C178, C179, C181, C185, C186, C187, C188, C194, C197, C199, C200, C201, C203, C208, C210, C211, C213, C217, C218, C219, C220, C226, C229, C231, C232, C233, C235, C240, C242, C243, C245, C249, C250, C251, C252: 0.1uF; 0603
C9, C19, C55, C56, C87, C88, C119, C120, C151, C152, C183, C184, C215, C216, C247, C248: 18pF; 0603
C10, C14, C20, C38, C42, C49, C70, C74, C81, C102, C106, C113, C134, C138, C145, C166, C170, C177, C198, C202, C209, C230, C234, C241: 10uF; 0603
C32, C33, C63, C64, C95, C96, C127, C128, C159, C160, C191, C192, C223, C224, C255, C256: 47pF; 0402-TIGHT
D1, D3, D11, D16, D21, D26, D31, D36: Yellow; LED-0603
D2, D7, D8, D9, D13, D14, D18, D19, D23, D24, D28, D29, D33, D34, D38, D39: 3A/10V/280mV; SOD-323
D4, D6, D12, D17, D22, D27, D32, D37: 250mA/100V; SOD-323
D5, D10, D15, D20, D25, D30, D35, D40: PESD0402; 0402-TIGHT
E$1, E$2, E$3, E$4: FIDUCIAL-1X2
E$5, E$6: FIDUCIAL-1.5X3
FB1, FB2, FB3, FB4, FB5, FB6, FB7, FB8: 2.66Ω; 0402-TIGHT
J1, J13, J27, J38, J49, J60, J71, J82: QWIIC_RIGHT_ANGLE; JST04_1MM_RA
J2, J22, J33, J44, J55, J66, J77, J88: U.FL
J3, J19, J30, J41, J52, J63, J74, J85: 1X01_NO_SILK
J4, J5, J14, J16, J23, J28, J34, J39, J45, J50, J56, J61, J67, J72, J78, J83: 1X02_NO_SILK
J6, J7, J24, J35, J46, J57, J68, J79: JST-2-SMD
J8, J10, J11, J12, J15, J17, J18, J21, J25, J26, J29, J32, J36, J37, J40, J43, J47, J48, J51, J54, J58, J59, J62, J65, J69, J70, J73, J76, J80, J81, J84, J87: FPC_12_DOUBLESIDED_BACKFLIP
J9, J20, J31, J42, J53, J64, J75, J86: CORTEX_JTAG_DEBUG_PTH; 2X5-PTH-1.27MM
JP1, JP2, JP11, JP12, JP20, JP22, JP30, JP31, JP39, JP40, JP48, JP49, JP57, JP58, JP67, JP68: SMT-JUMPER_2_NO_SILK
JP3, JP4, JP13, JP14, JP23, JP24, JP32, JP33, JP41, JP42, JP50, JP51, JP59, JP60, JP69, JP70: SMT-JUMPER_2_NC_TRACE_SILK
JP5, JP6, JP8, JP9, JP15, JP16, JP17, JP18, JP21, JP25, JP26, JP27, JP28, JP34, JP35, JP36, JP37, JP43, JP44, JP45, JP46, JP52, JP53, JP54, JP55, JP61, JP62, JP63, JP64, JP65, JP71, JP81: FIDUCIALUFIDUCIAL; FIDUCIAL-MICRO
JP7, JP10, JP19, JP29, JP38, JP47, JP56, JP66: JUMPER-SMT_3_NO_SILK; SMT-JUMPER_3_NO_SILK
LOGO1, LOGO4, LOGO7, LOGO10, LOGO13, LOGO16, LOGO19, LOGO22: OSHW-LOGOMINI; OSHW-LOGO-MINI
LOGO2, LOGO3, LOGO5, LOGO6, LOGO8, LOGO9, LOGO11, LOGO12, LOGO14, LOGO15, LOGO17, LOGO18, LOGO20, LOGO21, LOGO23, LOGO24: SFE_LOGO_NAME_FLAME.1_INCH; SFE_LOGO_NAME_FLAME_.1
MEAS1, MEAS2, MEAS3, MEAS4, MEAS5, MEAS6, MEAS7, MEAS8: JUMPER-COMBO_2_NC_TRACE; COMBO-JUMPER_2_NC_TRACE
Q1, Q2, Q5, Q7, Q9, Q11, Q13, Q15: MBT3904DW1T1; SC70-6
Q3, Q4, Q6, Q8, Q10, Q12, Q14, Q16: SIL2308; SOT26
R1, R2, R3, R4, R9, R14, R15, R35, R36, R37, R38, R41, R42, R45, R46, R47, R48, R49, R50, R54, R79, R80, R81, R82, R85, R86, R89, R90, R91, R92, R93, R94, R95, R96, R97, R98, R99, R100, R104, R129, R130, R131, R132, R135, R136, R139, R140, R141, R142, R143, R144, R145, R146, R147, R148, R149, R150, R154, R179, R180, R181, R182, R185, R186, R189, R190, R191, R192, R193, R194, R195, R196, R197, R198, R199, R200, R204, R229, R230, R231, R232, R235, R236, R239, R240, R241, R242, R243, R244, R245, R246, R247, R248, R249, R250, R254, R279, R280, R281, R282, R285, R286, R289, R290, R291, R292, R293, R294, R295, R296, R297, R298, R299, R300, R304, R329, R330, R331, R332, R335, R336, R339, R340, R341, R342, R343, R344, R345, R346, R347, R348, R349, R350, R354, R379, R380, R381, R382, R385, R386, R389, R390, R391, R392, R393, R394, R395, R396, R397, R398, R399, R400: 33; 0603
R5, R68, R118, R168, R218, R268, R318, R368: 12k; 0603
R6, R11, R51, R58, R101, R108, R151, R158, R201, R208, R251, R258, R301, R308, R351, R358: 1k; 0603
R7, R12, R62, R63, R112, R113, R162, R163, R212, R213, R262, R263, R312, R313, R362, R363: 2.2k; 0603
R8, R60, R110, R160, R210, R260, R310, R360: 0; 0603
R10, R20, R22, R23, R29, R31, R34, R55, R56, R57, R61, R64, R67, R78, R105, R106, R107, R111, R114, R117, R128, R155, R156, R157, R161, R164, R167, R178, R205, R206, R207, R211, R214, R217, R228, R255, R256, R257, R261, R264, R267, R278, R305, R306, R307, R311, R314, R317, R328, R355, R356, R357, R361, R364, R367, R378: 10k; 0603
R13, R69, R119, R169, R219, R269, R319, R369: 1M; 0603
R16, R17, R18, R19, R21, R26, R33, R66, R70, R71, R72, R73, R74, R77, R116, R120, R121, R122, R123, R124, R127, R166, R170, R171, R172, R173, R174, R177, R216, R220, R221, R222, R223, R224, R227, R266, R270, R271, R272, R273, R274, R277, R316, R320, R321, R322, R323, R324, R327, R366, R370, R371, R372, R373, R374, R377: 100k; 0603
R24, R65, R115, R165, R215, R265, R315, R365: 300k; 0603
R25, R32, R75, R76, R125, R126, R175, R176, R225, R226, R275, R276, R325, R326, R375, R376: 22; 0603
R27, R28, R39, R40, R52, R53, R83, R84, R102, R103, R133, R134, R152, R153, R183, R184, R202, R203, R233, R234, R252, R253, R283, R284, R302, R303, R333, R334, R352, R353, R383, R384: 27; 0603
R30, R59, R109, R159, R209, R259, R309, R359: 150k; 0603
R43, R88, R138, R188, R238, R288, R338, R388: 100; 0603
R44, R87, R137, R187, R237, R287, R337, R387: 10; 0402-TIGHT
TP1, TP2, TP3, TP4, TP5, TP6, TP7, TP8, TP9, TP10, TP11, TP12, TP13, TP14, TP15, TP16: TEST-POINT3X5; PAD.03X.05
U1, U18, U30, U42, U54, U66, U78, U90: 74HC4052D; SO16
U2, U11, U12, U20, U25, U32, U37, U44, U49, U56, U61, U68, U73, U80, U85, U92: AP2112K-3.3V; SOT23-5
U3, U14, U26, U38, U50, U62, U74, U86: U-BLOX_ZED-F9P; ZED-F9P
U4, U19, U31, U43, U55, U67, U79, U91: STLQ015-3.3V; SOT23-5
U5, U22, U34, U46, U58, U70, U82, U94: ESP-WROOM-3232D-DFMP; ESP-WROOM-32D-DFM_PASTE
U6, U15, U27, U39, U51, U63, U75, U87: CH340C; SO016
U7, U16, U28, U40, U52, U64, U76, U88: MAX17048; DFN-8
U8, U21, U33, U45, U57, U69, U81, U93: USB251XB; QFN-36
U9, U23, U35, U47, U59, U71, U83, U95: U-BLOX_NEO-D9S-00B; NEO-M9N/M8T/M8U/D9S/F9P
U10, U17, U29, U41, U53, U65, U77, U89: MCP73833MSOP; MSOP10
U13, U24, U36, U48, U60, U72, U84, U96: POWER-DIVIDER; PD0922J5050S2HF_ANA
U$1, U$22, U$47, U$68, U$90, U$111, U$132, U$153: LIPO0
U$2, U$30, U$42, U$63, U$85, U$106, U$127, U$148: QWIIC_4MM
U$3, U$20, U$45, U$66, U$88, U$109, U$130, U$151: EC21
U$4, U$21, U$46, U$67, U$89, U$110, U$131, U$152: SD#DIS0
U$5, U$7, U$40, U$41, U$61, U$62, U$82, U$83, U$104, U$105, U$125, U$126, U$146, U$147, U$167, U$168: L#BAND0
U$6, U$23, U$48, U$69, U$91, U$112, U$133, U$154: #3V3#0
U$8, U$19, U$44, U$65, U$87, U$108, U$129, U$150: EC10
U$9, U$14, U$35, U$43, U$56, U$64, U$77, U$84, U$86, U$99, U$107, U$120, U$128, U$141, U$149, U$162: #GND#1
U$10, U$27, U$49, U$70, U$92, U$113, U$134, U$155: #PPS#1
U$11, U$13, U$32, U$34, U$53, U$55, U$74, U$76, U$96, U$98, U$117, U$119, U$138, U$140, U$159, U$161: RTK_FACET0
U$12, U$33, U$54, U$75, U$97, U$118, U$139, U$160: RADIO0
U$15, U$16, U$36, U$37, U$57, U$58, U$78, U$79, U$100, U$101, U$121, U$122, U$142, U$143, U$163, U$164: RTK5#SVG0
U$17, U$38, U$59, U$80, U$102, U$123, U$144, U$165: ANTENNA1
U$18, U$39, U$60, U$81, U$103, U$124, U$145, U$166: L1#L2#L0
U$24, U$28, U$50, U$71, U$93, U$114, U$135, U$156: STAT0
U$25, U$29, U$51, U$72, U$94, U$115, U$136, U$157: #I�C#0
U$26, U$31, U$52, U$73, U$95, U$116, U$137, U$158: ##ERST##0
Y1, Y2, Y3, Y4, Y5, Y6, Y7, Y8: 24MHz; CRYSTAL-SMD-2.0X1.6MM

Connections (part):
3.3V: C2.1, C7.2, C8.1, C25.1, C26.2, C30.1, C31.1, J1.2, J4.1, J8.3, J8.4, J10.3, J10.4, J18.5, J18.6, JP7.2, U1.16, U3.33, U3.34, U3.38, U9.7, U9.22, U9.23, U12.5
3.3V1: C36.1, C37.2, C48.1, C52.1, C53.2, C61.1, C62.1, J12.5, J12.6, J13.2, J16.1, J17.3, J17.4, J21.3, J21.4, JP10.2, U14.33, U14.34, U14.38, U18.16, U20.5, U23.7, U23.22, U23.23
3.3V2: C68.1, C69.2, C80.1, C84.1, C85.2, C93.1, C94.1, J26.5, J26.6, J27.2, J28.1, J29.3, J29.4, J32.3, J32.4, JP19.2, U26.33, U26.34, U26.38, U30.16, U32.5, U35.7, U35.22, U35.23
3.3V3: C100.1, C101.2, C112.1, C116.1, C117.2, C125.1, C126.1, J37.5, J37.6, J38.2, J39.1, J40.3, J40.4, J43.3, J43.4, JP29.2, U38.33, U38.34, U38.38, U42.16, U44.5, U47.7, U47.22, U47.23
3.3V4: C132.1, C133.2, C144.1, C148.1, C149.2, C157.1, C158.1, J48.5, J48.6, J49.2, J50.1, J51.3, J51.4, J54.3, J54.4, JP38.2, U50.33, U50.34, U50.38, U54.16, U56.5, U59.7, U59.22, U59.23
3.3V5: C164.1, C165.2, C176.1, C180.1, C181.2, C189.1, C190.1, J59.5, J59.6, J60.2, J61.1, J62.3, J62.4, J65.3, J65.4, JP47.2, U62.33, U62.34, U62.38, U66.16, U68.5, U71.7, U71.22, U71.23
3.3V6: C196.1, C197.2, C208.1, C212.1, C213.2, C221.1, C222.1, J70.5, J70.6, J71.2, J72.1, J73.3, J73.4, J76.3, J76.4, JP56.2, U74.33, U74.34, U74.38, U78.16, U80.5, U83.7, U83.22, U83.23
3.3V7: C228.1, C229.2, C240.1, C244.1, C245.2, C253.1, C254.1, J81.5, J81.6, J82.2, J83.1, J84.3, J84.4, J87.3, J87.4, JP66.2, U86.33, U86.34, U86.38, U90.16, U92.5, U95.7, U95.22, U95.23
CHG_LED: J8.11, U10.3
CHG_LED1: J17.11, U17.3
CHG_LED2: J29.11, U29.3
CHG_LED3: J40.11, U41.3
CHG_LED4: J51.11, U53.3
CHG_LED5: J62.11, U65.3
CHG_LED6: J73.11, U77.3
CHG_LED7: J84.11, U89.3
CHG_THERM1: R8.2, R10.2, R30.2
CHG_THERM2: R59.2, R60.2, R61.2
CHG_THERM3: R109.2, R110.2, R111.2
CHG_THERM4: R159.2, R160.2, R161.2
CHG_THERM5: R209.2, R210.2, R211.2
CHG_THERM6: R259.2, R260.2, R261.2
CHG_THERM7: R309.2, R310.2, R311.2
CHG_THERM8: R359.2, R360.2, R361.2
ESP32_!DTR: Q2.1, R23.1, U6.13
ESP32_!DTR1: Q1.1, R56.1, U15.13
ESP32_!DTR2: Q5.1, R106.1, U27.13
ESP32_!DTR3: Q7.1, R156.1, U39.13
ESP32_!DTR4: Q9.1, R206.1, U51.13
ESP32_!DTR5: Q11.1, R256.1, U63.13
ESP32_!DTR6: Q13.1, R306.1, U75.13
ESP32_!DTR7: Q15.1, R356.1, U87.13
ESP32_!RTS: Q2.4, R29.1, U6.14
ESP32_!RTS1: Q1.4, R57.1, U15.14
ESP32_!RTS2: Q5.4, R107.1, U27.14
ESP32_!RTS3: Q7.4, R157.1, U39.14
ESP32_!RTS4: Q9.4, R207.1, U51.14
ESP32_!RTS5: Q11.4, R257.1, U63.14
ESP32_!RTS6: Q13.4, R307.1, U75.14
ESP32_!RTS7: Q15.4, R357.1, U87.14
ESP32_EN: C12.1, J9.10, J14.1, Q2.3, R20.1, U5.3
ESP32_EN1: C40.1, J5.1, J20.10, Q1.3, R55.1, U22.3
ESP32_EN2: C72.1, J23.1, J31.10, Q5.3, R105.1, U34.3
ESP32_EN3: C104.1, J34.1, J42.10, Q7.3, R155.1, U46.3
ESP32_EN4: C136.1, J45.1, J53.10, Q9.3, R205.1, U58.3
ESP32_EN5: C168.1, J56.1, J64.10, Q11.3, R255.1, U70.3
ESP32_EN6: C200.1, J67.1, J75.10, Q13.3, R305.1, U82.3
ESP32_EN7: C232.1, J78.1, J86.10, Q15.3, R355.1, U94.3
ESP32_RXI: U5.34, U6.2
ESP32_RXI1: U15.2, U22.34
ESP32_RXI2: U27.2, U34.34
ESP32_RXI3: U39.2, U46.34
ESP32_RXI4: U51.2, U58.34
ESP32_RXI5: U63.2, U70.34
ESP32_RXI6: U75.2, U82.34
ESP32_RXI7: U87.2, U94.34
ESP32_TXO: U5.35, U6.3
ESP32_TXO1: U15.3, U22.35
ESP32_TXO2: U27.3, U34.35
ESP32_TXO3: U39.3, U46.35
ESP32_TXO4: U51.3, U58.35
ESP32_TXO5: U63.3, U70.35
ESP32_TXO6: U75.3, U82.35
ESP32_TXO7: U87.3, U94.35
ESP_0/BOOT/STAT_LED/MUX_B: Q2.6, R11.2, U1.9, U5.25
ESP_0/BOOT/STAT_LED/MUX_B1: Q1.6, R51.2, U18.9, U22.25
ESP_0/BOOT/STAT_LED/MUX_B2: Q5.6, R101.2, U30.9, U34.25
ESP_0/BOOT/STAT_LED/MUX_B3: Q7.6, R151.2, U42.9, U46.25
ESP_0/BOOT/STAT_LED/MUX_B4: Q9.6, R201.2, U54.9, U58.25
ESP_0/BOOT/STAT_LED/MUX_B5: Q11.6, R251.2, U66.9, U70.25
ESP_0/BOOT/STAT_LED/MUX_B6: Q13.6, R301.2, U78.9, U82.25
ESP_0/BOOT/STAT_LED/MUX_B7: Q15.6, R351.2, U90.9, U94.25
ESP_2/MUX_A: U1.10, U5.24
ESP_2/MUX_A1: U18.10, U22.24
ESP_2/MUX_A2: U30.10, U34.24
ESP_2/MUX_A3: U42.10, U46.24
ESP_2/MUX_A4: U54.10, U58.24
ESP_2/MUX_A5: U66.10, U70.24
ESP_2/MUX_A6: U78.10, U82.24
ESP_2/MUX_A7: U90.10, U94.24
ESP_3V1: C1.1, C34.2, C38.1, C39.1, C41.1, C42.1, J20.1, R55.2, R72.2, R78.2, U11.5, U15.4, U15.16, U21.5, U21.10, U21.15, U21.23, U21.29, U21.36, U22.2
ESP_3V2: C65.1, C66.2, C70.1, C71.1, C73.1, C74.1, J31.1, R105.2, R122.2, R128.2, U25.5, U27.4, U27.16, U33.5, U33.10, U33.15, U33.23, U33.29, U33.36, U34.2
ESP_3V3: C4.1, C5.2, C10.1, C11.1, C13.1, C14.1, J9.1, R18.2, R20.2, R34.2, U2.5, U5.2, U6.4, U6.16, U8.5, U8.10, U8.15, U8.23, U8.29, U8.36
ESP_3V4: C97.1, C98.2, C102.1, C103.1, C105.1, C106.1, J42.1, R155.2, R172.2, R178.2, U37.5, U39.4, U39.16, U45.5, U45.10, U45.15, U45.23, U45.29, U45.36, U46.2
ESP_3V5: C129.1, C130.2, C134.1, C135.1, C137.1, C138.1, J53.1, R205.2, R222.2, R228.2, U49.5, U51.4, U51.16, U57.5, U57.10, U57.15, U57.23, U57.29, U57.36, U58.2
ESP_3V6: C161.1, C162.2, C166.1, C167.1, C169.1, C170.1, J64.1, R255.2, R272.2, R278.2, U61.5, U63.4, U63.16, U69.5, U69.10, U69.15, U69.23, U69.29, U69.36, U70.2
ESP_3V7: C193.1, C194.2, C198.1, C199.1, C201.1, C202.1, J75.1, R305.2, R322.2, R328.2, U73.5, U75.4, U75.16, U81.5, U81.10, U81.15, U81.23, U81.29, U81.36, U82.2
ESP_3V8: C225.1, C226.2, C230.1, C231.1, C233.1, C234.1, J86.1, R355.2, R372.2, R378.2, U85.5, U87.4, U87.16, U93.5, U93.10, U93.15, U93.23, U93.29, U93.36, U94.2
ESP_4/RADIO_PWR_ON: J10.6, U5.26
ESP_4/RADIO_PWR_ON1: J21.6, U22.26
ESP_4/RADIO_PWR_ON2: J32.6, U34.26
ESP_4/RADIO_PWR_ON3: J43.6, U46.26
ESP_4/RADIO_PWR_ON4: J54.6, U58.26
ESP_4/RADIO_PWR_ON5: J65.6, U70.26
ESP_4/RADIO_PWR_ON6: J76.6, U82.26
ESP_4/RADIO_PWR_ON7: J87.6, U94.26
ESP_5/RADIO_CTSI: J10.8, U5.29
ESP_5/RADIO_CTSI1: J21.8, U22.29
ESP_5/RADIO_CTSI2: J32.8, U34.29
ESP_5/RADIO_CTSI3: J43.8, U46.29
ESP_5/RADIO_CTSI4: J54.8, U58.29
ESP_5/RADIO_CTSI5: J65.8, U70.29
ESP_5/RADIO_CTSI6: J76.8, U82.29
ESP_5/RADIO_CTSI7: J87.8, U94.29
ESP_12/MTDI: J9.8, U5.14
ESP_12/MTDI1: J20.8, U22.14
ESP_12/MTDI2: J31.8, U34.14
ESP_12/MTDI3: J42.8, U46.14
ESP_12/MTDI4: J53.8, U58.14
ESP_12/MTDI5: J64.8, U70.14
ESP_12/MTDI6: J75.8, U82.14
ESP_12/MTDI7: J86.8, U94.14
ESP_13/POWER_CTRL/MTCK: D4.A, J9.4, R22.1, R24.2, U5.16
ESP_13/POWER_CTRL/MTCK1: D6.A, J20.4, R64.1, R65.2, U22.16
ESP_13/POWER_CTRL/MTCK2: D12.A, J31.4, R114.1, R115.2, U34.16
ESP_13/POWER_CTRL/MTCK3: D17.A, J42.4, R164.1, R165.2, U46.16
ESP_13/POWER_CTRL/MTCK4: D22.A, J53.4, R214.1, R215.2, U58.16
ESP_13/POWER_CTRL/MTCK5: D27.A, J64.4, R264.1, R265.2, U70.16
ESP_13/POWER_CTRL/MTCK6: D32.A, J75.4, R314.1, R315.2, U82.16
ESP_13/POWER_CTRL/MTCK7: D37.A, J86.4, R364.1, R365.2, U94.16
ESP_14/PERIPHERAL_POWER/MTMS: J9.2, U5.13, U12.3
ESP_14/PERIPHERAL_POWER/MTMS1: J20.2, U20.3, U22.13
ESP_14/PERIPHERAL_POWER/MTMS2: J31.2, U32.3, U34.13
ESP_14/PERIPHERAL_POWER/MTMS3: J42.2, U44.3, U46.13
ESP_14/PERIPHERAL_POWER/MTMS4: J53.2, U56.3, U58.13
ESP_14/PERIPHERAL_POWER/MTMS5: J64.2, U68.3, U70.13
ESP_14/PERIPHERAL_POWER/MTMS6: J75.2, U80.3, U82.13
ESP_14/PERIPHERAL_POWER/MTMS7: J86.2, U92.3, U94.13
ESP_15/MTDO/RADIO_!RESET!: J9.6, J10.5, U5.23
ESP_15/MTDO/RADIO_!RESET!1: J20.6, J21.5, U22.23
ESP_15/MTDO/RADIO_!RESET!2: J31.6, J32.5, U34.23
ESP_15/MTDO/RADIO_!RESET!3: J42.6, J43.5, U46.23
ESP_15/MTDO/RADIO_!RESET!4: J53.6, J54.5, U58.23
ESP_15/MTDO/RADIO_!RESET!5: J64.6, J65.5, U70.23
ESP_15/MTDO/RADIO_!RESET!6: J75.6, J76.5, U82.23
ESP_15/MTDO/RADIO_!RESET!7: J86.6, J87.5, U94.23
ESP_16/ZED_TXO1: R3.2, U1.12, U5.27
ESP_16/ZED_TXO2: R54.2, U18.12, U22.27
ESP_16/ZED_TXO3: R104.2, U30.12, U34.27
ESP_16/ZED_TXO4: R154.2, U42.12, U46.27
ESP_16/ZED_TXO5: R204.2, U54.12, U58.27
ESP_16/ZED_TXO6: R254.2, U66.12, U70.27
ESP_16/ZED_TXO7: R304.2, U78.12, U82.27
ESP_16/ZED_TXO8: R354.2, U90.12, U94.27
ESP_17/ZED_RXI1: R15.2, U1.1, U5.28
ESP_17/ZED_RXI2: R94.2, U18.1, U22.28
ESP_17/ZED_RXI3: R144.2, U30.1, U34.28
ESP_17/ZED_RXI4: R194.2, U42.1, U46.28
ESP_17/ZED_RXI5: R244.2, U54.1, U58.28
ESP_17/ZED_RXI6: R294.2, U66.1, U70.28
ESP_17/ZED_RXI7: R344.2, U78.1, U82.28
ESP_17/ZED_RXI8: R394.2, U90.1, U94.28
ESP_18/SD_SCK: J8.7, U5.30
ESP_18/SD_SCK1: J17.7, U22.30
ESP_18/SD_SCK2: J29.7, U34.30
ESP_18/SD_SCK3: J40.7, U46.30
ESP_18/SD_SCK4: J51.7, U58.30
ESP_18/SD_SCK5: J62.7, U70.30
ESP_18/SD_SCK6: J73.7, U82.30
ESP_18/SD_SCK7: J84.7, U94.30
ESP_19/SD_CIPO: J8.8, U5.31
ESP_19/SD_CIPO1: J17.8, U22.31
ESP_19/SD_CIPO2: J29.8, U34.31
ESP_19/SD_CIPO3: J40.8, U46.31
ESP_19/SD_CIPO4: J51.8, U58.31
ESP_19/SD_CIPO5: J62.8, U70.31
ESP_19/SD_CIPO6: J73.8, U82.31
ESP_19/SD_CIPO7: J84.8, U94.31
ESP_21/SDA: J1.3, J8.10, J18.4, JP1.1, R4.2, R7.1, R37.2, U1.2, U5.33, U7.8
ESP_21/SDA1: J12.4, J13.3, J17.10, JP11.1, R62.1, R81.2, R91.2, U16.8, U18.2, U22.33
ESP_21/SDA2: J26.4, J27.3, J29.10, JP20.1, R112.1, R131.2, R141.2, U28.8, U30.2, U34.33
ESP_21/SDA3: J37.4, J38.3, J40.10, JP30.1, R162.1, R181.2, R191.2, U40.8, U42.2, U46.33
ESP_21/SDA4: J48.4, J49.3, J51.10, JP39.1, R212.1, R231.2, R241.2, U52.8, U54.2, U58.33
ESP_21/SDA5: J59.4, J60.3, J62.10, JP48.1, R262.1, R281.2, R291.2, U64.8, U66.2, U70.33
ESP_21/SDA6: J70.4, J71.3, J73.10, JP57.1, R312.1, R331.2, R341.2, U76.8, U78.2, U82.33
ESP_21/SDA7: J81.4, J82.3, J84.10, JP67.1, R362.1, R381.2, R391.2, U88.8, U90.2, U94.33
ESP_22/SCL: J1.4, J8.9, J18.3, JP2.1, R9.2, R12.1, R38.2, U1.15, U5.36, U7.7
ESP_22/SCL1: J12.3, J13.4, J17.9, JP12.1, R63.1, R82.2, R92.2, U16.7, U18.15, U22.36
ESP_22/SCL2: J26.3, J27.4, J29.9, JP22.1, R113.1, R132.2, R142.2, U28.7, U30.15, U34.36
ESP_22/SCL3: J37.3, J38.4, J40.9, JP31.1, R163.1, R182.2, R192.2, U40.7, U42.15, U46.36
ESP_22/SCL4: J48.3, J49.4, J51.9, JP40.1, R213.1, R232.2, R242.2, U52.7, U54.15, U58.36
ESP_22/SCL5: J59.3, J60.4, J62.9, JP49.1, R263.1, R282.2, R292.2, U64.7, U66.15, U70.36
ESP_22/SCL6: J70.3, J71.4, J73.9, JP58.1, R313.1, R332.2, R342.2, U76.7, U78.15, U82.36
ESP_22/SCL7: J81.3, J82.4, J84.9, JP68.1, R363.1, R382.2, R392.2, U88.7, U90.15, U94.36
ESP_23/SD_COPI: J8.6, U5.37
ESP_23/SD_COPI1: J17.6, U22.37
ESP_23/SD_COPI2: J29.6, U34.37
ESP_23/SD_COPI3: J40.6, U46.37
ESP_23/SD_COPI4: J51.6, U58.37
ESP_23/SD_COPI5: J62.6, U70.37
ESP_23/SD_COPI6: J73.6, U82.37
ESP_23/SD_COPI7: J84.6, U94.37
ESP_25/SD_!CS!: J8.5, U5.10
ESP_25/SD_!CS!1: J17.5, U22.10
ESP_25/SD_!CS!2: J29.5, U34.10
ESP_25/SD_!CS!3: J40.5, U46.10
ESP_25/SD_!CS!4: J51.5, U58.10
ESP_25/SD_!CS!5: J62.5, U70.10
ESP_25/SD_!CS!6: J73.5, U82.10
ESP_25/SD_!CS!7: J84.5, U94.10
ESP_26/DAC1: U18.11, U22.11
ESP_26/DAC2: U1.11, U5.11
ESP_26/DAC3: U30.11, U34.11
ESP_26/DAC4: U42.11, U46.11
ESP_26/DAC5: U54.11, U58.11
ESP_26/DAC6: U66.11, U70.11
ESP_26/DAC7: U78.11, U82.11
ESP_26/DAC8: U90.11, U94.11
ESP_27/FAST_OFF: C20.2, Q3.G1, R24.1, U5.12
ESP_27/FAST_OFF1: C49.2, Q4.G1, R65.1, U22.12
ESP_27/FAST_OFF2: C81.2, Q6.G1, R115.1, U34.12
ESP_27/FAST_OFF3: C113.2, Q8.G1, R165.1, U46.12
ESP_27/FAST_OFF4: C145.2, Q10.G1, R215.1, U58.12
ESP_27/FAST_OFF5: C177.2, Q12.G1, R265.1, U70.12
ESP_27/FAST_OFF6: C209.2, Q14.G1, R315.1, U82.12
ESP_27/FAST_OFF7: C241.2, Q16.G1, R365.1, U94.12
ESP_32/RADIO_TXO: J10.11, U5.8
ESP_32/RADIO_TXO1: J21.11, U22.8
ESP_32/RADIO_TXO2: J32.11, U34.8
ESP_32/RADIO_TXO3: J43.11, U46.8
ESP_32/RADIO_TXO4: J54.11, U58.8
ESP_32/RADIO_TXO5: J65.11, U70.8
ESP_32/RADIO_TXO6: J76.11, U82.8
ESP_32/RADIO_TXO7: J87.11, U94.8
ESP_33/RADIO_RXI: J10.10, U5.9
ESP_33/RADIO_RXI1: J21.10, U22.9
ESP_33/RADIO_RXI2: J32.10, U34.9
ESP_33/RADIO_RXI3: J43.10, U46.9
ESP_33/RADIO_RXI4: J54.10, U58.9
ESP_33/RADIO_RXI5: J65.10, U70.9
ESP_33/RADIO_RXI6: J76.10, U82.9
ESP_33/RADIO_RXI7: J87.10, U94.9
ESP_DM: U6.6, U8.3
ESP_DM1: U15.6, U21.3
ESP_DM2: U27.6, U33.3
ESP_DM3: U39.6, U45.3
ESP_DM4: U51.6, U57.3
ESP_DM5: U63.6, U69.3
ESP_DM6: U75.6, U81.3
ESP_DM7: U87.6, U93.3
ESP_DP: U6.5, U8.4
ESP_DP1: U15.5, U21.4
ESP_DP2: U27.5, U33.4
ESP_DP3: U39.5, U45.4
ESP_DP4: U51.5, U57.4
ESP_DP5: U63.5, U69.4
ESP_DP6: U75.5, U81.4
ESP_DP7: U87.5, U93.4
ESP_I34/RADIO_INT: J10.7, U5.6
ESP_I34/RADIO_INT1: J21.7, U22.6
ESP_I34/RADIO_INT2: J32.7, U34.6
ESP_I34/RADIO_INT3: J43.7, U46.6
ESP_I34/RADIO_INT4: J54.7, U58.6
ESP_I34/RADIO_INT5: J65.7, U70.6
ESP_I34/RADIO_INT6: J76.7, U82.6
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

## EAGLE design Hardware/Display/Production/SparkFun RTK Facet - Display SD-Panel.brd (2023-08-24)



Board: 2 copper layers, 119.6 x 193.8 mm, 742 parts (179 on the bottom side), 336 nets.

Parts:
C1, C9, C20, C31, C41, C51, C61, C71, C81, C91, C101, C111, C121, C131, C141, C151: 2.2uF; 0805
C2, C3, C10, C11, C21, C22, C32, C33, C42, C43, C52, C53, C62, C63, C72, C73, C82, C83, C92, C93, C102, C103, C112, C113, C122, C123, C132, C133, C142, C143, C152, C153: 1.0uF; 0805
C4, C6, C7, C12, C14, C15, C23, C25, C26, C34, C36, C37, C44, C46, C47, C54, C56, C57, C64, C66, C67, C74, C76, C77, C84, C86, C87, C94, C96, C97, C104, C106, C107, C114, C116, C117, C124, C126, C127, C134, C136, C137, C144, C146, C147, C154, C156, C157: 1.0uF; 0603
C5, C13, C24, C35, C45, C55, C65, C75, C85, C95, C105, C115, C125, C135, C145, C155: 4.7uF; 1206
C8, C19, C30, C40, C50, C60, C70, C80, C90, C100, C110, C120, C130, C140, C150, C160: 10uF; 0603
C16, C17, C18, C27, C28, C29, C38, C39, C48, C49, C58, C59, C68, C69, C78, C79, C88, C89, C98, C99, C108, C109, C118, C119, C128, C129, C138, C139, C148, C149, C158, C159: 0.1uF; 0603
D1, D2, D3, D4, D5, D6, D7, D8, D9, D10, D11, D12, D13, D14, D15, D16: Green; LED-1206-BOTTOM
E$1, E$2, E$3, E$4: FIDUCIAL-1X2
E$5, E$6: FIDUCIAL-1.5X3
FID1, FID2, FID3, FID4, FID5, FID6, FID7, FID8, FID9, FID10, FID11, FID12, FID13, FID14, FID15, FID16, FID17, FID18, FID19, FID20, FID21, FID22, FID23, FID24, FID25, FID26, FID27, FID28, FID29, FID30, FID31, FID32, FID33, FID34, FID35, FID36, FID37, FID38, FID39, FID40, FID41, FID42, FID43, FID44, FID45, FID46, FID47, FID48, FID49, FID50, FID51, FID52, FID53, FID54, FID55, FID56, FID57, FID58, FID59, FID60, FID61, FID62, FID63, FID64: FIDUCIAL1X2; FIDUCIAL-1X2
J1, J4, J7, J10, J13, J16, J19, J22, J25, J28, J31, J34, J37, J40, J43, J46: FPC_12_0.5MM_BACKFLIP; FPC_12_DOUBLESIDED_BACKFLIP
J2, J5, J8, J11, J14, J17, J20, J23, J26, J29, J32, J35, J38, J41, J44, J47: MICRO-SD-PUSH-PUSH-EXT-PIN; MICROSD-EXTERNALPIN
J3, J6, J9, J12, J15, J18, J21, J24, J27, J30, J33, J36, J39, J42, J45, J48: 1X04_NO_SILK
JP1, JP4, JP6, JP8, JP10, JP12, JP14, JP16, JP18, JP20, JP22, JP24, JP26, JP28, JP30, JP32: FPC_6_1MM-LIF
JP2, JP3, JP5, JP7, JP9, JP11, JP13, JP15, JP17, JP19, JP21, JP23, JP25, JP27, JP29, JP31: JUMPER-SMT_2_NO_SILK; SMT-JUMPER_2_NO_SILK
LOGO1, LOGO3, LOGO4, LOGO7, LOGO9, LOGO11, LOGO13, LOGO15, LOGO17, LOGO19, LOGO21, LOGO23, LOGO25, LOGO27, LOGO29, LOGO31: OSHW-LOGOMINI; OSHW-LOGO-MINI
LOGO2, LOGO5, LOGO6, LOGO8, LOGO10, LOGO12, LOGO14, LOGO16, LOGO18, LOGO20, LOGO22, LOGO24, LOGO26, LOGO28, LOGO30, LOGO32: SFE_LOGO_NAME_FLAME8_MM; SFE_LOGO_NAME_FLAME_8MM
OLED1, OLED2, OLED3, OLED4, OLED5, OLED6, OLED7, OLED8, OLED9, OLED10, OLED11, OLED12, OLED13, OLED14, OLED15, OLED16: OLED0.66; OLED-0.66-64X48
R1, R6, R11, R16, R21, R26, R31, R36, R41, R46, R51, R56, R61, R66, R71, R76: 390k; 0603
R2, R3, R7, R8, R12, R13, R17, R18, R22, R23, R27, R28, R32, R33, R37, R38, R42, R43, R47, R48, R52, R53, R57, R58, R62, R63, R67, R68, R72, R73, R77, R78: 10k; 0603
R4, R9, R14, R19, R24, R29, R34, R39, R44, R49, R54, R59, R64, R69, R74, R79: 100k; 0603
R5, R10, R15, R20, R25, R30, R35, R40, R45, R50, R55, R60, R65, R70, R75, R80: 1k; 0603
S1, S2, S3, S4, S5, S6, S7, S8, S9, S10, S11, S12, S13, S14, S15, S16: MOMENTARY-SWITCH-SPST-SMD-5.2MM-TALL; TACTILE_SWITCH_SMD_5.2MM
U1, U2, U3, U4, U5, U6, U7, U8, U9, U10, U11, U12, U13, U14, U15, U16: LIS2DH12NS; LGA-12-LISDH12-NOSILK
U$1, U$20, U$36, U$52, U$68, U$84, U$100, U$116, U$132, U$148, U$164, U$180, U$196, U$212, U$228, U$244: SD#DIS0
U$2, U$22, U$38, U$54, U$70, U$86, U$102, U$118, U$134, U$150, U$166, U$182, U$198, U$214, U$230, U$246: OVERLAY0
U$3, U$6, U$33, U$49, U$65, U$81, U$97, U$113, U$129, U$145, U$161, U$177, U$193, U$209, U$225, U$241: DISPLAY0
U$4, U$18, U$34, U$50, U$66, U$82, U$98, U$114, U$130, U$146, U$162, U$178, U$194, U$210, U$226, U$242: SD1
U$5, U$28, U$44, U$60, U$76, U$92, U$108, U$124, U$140, U$156, U$172, U$188, U$204, U$220, U$236, U$252: RTK5#SVG0
U$7, U$19, U$35, U$51, U$67, U$83, U$99, U$115, U$131, U$147, U$163, U$179, U$195, U$211, U$227, U$243: #ADR#0
U$8, U$21, U$37, U$53, U$69, U$85, U$101, U$117, U$133, U$149, U$165, U$181, U$197, U$213, U$229, U$245: CHARGE0
U$9, U$23, U$39, U$55, U$71, U$87, U$103, U$119, U$135, U$151, U$167, U$183, U$199, U$215, U$231, U$247: POWER0
U$10, U$24, U$40, U$56, U$72, U$88, U$104, U$120, U$136, U$152, U$168, U$184, U$200, U$216, U$232, U$248: X0
U$11, U$25, U$41, U$57, U$73, U$89, U$105, U$121, U$137, U$153, U$169, U$185, U$201, U$217, U$233, U$249: Y1
U$12, U$26, U$42, U$58, U$74, U$90, U$106, U$122, U$138, U$154, U$170, U$186, U$202, U$218, U$234, U$250: Z2
U$13, U$27, U$43, U$59, U$75, U$91, U$107, U$123, U$139, U$155, U$171, U$187, U$203, U$219, U$235, U$251: RTK_FACET0
U$14, U$29, U$45, U$61, U$77, U$93, U$109, U$125, U$141, U$157, U$173, U$189, U$205, U$221, U$237, U$253: 3V33
U$15, U$30, U$46, U$62, U$78, U$94, U$110, U$126, U$142, U$158, U$174, U$190, U$206, U$222, U$238, U$254: GND2
U$16, U$31, U$47, U$63, U$79, U$95, U$111, U$127, U$143, U$159, U$175, U$191, U$207, U$223, U$239, U$255: SCL0
U$17, U$32, U$48, U$64, U$80, U$96, U$112, U$128, U$144, U$160, U$176, U$192, U$208, U$224, U$240, U$256: SDA1

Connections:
3.3V: C4.1, C6.1, C8.1, C16.1, C28.1, J1.3, J1.4, J2.4, J3.2, OLED1.6, OLED1.8, OLED1.9, R2.1, R3.2, R4.2, U13.2, U13.3, U13.9, U13.10
3.3V1: C12.1, C14.1, C17.1, C18.1, C19.1, J4.3, J4.4, J5.4, J6.2, OLED2.6, OLED2.8, OLED2.9, R7.2, R8.1, R9.2, U1.2, U1.3, U1.9, U1.10
3.3V2: C23.1, C25.1, C27.1, C29.1, C30.1, J7.3, J7.4, J8.4, J9.2, OLED3.6, OLED3.8, OLED3.9, R12.2, R13.1, R14.2, U2.2, U2.3, U2.9, U2.10
3.3V3: C34.1, C36.1, C38.1, C39.1, C40.1, J10.3, J10.4, J11.4, J12.2, OLED4.6, OLED4.8, OLED4.9, R17.2, R18.1, R19.2, U3.2, U3.3, U3.9, U3.10
3.3V4: C44.1, C46.1, C48.1, C49.1, C50.1, J13.3, J13.4, J14.4, J15.2, OLED5.6, OLED5.8, OLED5.9, R22.2, R23.1, R24.2, U4.2, U4.3, U4.9, U4.10
3.3V5: C54.1, C56.1, C58.1, C59.1, C60.1, J16.3, J16.4, J17.4, J18.2, OLED6.6, OLED6.8, OLED6.9, R27.2, R28.1, R29.2, U5.2, U5.3, U5.9, U5.10
3.3V6: C64.1, C66.1, C68.1, C69.1, C70.1, J19.3, J19.4, J20.4, J21.2, OLED7.6, OLED7.8, OLED7.9, R32.2, R33.1, R34.2, U6.2, U6.3, U6.9, U6.10
3.3V7: C74.1, C76.1, C78.1, C79.1, C80.1, J22.3, J22.4, J23.4, J24.2, OLED8.6, OLED8.8, OLED8.9, R37.2, R38.1, R39.2, U7.2, U7.3, U7.9, U7.10
3.3V8: C84.1, C86.1, C88.1, C89.1, C90.1, J25.3, J25.4, J26.4, J27.2, OLED9.6, OLED9.8, OLED9.9, R42.2, R43.1, R44.2, U8.2, U8.3, U8.9, U8.10
3.3V9: C94.1, C96.1, C98.1, C99.1, C100.1, J28.3, J28.4, J29.4, J30.2, OLED10.6, OLED10.8, OLED10.9, R47.2, R48.1, R49.2, U9.2, U9.3, U9.9, U9.10
3.3V10: C104.1, C106.1, C108.1, C109.1, C110.1, J31.3, J31.4, J32.4, J33.2, OLED11.6, OLED11.8, OLED11.9, R52.2, R53.1, R54.2, U10.2, U10.3, U10.9, U10.10
3.3V11: C114.1, C116.1, C118.1, C119.1, C120.1, J34.3, J34.4, J35.4, J36.2, OLED12.6, OLED12.8, OLED12.9, R57.2, R58.1, R59.2, U11.2, U11.3, U11.9, U11.10
3.3V12: C124.1, C126.1, C128.1, C129.1, C130.1, J37.3, J37.4, J38.4, J39.2, OLED13.6, OLED13.8, OLED13.9, R62.2, R63.1, R64.2, U12.2, U12.3, U12.9, U12.10
3.3V13: C134.1, C136.1, C138.1, C139.1, C140.1, J40.3, J40.4, J41.4, J42.2, OLED14.6, OLED14.8, OLED14.9, R67.2, R68.1, R69.2, U14.2, U14.3, U14.9, U14.10
3.3V14: C144.1, C146.1, C148.1, C149.1, C150.1, J43.3, J43.4, J44.4, J45.2, OLED15.6, OLED15.8, OLED15.9, R72.2, R73.1, R74.2, U15.2, U15.3, U15.9, U15.10
3.3V15: C154.1, C156.1, C158.1, C159.1, C160.1, J46.3, J46.4, J47.4, J48.2, OLED16.6, OLED16.8, OLED16.9, R77.2, R78.1, R79.2, U16.2, U16.3, U16.9, U16.10
C1P: C2.1, OLED1.4
C1P1: C10.1, OLED2.4
C1P2: C21.1, OLED3.4
C1P3: C32.1, OLED4.4
C1P4: C42.1, OLED5.4
C1P5: C52.1, OLED6.4
C1P6: C62.1, OLED7.4
C1P7: C72.1, OLED8.4
C1P8: C82.1, OLED9.4
C1P9: C92.1, OLED10.4
C1P10: C102.1, OLED11.4
C1P11: C112.1, OLED12.4
C1P12: C122.1, OLED13.4
C1P13: C132.1, OLED14.4
C1P14: C142.1, OLED15.4
C1P15: C152.1, OLED16.4
C2N: C3.2, OLED1.3
C2N1: C11.2, OLED2.3
C2N2: C22.2, OLED3.3
C2N3: C33.2, OLED4.3
C2N4: C43.2, OLED5.3
C2N5: C53.2, OLED6.3
C2N6: C63.2, OLED7.3
C2N7: C73.2, OLED8.3
C2N8: C83.2, OLED9.3
C2N9: C93.2, OLED10.3
C2N10: C103.2, OLED11.3
C2N11: C113.2, OLED12.3
C2N12: C123.2, OLED13.3
C2N13: C133.2, OLED14.3
C2N14: C143.2, OLED15.3
C2N15: C153.2, OLED16.3
CHARGE_LED: D1.C, J1.11, JP1.2
CHARGE_LED1: D2.C, J4.11, JP4.2
CHARGE_LED2: D3.C, J7.11, JP6.2
CHARGE_LED3: D4.C, J10.11, JP8.2
CHARGE_LED4: D5.C, J13.11, JP10.2
CHARGE_LED5: D6.C, J16.11, JP12.2
CHARGE_LED6: D7.C, J19.11, JP14.2
CHARGE_LED7: D8.C, J22.11, JP16.2
CHARGE_LED8: D9.C, J25.11, JP18.2
CHARGE_LED9: D10.C, J28.11, JP20.2
CHARGE_LED10: D11.C, J31.11, JP22.2
CHARGE_LED11: D12.C, J34.11, JP24.2
CHARGE_LED12: D13.C, J37.11, JP26.2
CHARGE_LED13: D14.C, J40.11, JP28.2
CHARGE_LED14: D15.C, J43.11, JP30.2
CHARGE_LED15: D16.C, J46.11, JP32.2
D/C: JP3.2, OLED1.13, R3.1
D/C1: JP2.2, OLED2.13, R7.1
D/C2: JP5.2, OLED3.13, R12.1
D/C3: JP7.2, OLED4.13, R17.1
D/C4: JP9.2, OLED5.13, R22.1
D/C5: JP11.2, OLED6.13, R27.1
D/C6: JP13.2, OLED7.13, R32.1
D/C7: JP15.2, OLED8.13, R37.1
D/C8: JP17.2, OLED9.13, R42.1
D/C9: JP19.2, OLED10.13, R47.1
D/C10: JP21.2, OLED11.13, R52.1
D/C11: JP23.2, OLED12.13, R57.1
D/C12: JP25.2, OLED13.13, R62.1
D/C13: JP27.2, OLED14.13, R67.1
D/C14: JP29.2, OLED15.13, R72.1
D/C15: JP31.2, OLED16.13, R77.1
ESP_21/SDA: J1.10, J3.3, OLED1.17, OLED1.18, U13.4
ESP_21/SDA1: J4.10, J6.3, OLED2.17, OLED2.18, U1.4
ESP_21/SDA2: J7.10, J9.3, OLED3.17, OLED3.18, U2.4
ESP_21/SDA3: J10.10, J12.3, OLED4.17, OLED4.18, U3.4
ESP_21/SDA4: J13.10, J15.3, OLED5.17, OLED5.18, U4.4
ESP_21/SDA5: J16.10, J18.3, OLED6.17, OLED6.18, U5.4
ESP_21/SDA6: J19.10, J21.3, OLED7.17, OLED7.18, U6.4
ESP_21/SDA7: J22.10, J24.3, OLED8.17, OLED8.18, U7.4
ESP_21/SDA8: J25.10, J27.3, OLED9.17, OLED9.18, U8.4
ESP_21/SDA9: J28.10, J30.3, OLED10.17, OLED10.18, U9.4
ESP_21/SDA10: J31.10, J33.3, OLED11.17, OLED11.18, U10.4
ESP_21/SDA11: J34.10, J36.3, OLED12.17, OLED12.18, U11.4
ESP_21/SDA12: J37.10, J39.3, OLED13.17, OLED13.18, U12.4
ESP_21/SDA13: J40.10, J42.3, OLED14.17, OLED14.18, U14.4
ESP_21/SDA14: J43.10, J45.3, OLED15.17, OLED15.18, U15.4
ESP_21/SDA15: J46.10, J48.3, OLED16.17, OLED16.18, U16.4
ESP_22/SCL: J1.9, J3.4, OLED1.16, U13.1
ESP_22/SCL1: J4.9, J6.4, OLED2.16, U1.1
ESP_22/SCL2: J7.9, J9.4, OLED3.16, U2.1
ESP_22/SCL3: J10.9, J12.4, OLED4.16, U3.1
ESP_22/SCL4: J13.9, J15.4, OLED5.16, U4.1
ESP_22/SCL5: J16.9, J18.4, OLED6.16, U5.1
ESP_22/SCL6: J19.9, J21.4, OLED7.16, U6.1
ESP_22/SCL7: J22.9, J24.4, OLED8.16, U7.1
ESP_22/SCL8: J25.9, J27.4, OLED9.16, U8.1
ESP_22/SCL9: J28.9, J30.4, OLED10.16, U9.1
ESP_22/SCL10: J31.9, J33.4, OLED11.16, U10.1
ESP_22/SCL11: J34.9, J36.4, OLED12.16, U11.1
ESP_22/SCL12: J37.9, J39.4, OLED13.16, U12.1
ESP_22/SCL13: J40.9, J42.4, OLED14.16, U14.1
ESP_22/SCL14: J43.9, J45.4, OLED15.16, U15.1
ESP_22/SCL15: J46.9, J48.4, OLED16.16, U16.1
GND: C1.2, C4.2, C5.2, C6.2, C7.2, C8.2, C16.2, C28.2, J1.1, J2.6, J2.9, J2.10, J2.11, J2.12, J2.13, J3.1, JP1.6, JP3.1, OLED1.1, OLED1.7, OLED1.10, OLED1.27, OLED1.28, R1.1, S1.1, U13.5, U13.6, U13.7, U13.8
GND1: C9.2, C12.2, C13.2, C14.2, C15.2, C17.2, C18.2, C19.2, J4.1, J5.6, J5.9, J5.10, J5.11, J5.12, J5.13, J6.1, JP2.1, JP4.6, OLED2.1, OLED2.7, OLED2.10, OLED2.27, OLED2.28, R6.1, S2.1, U1.5, U1.6, U1.7, U1.8
GND2: C20.2, C23.2, C24.2, C25.2, C26.2, C27.2, C29.2, C30.2, J7.1, J8.6, J8.9, J8.10, J8.11, J8.12, J8.13, J9.1, JP5.1, JP6.6, OLED3.1, OLED3.7, OLED3.10, OLED3.27, OLED3.28, R11.1, S3.1, U2.5, U2.6, U2.7, U2.8
GND3: C31.2, C34.2, C35.2, C36.2, C37.2, C38.2, C39.2, C40.2, J10.1, J11.6, J11.9, J11.10, J11.11, J11.12, J11.13, J12.1, JP7.1, JP8.6, OLED4.1, OLED4.7, OLED4.10, OLED4.27, OLED4.28, R16.1, S4.1, U3.5, U3.6, U3.7, U3.8
GND4: C41.2, C44.2, C45.2, C46.2, C47.2, C48.2, C49.2, C50.2, J13.1, J14.6, J14.9, J14.10, J14.11, J14.12, J14.13, J15.1, JP9.1, JP10.6, OLED5.1, OLED5.7, OLED5.10, OLED5.27, OLED5.28, R21.1, S5.1, U4.5, U4.6, U4.7, U4.8
GND5: C51.2, C54.2, C55.2, C56.2, C57.2, C58.2, C59.2, C60.2, J16.1, J17.6, J17.9, J17.10, J17.11, J17.12, J17.13, J18.1, JP11.1, JP12.6, OLED6.1, OLED6.7, OLED6.10, OLED6.27, OLED6.28, R26.1, S6.1, U5.5, U5.6, U5.7, U5.8
GND6: C61.2, C64.2, C65.2, C66.2, C67.2, C68.2, C69.2, C70.2, J19.1, J20.6, J20.9, J20.10, J20.11, J20.12, J20.13, J21.1, JP13.1, JP14.6, OLED7.1, OLED7.7, OLED7.10, OLED7.27, OLED7.28, R31.1, S7.1, U6.5, U6.6, U6.7, U6.8
GND7: C71.2, C74.2, C75.2, C76.2, C77.2, C78.2, C79.2, C80.2, J22.1, J23.6, J23.9, J23.10, J23.11, J23.12, J23.13, J24.1, JP15.1, JP16.6, OLED8.1, OLED8.7, OLED8.10, OLED8.27, OLED8.28, R36.1, S8.1, U7.5, U7.6, U7.7, U7.8
GND8: C81.2, C84.2, C85.2, C86.2, C87.2, C88.2, C89.2, C90.2, J25.1, J26.6, J26.9, J26.10, J26.11, J26.12, J26.13, J27.1, JP17.1, JP18.6, OLED9.1, OLED9.7, OLED9.10, OLED9.27, OLED9.28, R41.1, S9.1, U8.5, U8.6, U8.7, U8.8
GND9: C91.2, C94.2, C95.2, C96.2, C97.2, C98.2, C99.2, C100.2, J28.1, J29.6, J29.9, J29.10, J29.11, J29.12, J29.13, J30.1, JP19.1, JP20.6, OLED10.1, OLED10.7, OLED10.10, OLED10.27, OLED10.28, R46.1, S10.1, U9.5, U9.6, U9.7, U9.8
GND10: C101.2, C104.2, C105.2, C106.2, C107.2, C108.2, C109.2, C110.2, J31.1, J32.6, J32.9, J32.10, J32.11, J32.12, J32.13, J33.1, JP21.1, JP22.6, OLED11.1, OLED11.7, OLED11.10, OLED11.27, OLED11.28, R51.1, S11.1, U10.5, U10.6, U10.7, U10.8
GND11: C111.2, C114.2, C115.2, C116.2, C117.2, C118.2, C119.2, C120.2, J34.1, J35.6, J35.9, J35.10, J35.11, J35.12, J35.13, J36.1, JP23.1, JP24.6, OLED12.1, OLED12.7, OLED12.10, OLED12.27, OLED12.28, R56.1, S12.1, U11.5, U11.6, U11.7, U11.8
GND12: C121.2, C124.2, C125.2, C126.2, C127.2, C128.2, C129.2, C130.2, J37.1, J38.6, J38.9, J38.10, J38.11, J38.12, J38.13, J39.1, JP25.1, JP26.6, OLED13.1, OLED13.7, OLED13.10, OLED13.27, OLED13.28, R61.1, S13.1, U12.5, U12.6, U12.7, U12.8
GND13: C131.2, C134.2, C135.2, C136.2, C137.2, C138.2, C139.2, C140.2, J40.1, J41.6, J41.9, J41.10, J41.11, J41.12, J41.13, J42.1, JP27.1, JP28.6, OLED14.1, OLED14.7, OLED14.10, OLED14.27, OLED14.28, R66.1, S14.1, U14.5, U14.6, U14.7, U14.8
GND14: C141.2, C144.2, C145.2, C146.2, C147.2, C148.2, C149.2, C150.2, J43.1, J44.6, J44.9, J44.10, J44.11, J44.12, J44.13, J45.1, JP29.1, JP30.6, OLED15.1, OLED15.7, OLED15.10, OLED15.27, OLED15.28, R71.1, S15.1, U15.5, U15.6, U15.7, U15.8
GND15: C151.2, C154.2, C155.2, C156.2, C157.2, C158.2, C159.2, C160.2, J46.1, J47.6, J47.9, J47.10, J47.11, J47.12, J47.13, J48.1, JP31.1, JP32.6, OLED16.1, OLED16.7, OLED16.10, OLED16.27, OLED16.28, R76.1, S16.1, U16.5, U16.6, U16.7, U16.8
IREF: OLED1.24, R1.2
IREF1: OLED2.24, R6.2
IREF2: OLED3.24, R11.2
IREF3: OLED4.24, R16.2
IREF4: OLED5.24, R21.2
IREF5: OLED6.24, R26.2
IREF6: OLED7.24, R31.2
IREF7: OLED8.24, R36.2
IREF8: OLED9.24, R41.2
IREF9: OLED10.24, R46.2
IREF10: OLED11.24, R51.2
IREF11: OLED12.24, R56.2
IREF12: OLED13.24, R61.2
IREF13: OLED14.24, R66.2
IREF14: OLED15.24, R71.2
IREF15: OLED16.24, R76.2
unnamed: C3.1, OLED1.2
unnamed: C2.2, OLED1.5
unnamed: D1.A, R5.1
unnamed: C11.1, OLED2.2
unnamed: C10.2, OLED2.5
unnamed: D2.A, R10.1
unnamed: C22.1, OLED3.2
unnamed: C21.2, OLED3.5
unnamed: D3.A, R15.1
unnamed: C33.1, OLED4.2
unnamed: C32.2, OLED4.5
unnamed: D4.A, R20.1
unnamed: C43.1, OLED5.2
unnamed: C42.2, OLED5.5
unnamed: D5.A, R25.1
unnamed: C53.1, OLED6.2
unnamed: C52.2, OLED6.5
unnamed: D6.A, R30.1
unnamed: C63.1, OLED7.2
unnamed: C62.2, OLED7.5
unnamed: D7.A, R35.1
unnamed: C73.1, OLED8.2
unnamed: C72.2, OLED8.5
unnamed: D8.A, R40.1
unnamed: C83.1, OLED9.2
unnamed: C82.2, OLED9.5
unnamed: D9.A, R45.1
unnamed: C93.1, OLED10.2
unnamed: C92.2, OLED10.5
unnamed: D10.A, R50.1
unnamed: C103.1, OLED11.2
unnamed: C102.2, OLED11.5
unnamed: D11.A, R55.1
unnamed: C113.1, OLED12.2
unnamed: C112.2, OLED12.5
unnamed: D12.A, R60.1
unnamed: C123.1, OLED13.2
unnamed: C122.2, OLED13.5
unnamed: D13.A, R65.1
unnamed: C133.1, OLED14.2
unnamed: C132.2, OLED14.5
unnamed: D14.A, R70.1
unnamed: C143.1, OLED15.2
unnamed: C142.2, OLED15.5
unnamed: D15.A, R75.1
unnamed: C153.1, OLED16.2
unnamed: C152.2, OLED16.5
unnamed: D16.A, R80.1
POWER_BTN: J1.2, JP1.5, S1.3
POWER_BTN1: J4.2, JP4.5, S2.3
POWER_BTN2: J7.2, JP6.5, S3.3
POWER_BTN3: J10.2, JP8.5, S4.3
POWER_BTN4: J13.2, JP10.5, S5.3
POWER_BTN5: J16.2, JP12.5, S6.3
POWER_BTN6: J19.2, JP14.5, S7.3
POWER_BTN7: J22.2, JP16.5, S8.3
POWER_BTN8: J25.2, JP18.5, S9.3
POWER_BTN9: J28.2, JP20.5, S10.3
POWER_BTN10: J31.2, JP22.5, S11.3
POWER_BTN11: J34.2, JP24.5, S12.3
POWER_BTN12: J37.2, JP26.5, S13.3
POWER_BTN13: J40.2, JP28.5, S14.3
POWER_BTN14: J43.2, JP30.5, S15.3
POWER_BTN15: J46.2, JP32.5, S16.3
RESET: C7.1, OLED1.12, R2.2
RESET1: C15.1, OLED2.12, R8.2
RESET2: C26.1, OLED3.12, R13.2
RESET3: C37.1, OLED4.12, R18.2
RESET4: C47.1, OLED5.12, R23.2
RESET5: C57.1, OLED6.12, R28.2
RESET6: C67.1, OLED7.12, R33.2
RESET7: C77.1, OLED8.12, R38.2
RESET8: C87.1, OLED9.12, R43.2
RESET9: C97.1, OLED10.12, R48.2
RESET10: C107.1, OLED11.12, R53.2
RESET11: C117.1, OLED12.12, R58.2
RESET12: C127.1, OLED13.12, R63.2
RESET13: C137.1, OLED14.12, R68.2
RESET14: C147.1, OLED15.12, R73.2
RESET15: C157.1, OLED16.12, R78.2
SD_!CS!: J1.5, J2.2, R4.1
SD_!CS!1: J4.5, J5.2, R9.1
SD_!CS!2: J7.5, J8.2, R14.1
SD_!CS!3: J10.5, J11.2, R19.1
SD_!CS!4: J13.5, J14.2, R24.1
SD_!CS!5: J16.5, J17.2, R29.1
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

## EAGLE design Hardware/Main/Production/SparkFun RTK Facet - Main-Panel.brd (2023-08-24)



Board: 4 copper layers, 138.6 x 187.7 mm, 1054 parts (587 on the bottom side), 736 nets.

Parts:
C1, C33, C62, C91, C120, C149, C178, C207: 47pF; 0402
C2, C4, C6, C17, C18, C25, C27, C30, C32, C34, C42, C43, C50, C52, C59, C61, C63, C71, C72, C79, C81, C88, C90, C92, C100, C101, C108, C110, C117, C119, C121, C129, C130, C137, C139, C146, C148, C150, C158, C159, C166, C168, C175, C177, C179, C187, C188, C195, C197, C204, C206, C208, C216, C217, C224, C226: 1.0uF; 0603
C3, C16, C44, C45, C73, C74, C102, C103, C131, C132, C160, C161, C189, C190, C218, C219: 4.7uF; 0603
C5, C7, C8, C11, C12, C13, C15, C21, C22, C23, C24, C26, C28, C29, C31, C35, C37, C38, C39, C41, C46, C48, C49, C51, C55, C56, C57, C58, C60, C64, C66, C67, C68, C70, C75, C77, C78, C80, C84, C85, C86, C87, C89, C93, C95, C96, C97, C99, C104, C106, C107, C109, C113, C114, C115, C116, C118, C122, C124, C125, C126, C128, C133, C135, C136, C138, C142, C143, C144, C145, C147, C151, C153, C154, C155, C157, C162, C164, C165, C167, C171, C172, C173, C174, C176, C180, C182, C183, C184, C186, C191, C193, C194, C196, C200, C201, C202, C203, C205, C209, C211, C212, C213, C215, C220, C222, C223, C225, C229, C230, C231, C232: 0.1uF; 0603
C9, C19, C53, C54, C82, C83, C111, C112, C140, C141, C169, C170, C198, C199, C227, C228: 18pF; 0603
C10, C14, C20, C36, C40, C47, C65, C69, C76, C94, C98, C105, C123, C127, C134, C152, C156, C163, C181, C185, C192, C210, C214, C221: 10uF; 0603
D1, D3, D9, D13, D17, D21, D25, D29: Yellow; LED-0603
D2, D6, D7, D8, D11, D12, D15, D16, D19, D20, D23, D24, D27, D28, D31, D32: 3A/10V/280mV; SOD-323
D4, D5, D10, D14, D18, D22, D26, D30: 250mA/100V; SOD-323
E$1, E$2, E$3, E$4: FIDUCIAL-1X2
E$5, E$6: FIDUCIAL-1.5X3
FB1, FB2, FB3, FB4, FB5, FB6, FB7, FB8: 2.66Ω; 0402-TIGHT
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

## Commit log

2021-02-05 Add 22ohm to USB hub D+/D-.
    [SparkFun RTK Facet - Display SD SIM.brd, SparkFun RTK Facet - Display SD SIM.sch, SparkFun RTK Facet - External Connector.brd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]
2021-02-11 Fix errors on all 3 boards after enclosure review.
    * Flip connector board completely. Mirror connectors.
    * Mirror connector on SD board
    * Move LED above SIM socket
    * Add membrane connector to SD board
    * Remove switch connector from main board
    * Increase width of connector board, 2mm on each side - 54mm wide
    * Move LiPo Connector north as much as possible
    [Button LED Layout RTK Express.sch, SparkFun RTK Facet - Display SD SIM.brd, SparkFun RTK Facet - Display SD SIM.sch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]
2021-02-11 Add ignore. Mvoe hardware files into sub directory.
    [SparkFun RTK Facet - Display SD SIM.brd, SparkFun RTK Facet - Display SD SIM.sch, SparkFun RTK Facet - External Connector.brd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]
2021-02-16 Move display connector to side so overlay connector can be center. Notch PCBs. Add dummy PCB height. Add dummy retention plate.
    [SparkFun RTK Facet - Display SD SIM.brd, SparkFun RTK Facet - External Connector.brd, SparkFun RTK Facet - Main.brd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]
2021-02-16 Adjust top edges for alignment.
    [SparkFun RTK Facet - Display SD SIM.brd, SparkFun RTK Facet - External Connector.brd, SparkFun RTK Facet - Main.brd]
2021-02-22 Update PROD ID on 12 pin connector. Add gerbers for v10.
    [SparkFun RTK Facet - Display SD SIM.GBL, SparkFun RTK Facet - Display SD SIM.GBO, SparkFun RTK Facet - Display SD SIM.GBP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]
2021-02-22 Moved power LED to left side of front display.
    [SparkFun RTK Facet - Display SD SIM.brd]
2021-02-28 Update Retention Plate design as per current Fusion model
    [SparkFun RTK Facet - Retention Plate.brd, SparkFun RTK Facet - Retention Plate.sch]
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2021-05-13 Adding bits for overlay creation
    [Button LED Layout RTK Express.sch, Button Layout RTK Facet.sch]
2021-05-13 Removing duplicate retention plate.
    [SparkFun RTK Facet - Retention Plate.brd, SparkFun RTK Facet - Retention Plate.sch]
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2021-05-13 Add prelim cellular design
    [SparkFun RTK Facet - Cellular.brd, SparkFun RTK Facet - Cellular.sch]
2021-05-14 Move external connectors to button control. Add radio connector. Move ESP32 to VOUT. Move USB to VOUT. Remove USB from I2C.
    [SparkFun RTK Facet - Main.brd, SparkFun RTK Facet - Main.sch]
2021-05-14 Net rename to indicate inputs vs outputs
    [SparkFun RTK Facet - Cellular.brd, SparkFun RTK Facet - Cellular.sch]
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2021-05-14 Move overlay connector further down. Invert overlay connector pins.
    [SparkFun RTK Facet - Display SD SIM.brd, SparkFun RTK Facet - Display SD SIM.sch]
2021-05-14 Move into sub directories
    [SparkFun RTK Facet - Cellular.brd, SparkFun RTK Facet - Cellular.sch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]
2021-05-14 Increase height 2mm to 23. Move OLED connector up 1mm. Move overlay connector down.
    [SparkFun RTK Facet - Display SD SIM.brd]
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2021-05-14 Change to NO jumper for I2C pullups
    [SparkFun RTK Facet - Main.brd, SparkFun RTK Facet - Main.sch]
2021-05-14 Increase external connector board height to 23mm.
    [SparkFun RTK Facet - External Connector.brd]
2021-05-14 Double up 3.3V on cell connector. Create dummy test board.
    [SparkFun RTK Facet - Cellular-Dummy.GBL, SparkFun RTK Facet - Cellular-Dummy.GBO, SparkFun RTK Facet - Cellular-Dummy.GBP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]
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2021-08-30 Change to push push socket on cellular board.
    [SparkFun RTK Facet - Cellular-Dummy.brd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]
2021-08-30 Change to external pins SD socket on display board.
    [SparkFun RTK Facet - Display SD SIM.brd]
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2021-10-01 Add Buzzard text
    [SparkFun RTK Facet - Cellular.brd, SparkFun RTK Facet - Cellular.sch]
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2021-10-05 Add r2 labels (SMA fixes). Restructure folders.
    [Button Layout RTK Facet.sch]
2021-11-22 Reduce Main, Connector, Display, and Cell board widths by 1mm to allow for v-score protrusion.
    [SparkFun RTK Facet - Cellular-Panel.brd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]
2021-12-03 Add revisions to schematics. Add PDFs of schematics.
    [SparkFun RTK Facet - Cellular-Dummy.GBL, SparkFun RTK Facet - Cellular-Dummy.GBO, SparkFun RTK Facet - Cellular-Dummy.GBP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]
2021-12-14 Add Mechanicals
    - Make Directory "Mechanical"
    - Add PDF Drawings
    - Add Fusion Archive
    - Add Meshes and Solid for all parts designed in house
    [Enclosure_Body.3mf, Enclosure_Body.iges, Enclosure_Body.step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]
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2022-01-03 Add panel files for main v12, connector v12, display v14
    [SparkFun RTK Facet - Display SD-Panel.brd, SparkFun RTK Facet - Main-Panel.brd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]
2022-02-24 Extend retention plate length to make it reversible. Add LTE only sticker.
    [SparkFun RTK Facet - Retention Plate.brd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]
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2022-04-11 Change to LIF 6 pin connector, remove GND plane around accel.
    [SparkFun RTK Facet - Display SD-Panel.GBL, SparkFun RTK Facet - Display SD-Panel.GBO, SparkFun RTK Facet - Display SD-Panel.GBP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]
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2022-05-19 Add tCream to LIF connector on display board v15
    [SparkFun RTK Facet - Display SD-Panel.GBL, SparkFun RTK Facet - Display SD-Panel.GBO, SparkFun RTK Facet - Display SD-Panel.GBP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]
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2022-08-30 Add I2C test header to display board - v1.6
    [SparkFun RTK Facet - Display SD-Panel.brd, SparkFun RTK Facet - Display SD.brd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]
2023-08-24 Facet v13: change charger IC FP, discrete 33s, change cream on ESP32.
    [SparkFun RTK Facet - Main-Panel.brd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]
2023-08-24 Remove silk from around the accel FP for DFM.
    [SparkFun RTK Facet - Display SD-Panel.brd, SparkFun RTK Facet - Display SD.brd, SparkFun RTK Facet - Display SD.sch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]
2023-08-24 Remove R1, change charger FP, change 33 discretes, ESP32 DFM paste.
    [SparkFun RTK Facet - Main.brd, SparkFun RTK Facet L-Band - Main.brd, SparkFun RTK Facet L-Band - Main.sch]
2023-08-25 Close jumpers between ZED/NEO. Change resistor IDs to indicate L-Band Direct.
    [SparkFun RTK Facet L-Band - Main.brd, SparkFun RTK Facet L-Band - Main.sch]
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2024-09-26 Fix part number on LIF
    [SparkFun RTK Facet - Display SD.kicad_pcb, SparkFun RTK Facet - Display SD.kicad_sch]
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

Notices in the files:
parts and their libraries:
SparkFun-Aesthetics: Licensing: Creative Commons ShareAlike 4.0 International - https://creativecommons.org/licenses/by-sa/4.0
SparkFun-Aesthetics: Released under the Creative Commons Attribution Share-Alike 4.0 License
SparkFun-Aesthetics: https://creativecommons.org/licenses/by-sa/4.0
